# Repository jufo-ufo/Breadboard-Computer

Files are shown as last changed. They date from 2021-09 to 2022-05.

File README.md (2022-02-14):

# Breadboard-Computer
Let's build a computer from ICs!

## TODO
- [X] Test out NAND vs NOT, AND, OR
- [X] Write specification for V0.4
  - [X] Add Instructionset to "Handbuch"
  - [X] Rework Interrupts
  - [X] I/O specification
  - [X] Update Flags
  - [X] ~~Insert test results~~
- [X] Get familiar with ~~EAGLE/Target3001~~ Kicad/Logisim
- [ ] Build circuit designs

| Part | Logic | Schematic | Layout | Breadboard | Etching | Soldering | Etcher | Documenation | Comment
|---|---|---|---|---|---|---|---|---|---
| Bank | [X] | [X] | [ ] | [ ] | [ ] | [ ] | | [ ] | 
| Bank\_controller | [X] | [X] | [ ] | [ ] | [ ] | [ ] | | [ ] |
| Memory | [X] | [X] | [X] | [ ] | [ ] | [ ] | | [ ] | 
| Register\_File | [X] | [X] | [ ] | [ ] | [ ] | [ ] | | [ ] | 
| ALU | [X] | [X] | [ ] | [ ] | [ ] | [ ] | | [ ] | 
| IV\_Storage | [X] | [ ] | [ ] | [ ] | [ ] | [ ] | | [ ] | 
| Interrupt\_Controller | [ ] | [ ] | [ ] | [ ] | [ ] | [ ] | | [ ] | 
| Timer | [X] | [ ] | [ ] | [ ] | [ ] | [ ] | | [ ] | 
| Freq\_Counter | [X] | [ ] | [ ] | [ ] | [ ] | [ ] | | [ ] | 
| Instruction\_Decoder  | [X] | [ ] | [ ] | [ ] | [ ] | [ ] | | [ ] | 
| IO\_Controller | [ ] | [ ] | [ ] | [ ] | [ ] | [ ] | | [ ] | 
| Activation\_Module | [X] | [X] | [X] | [X] | [ ] x7  | [ ] x7 | | [ ] | 
| Dual\_Register | [X] | [X] | [X] | [X] | [ ] x2  | [ ] x2 | | [ ] | Replacement for BID-Regiser and IR
https://www.youtube.com/watch?v=9aUsTlBjspE

## TODO for Presentation
| Module | Logic | Schematic | Layout | Breaboard | DIY Etching | Soldering | Comment
|---|---|---|---|---|---|---|---
| Activation Module x4 | [X] | [X] | [X] | | | [ ] |
| Register File | [X] | [X] | [ ] | | | [ ] |
| ALU | [X] | [ ] | | [ ] | | |
| Dual Register | [X] | [X] | [X] | | [X] | [ ] |
| Memory | [X] | [X] | [X] | | | [ ] |
| Instruction Decoader | [X] | | | [ ] | | | No Schematic need, due unstable design
| IO-Controller | [X] | | | [ ] | | | No Schematic need, has to be build spontainiously

## Was macht unseren Computer besonders?

- Modular: Die Funktionialiät des Computer kann erweitern werden indem neues einfach eingesteckt wird
- 2 Bus-Architektur: Efficenter
- IO-System sehr vielfältig: bis zu 2^16 IO-Geräte
- Wäre der Laufzeit anpassbares Instruktions Satz (kommt noch)
- Keine Softwareverwaltes Berechtigungs System: Supervisor/Usermode

=> Sehr einfache Anpassbarkeit und Optimierung auf Verschieden Zenarien

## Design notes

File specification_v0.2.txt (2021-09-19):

================ Register ================

0 : ZERO : Contains const 0x0
1 : IP   : Current Address for instruction to be executed
2 : SP   : Address to the to of the Stack
3 : A    : General purpose
4 : B    :      ...
5 : C    :      ...
6 : D    :      ...
7 : FLAG : Stores the flags

================ Memory  ================

Data Length    : 16 bit
Address Length : 16 bit

 w (word)      = 2  B (byte)
kw (kilo word) = 2 kB (kilo byte)

                     Size:
0x0000 +-------------+
       | ROM         |  16384 w = 16.0 kw
       |             |
       | Supervisor  |
0x4000 +-------------+
       | RAM         |  18431 w = 18.4 kw
       | (Bank 1)    |
       | INS         |
       | 0x4800      |
       |          /\ |   
       | STACK    || |
0x5800 +-------------+
       | RAM         |  18431 w = 18.4 kw
       | (Bank 2)    |
       |             |
       | Optional    |
       | Data        |
0xd000 +-------------+
       | RAM         |  12287  w = 12.3 kw
       | Supervisor  |
       |             |  
       |          /\ |
       | STACK    || |
0xffff +-------------+

================ flags ================

The flags are stored in the FLAG Register
Every Flag corresponds to one flag

 0 : Overflow (of)   : set if an calculation results in an intager overflow
 1 : Equale (e)      : set if both input values to TEST are the same
 2 : Greater (g)     : set if the first value to TEST is greate then the second value
 3 : Smaller (s)     : set if the first value to TEST is smaller then the second value
 4 : IO-Pluged (p)   : set if the first value  to TEST is an pluged in IO-Devices
 5 : Supervisor (sop) : set if supervisor mode is enable
 6 :
 7 :
 8 :
 9 :
10 : 
11 :
12 :
13 :
14 :
15 :

================ Input & Output ================

There are two function for IO Manipulation:
IN  : for reading data from an IO devices
OUT : for writing data to an IO devices

Every IO - Devices has an IO-ID
This IO-ID works like an address for memory

An maps as follows:

       +----------------------------+
0x0000 | 1. IN  : IO-ID             | 
       | 2. OUT : Type of IO-Device |
       +----------------------------+
0x0001 | Interrupt Source           |
       +----------------------------+
0x0002 | Interrupt ID               |
       +----------------------------+
       | Every exsiting IO-Device   |
0xffff +----------------------------+

Slot 0 maps to IO-ID 0x0003
Slot 1 maps to IO-ID 0x0004
 ...
Slot n maps to IO-ID n+3

There exsists a flag if an device is pluged in

================ Interupts ================

On Interupt the Supervisor flag is set and the processor executes the instruction at IV.
After that the processor executes at the position of IP.

IV is set by physikal dip-switches on the processor cases. It's advives to set the IV to
0x3fff and put there an CALL instruction to preserv the old IP

Interupts can be trigger
	- by IO-Devices
	- by INT Instruction

By Reading from IO-ID 0x0001 the source of the interrupt can be optainted.
And Interrupt Sourece of 0x0000 means the interrupt was cause by an INT instruction
Any Interrupt Source higher then 0x0002 means that the interrupt was cause by the
corresponding IO - Devices

================ Instruction Set ================

NOP : No operatation

------ ALU ------
MOV  <reg> <reg/const>       : Move
ADD  <reg> <reg> <reg/const> : Add
SUB  <reg> <reg> <reg/const> : Subtracted
MUL? <reg> <reg> <reg/const> : Mulitply
DIV? <reg> <reg> <reg/const> : Divide
XOR  <reg> <reg> <reg/const> : Bitwise Exclusive Or
AND  <reg> <reg> <reg/const> : Bitwise And
OR   <reg> <reg> <reg/const> : Bitwise Or
NOT  <reg> <reg>             : Bitwise Not

------ Memory ------
STR  <reg (data)> <reg/const (addr)> : Store to Memory
LD   <reg (data)> <reg/const (addr)> : Load from Memory
BNK1 <reg/const>                     : maps Bank Slot 1 to BID
BNK2 <reg/const>                     : maps Bank Slot 2 to BID
------ Stack -------
PUSH <reg/const> : push one value to stack
POP  <reg>       : remove value from stack
PEEK <reg>       : get value from stack without removing it
CALL <reg/const> : push current PC to stack and jump to address
RET              : remove value from stack and jump to it

------- Conditional ------
TEST <reg> <reg/const> : Comparse two values and sets/unsets flags
JE   <reg/const>       : jump if flag equal is set
JO   <reg/const>       : jump if flag overflow is set
JG   <reg/const>       : jump if flag greater is set
JS   <reg/const>       : jump if flag smaller is set
JP   <reg/const>       : jump if flag IO-Pluged is set

For evey conditional jump there is an inverted form
by setting one bit and adding an N in the instruct like
JNE = Jump if flag equal is not set

------- IO -------
IN  <reg/const (data)> <reg (IO-ID)> : Reads value from IO-Devices
OUT <reg/const (data)> <reg (IO-ID)> : Writes value to IO-Devices
IM  <reg/const (data)> <reg (IO-ID)> : Reads value from IO-Devices to Memory 
OM  <reg/const (data)> <reg (IO-ID)> : Write value from Memory to IO-Devices

------- Intreupts ------
INT : Triggers an Interupt

================ Instruction Encoding ================

reg   :  3 bit x 2
const : 16 bit
ins   : 10 bit
----------------
total : 32 (max)   

+-----+-----+-------+-------+-------+--------+
| ins | rcm | reg1  | reg2  | reg3  | Empty  |
| 0-8 |   9 | 10-12 | 13-15 | 16-18 | 19-31  |
+-----+-----+-------+-------+-------+--------+
                            |      const     |
                            |      16-31     |
                            +----------------+

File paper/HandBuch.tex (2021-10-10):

\documentclass{scrartcl}

\usepackage{graphicx}
\usepackage[siunitx, RPvoltages, european]{circuitikz}

\usepackage[ngerman]{babel}
\usepackage[utf8]{inputenc}
\usepackage{amsmath}
\usepackage[T1]{fontenc}
\usepackage{xcolor}
\usepackage{tikz}
\usepackage[breaklinks=true]{hyperref}
\usepackage[utf8]{inputenc}
\usepackage[babel,german=quotes]{csquotes}
\usepackage[style=numeric, backend=biber]{biblatex}
\usepackage{listings}
\usepackage{bytefield}
\usepackage{longtable}

\lstdefinestyle{asm}{
}

\addbibresource{ref.bib}

\graphicspath{ {../images} }

\KOMAoptions{parskip=full}

\begin{document}

\title{Platinencomputer - Handbuch}
\author{Alexander Wersching und Simon Walter}
\date{2021}
\maketitle
\newpage

\tableofcontents
\newpage

\section{Anforderungen und Methode}

\section{Spezifikation des Computers}
Eine Computer hat eine Reihe verschiedener high-level Aufgaben und Features, die es ihm erlauben seiner Tätigkeiten nach zu gehen! 
Diese Features können wie folgt auf gegliedert werden: Register, Memory, Banking, Input/Output, Flaggen, Hardware Stack, Interrupts, Supervisor-Mode und das Instructuion Set.

Aber um zuerst ein paar Standarts festzulegen: der Computer hat eine Daten/Adressen Länge von 16 bit, d.h. er kann maximal 16 bit auf einmal operieren bzw. können maximal 16 bit an Daten/Adressen im Computer auf einmal bewegt werden. Mehr dazu in \autoref{section:comment:datalength}

\subsection{Registers}
Register sind kleine sehr schnelle Speichereinheiten, die genutzt werden können um Zwischenergebnisse, lokal Variablen, Argumenten für Funktionen zu speichern oder um Daten im Computer zwischen den einzelnen Komponenten zu verschieben. Aus jedem Register kann \emph{gelesen} (\emph{Kopierten} des alten Wertes an eine anderen Ort) oder \emph{geschrieben} werden (den alten Wert mit einem neuen Wert \emph{überschreiben})

Der Computers besitzt bei uns $8$ verschiedene, jeweils $16$ bit lange Register. Jedes Register hat dabei eine eigene Registernumber (= RN). Machen Register erfüllen zudem noch spezielle Aufgaben und sollten auch nur so verwendet werden. Diese Funktionen sind in \autoref{table:register} zu sehen.

Mehr zur Registeranzahl in \autoref{section:comment:register_number}

\begin{center}
	\begin{table}[h]
		\caption{\label{table:register} Registeraufteilung}
		\begin{tabular}{l | l | l}
			RN & Name & Funktion\\
			\hline
			$0$ & ZERO & Konstante $0\text{x}0000$; Schreiben hat keinen Effekt\\
			$1$ & IP & Instruction Pointer, zeigt auf aktuell auszuführende Instruktion\\
			$2$ & SP & Stack Pointer, zeigt auf obersten Wert des Stacks, siehe \ref{section:stack} \\
			$3$ & A & Allzweck Register ohne besonderen Aufgaben \\
			$4$ & B & " \\
			$5$ & C & " \\
			$6$ & D & " \\
			$7$ & FLAG & Enthält alle wichtigen Flaggen, siehe \autoref{section:flags} \\
		\end{tabular}
	\end{table}
\end{center}

Die Register A-D sind dabei die Register, welche frei für jede Nutzung zur Verfügung stehen. Es ist \emph{stark zu empfehlen} die spezialregister (ZERO, IP, SP und FLAG) \emph{nicht} für die Speicherung von Daten zu verwenden, da dies evt. Programmabläufe stark stören könnte. Sie sind ausdrücklich nur für ihre zugewiesenen Aufgaben da.

\subsubsection{\label{section:flags}Flaggen}

Das Register FLAG enthält alle Statusflaggen. Eine Flagge kann entweder gesetzt oder nicht gesetzt sein, daher kann jede Flagge als ein Bit repräsentiert werden. Jedes Bit in FLAG stellt daher eine Flagge da. Flaggen werden bei unterschiedlichen Ereignissen geschaltet. Dies und welche Flaggen es gibt ist in \autoref{table:flag} zusehen

\begin{center}
	\begin{table}[h]
		\caption{\label{table:flag}Flaggenaufteilung in FLAG}
		\begin{tabular}{l | l | l | l}
			Bit & Name & Funktion & Schaltung \\
			\hline
			 0 & OF  & Intager Overflow einer Rechenoperation & Bei jeder ALU Operation\\
			 1 & E   & Gleichheit zweier Werte & TEST arg[0] = arg[1]\\
			 2 & G   & Ungleicheit ($>$) zweier Werte & TEST arg[0] > arg[1]\\
			 3 & L   & Ungleicheit ($<$) zweier Werte & TEST arg[0] < arg[0]\\
			 4 &  &  &  \\
			 5 &  &  &  \\
			 6 &  &  &  \\
			 7 &  &  &  \\
			 8 &  &  &  \\
			 9 &  &  &  \\
			10 &  &  &  \\
			11 &  &  &  \\
			12 &  &  &  \\
			13 &  &  &  \\
			14 &  &  &  \\
			15 & OINT & Overwride Interruption, siehe \autoref{section:interrupts} &  \\
			15 & SUP & Supervisor-/Usermode & siehe \autoref{section:interrupts} 
		\end{tabular}
	\end{table}
\end{center}

Alle Flaggen, die mit TEST als Schaltung gekennzeichnet werden, werden bei der Ausführung der TEST Operation geschaltet.

Das FLAG Register verhält sich ebenfalls wie ein Register, daher können Flagge auch per Hand gesetzt oder nicht gesetzt werden. Eine Ausnahme macht SUP die nur manuel geschaltet werden kann wenn SUP gesetzt ist, siehe \autoref{section:supervisor}

\subsection{\label{section:memory}Memory}

Während die Register für lokale Variablen und Zwischenergebnisse gedacht sind, ist Memory (Arbeitsspeicher) für die Speicherung von größeren Datenmengen gedacht.

Es ist in 65536 einzelne und unabhängige Speicherzellen (Jede 16 bit große) aufgeteilt. Jeder Zelle ist einer Addresse, welche von 0 bis 65535 reicht, zugeordnet. Der Computer kann damit auf $65536 \text{words}$ oder $131072 \text{bytes}$ ($\approx 131.0 \text{kb}$) gleichzeitig zugreifen.
\footnote{Die Größe messen wir in words (w) oder in kilowords (kw), wobei $1 \text{word} = 2 \text{bytes} = 16 \text{bit}$.}. Wichtig ist das die Gesamt Größe theoretisch weitaus größer sein kann, dank Banking siehe \autoref{section:banking}.

Memory wird dabei über LD- und STR-Instruktionen gesteuert. Die LD-Instruktion kopiert einen Wert aus Memory und schreibt ihn in ein Register, während STR an der angebenen Addresse den Wert mit dem eines Register überschreibt.

Dabei ist die Memory Karte in \autoref{fig:memoryMap} zu stehen. Die zwei Hardware Stacks sind dort gekenzeichnet mit $\uparrow$, mehr dazu in \autoref{section:stack}

Die mit Supervisor gekennzeichneten Bereich können nur dann gelesen oder geschrieben werden, wenn die SUP Flagge gesetzt ist. Der Bereich, der mit ROM versehen wurde, ist dabei nicht beschreibbar, sondern kann nur gelesen werden. Eine STR Instruktion hat keine Wirkung.

\begin{figure}[h]
	\centering
	\caption{Memory Karte}
	\label{fig:memoryMap}
	\begin{bytefield}[leftcurly=., rightcurly=., leftcurlyspace=0pt, rightcurlyspace=0pt]{16}
		
		\begin{leftwordgroup}{\small \texttt{0x0000}}
			\bitbox[lrt]{16}{}
		\end{leftwordgroup}\\
		\wordbox[lr]{2}{ROM Supervisor\\$16384 \text{w} \approx 16.3 \text{kw}$} \\
		\begin{leftwordgroup}{\small \texttt{0x3fff}}
			\bitbox[lr]{16}{}
		\end{leftwordgroup}\\

		\begin{leftwordgroup}{\small \texttt{0x4000}}
			\bitbox[lrt]{16}{}
		\end{leftwordgroup}\\
		\begin{rightwordgroup}{\large $\uparrow$ User Stack}
			\wordbox[lr]{3}{RAM (Bank Slot 1)\\$18431 \text{w} \approx 18.4 \text{kw}$} \\
		\end{rightwordgroup}
		\begin{leftwordgroup}{\small \texttt{0x57ff}}
			\bitbox[lr]{16}{}
		\end{leftwordgroup}\\

		\begin{leftwordgroup}{\small \texttt{0x5800}}
			\bitbox[lrt]{16}{}
		\end{leftwordgroup}\\
		\wordbox[lr]{3}{RAM (Bank Slot 2)\\$18431 \text{w} \approx 18.4 \text{kw}$} \\
		\begin{leftwordgroup}{\small \texttt{0xcfff}}
			\bitbox[lr]{16}{}
		\end{leftwordgroup}\\

		\begin{leftwordgroup}{\small \texttt{0xd000}}
			\bitbox[lrt]{16}{}
		\end{leftwordgroup}\\
		\begin{rightwordgroup}{\large $\uparrow$ Supervisor Stack}
			\wordbox[lr]{2}{RAM Supervisor\\$12287 \text{w} \approx 12.3 \text{kw}$} \\
		\end{rightwordgroup}
		\begin{leftwordgroup}{\small \texttt{0xffff}}
			\bitbox[lrb]{16}{}
		\end{leftwordgroup}

	\end{bytefield}
	
\end{figure}

\subsubsection{\label{section:banking}Banking}

Banken sind externe Memory Module, die eingesteckt werden können. Alle Banken sind gleich groß ($~18.4\text{kw} = 36.8\text{kb}$) und der Computer unterstützt maximal $65536$ unterschiedliche Banken. Jede Bank hat dabei eine ID (BID), die von $0$ bis $65535$ reicht.

Der Computer hat zwei Bank-Slots (Slot 1 \texttt{0x4000 - 0x3fff} und Slot 2 \texttt{0x4000 - 0x57ff}). Er kann nun auf jenden dieser Slots eine der theoretisch $65536$ Bank legen
\footnote{Es ist dabei möglich die gleiche Bank auf beide Slots zu legen, auch wenn das nur bedingt nützlich ist.}. Das Banken legen lässt sich über die SBK1- (Select Bank 1) und SBK2- (Select Bank 2) Instruktion erreichen.
Wenn man somit an diese entsprechende Memory Addressen schreibt, schreibt man in die Bank hinein.

Durch dieses System lassen sich $65536 * ~18.4\text{kw} = 1.2\text{Gw} = 2.4\text{GB}$ ansprechen.

Das Bankensystem dient zudem dazu Prozesse von einander zu isolieren, da bei nicht gesetzter SUP-Flagge Computer die Bank nicht änderen kann, siehe \autoref{section:supervisor}.

\subsubsection{\label{section:stack}Hardware Stack}

Der Stack (oder auch Stapelspeicher) ist eine LIFO (Last In First Out) Datenstruktur. Sie dient hauptsächlich dazu Subroutinen zu verwalten. 

Er funktioniert dabei wie ein Münztappel. Es kann ein Wert auf den Stack gelegt werden (PUSH-Instruktion) oder ein Wert von oben abgehoben werden (POP-Instruktion).

Der Stack liegt dabei physisch in Memory vor. Jedes Element des Stacks okkupiert dabei eine Memoryzelle. Das Stack-Point Register-(SP) hält die Addresse, welche auf den oberste Wert des Stacks zeigt. Der Stack wächst dabei von hohen Addressen zu niedrigen Addressen. PUSH entspricht dabei der Dekrementierung des Stack Pointers um $1$ und POP der Inkrementierung um $1$.

Fundamental hat der Computer zwei Stacks. Der Supervisor-Stack beginnt bei \texttt{0xffff} und wird genutzt wenn die SUP Flagge gesetzt ist. Der User-Stack beginnt bei \texttt{0x57ff}, also am Ende des Bank-Slots 1 und wird genutzt, wenn die SUP Flagge nicht gesetzt ist.

POP und PUSH schalten automatisch zwischen Supervisor-Stack und User-Stack bei Änderung der SUP-Flagge.

\subsection{\label{section:io}Input/Output}

Der Computer hat zudem die Möglichkeit mit verschieden IO-Geräte zu interagieren.
Die Komunikation läuft über die sogenannten IO-Ports.
Der Computer hat physische Anschlüsse an denen IO-Geräte angesteckt werden können.
Die Struktur dieser Anschlüsse sieht wir folgt aus:

\begin{center}
	\begin{table}[h]
		\caption{\label{table:IOPins}}
		\begin{tabular}{l | l}
			\# & Funktion \\
			\hline
			00 & GND \\
			01 & Vcc \\
			02-17 & 16Bit Daten \\
			18 & Iin-Enable \\
			19 & Din-Enable \\
			20 & Dout-Enable \\
			21 & Clock
 		\end{tabular}
	\end{table}
\end{center}

Dabei bekommt jedes IO-Gerät eine eigene ID (IO-ID), welche im Bereich von $0$ bis $65535$ liegen darf, wobei davon aufgrund von physikalischen beschränkungen vermutlich nur die ersten -zig verwendet werden.
Die Interaktion funktioniert dabei über drei Instruktionen:

\begin{center}
	\begin{table}[h]
		\caption{\label{table:IOInstructions}}
		\begin{tabular}{r | r | l}
			kurzform & Ausgeschrieben & funktion \\
			\hline
			Iin & Instruktion Eingang & Computer schreibt eine Instruktion ans I/O-Gerät \\
			Din & Daten Eingang & Computer schreibt 16-Bit Daten ans I/O-Gerät \\
			Dout &  Daten Output & Computer liest 16-Bit Daten vom I/O-Gerät
 		\end{tabular}
	\end{table}
\end{center}

Jede Interaktion benötigt dabei mehrere Schritte, die genaue Definition der Kommunikationsschritte wird dabei durch jede instruktion eigen festgelegt.
Ein allgemeiner standart Ablauf (wie z.B. der der später definierten IO-Instruktion "rmn") sieht wir folgt aus:

\begin{center}
	\begin{table}[h]
		\caption{\label{table:IO_Schem}}
		\begin{tabular}{l | l | l | l | l | l | l}
			 Bereich & Instr 1 & Instr 2 & ... & Instr n & Instr $n+1$ & ... \\
			\hline
			Iin & 1 & 0 &   & 0 & \\
			Din & 0 & 1 &   & 0 & \\
			Dout & 0 & 0 &   & 1 & \\
			Data$0-7$ & InstructionID & Variable &   & Rückgabewert & Rückgabewert \\
			Data$8-15$ & 8b Variable & Variable &   & Rückgabewert & Rückgabewert
 		\end{tabular}
	\end{table}
\end{center}

Die Pins Iin und Din werden dabei durch den Computer für einen Clock-Tick gesetzt, sobald die Daten/Instruktionsinformationen am Dateneingang an liegen; der Dout Pin wird durch das I/O-Gerät selbst gesetzt, sobald dieses seinerseits die Rückgabeinformation auf die Daten-pins anlegt.
Das setzen des Dout-pins wird vom Computer als Interupt( \autoref{section:interrupts}) bearbeitet.
Der fall, dass gleichzeitig der Computer und das I/O-Gerät die Datenpins versuchen zu beschreiben wird dadurch gelöst, dass meinstens die instruktionen definieren, wann das I/O-Gerät schreiben darf. Bei geräten, wie z.B. Peripherie-Geräten, die standartmäßig schreiben dürfen sollen ist von dem I/O-Gerät der Dout-pin schon eine Instruktion vor beginn des beschreibens des auf den Daten-pins zu setzen.

Berechtigungen: der Supervisor-mode hat die berechtigungen zu allen I/O-Interaktionen, für normale prozesse wird die Berechtigungsliste in einer reihe an RAM-chips gespeichert, deren Addressen sich mit dem wechseln zwischen den verschiedenen Banks ändern.
gesetzt werden können sie nur durch den Supervisor, wobei auch dieser die RAM-Addressen nicht manuel ändern kann (\autoref{section:insSet})

die Momentan bestehenden I/O-Instruktionen sind die folgenden, aber diese sind im Programm frei veränderlich, solange das externe Gerät die gleiche Interpretation der Anweisungen hat.

\begin{center}
	\begin{longtable}{p{0.045\textwidth} | p{0.1\textwidth} | p{0.1\textwidth} | p{0.40\textwidth} | p{0.22\textwidth}}[h]
	\kill
		\caption{\label{table:IOins}I/O-Instruktionen}
		\endhead
			ID & Gerätetyp & Name & Funktion & Verhalten \\
			\hline
			 $0\text{x}00$ & All & ls & gibt alle normalen Funktionen des Geräts zurück & Iin; n$*$Dout\\
			\hline
			 $0\text{x}01$ & All  & ll & gibt ALLE (auch die, die man nicht verwenden sollte) Funktionen zurück & Iin(Instruktion); n$*$Dout(Antworten)\\
			\hline
			 $0\text{x}02$ & Drive & rsn (read singel normal) & Lesen eines einzelnen 16-Bit werts von einer 24-Bit Addresse & Iin(Instruktion); Din(Addresse); 1$*$Dout(Antwort) \\
			\hline
			 $0\text{x}03$ & Drive & rmn (read multiple normal) & Lesen einer reihe an 16-Bit werten von 24-Bit Addressen aus & Iin(Instruktion); Din(startAddresse); Din(Länge); n$*$Dout(Antworten) \\
			\hline
			 $0\text{x}04$ & Drive & wsn (write singel normal) & Schreiben eines einzelnen 16-Bit werts von einer 24-Bit Addresse & Iin(Instruktion); Din(Addresse); Din(Daten); Dout(bestätigung) \\
			\hline
			 $0\text{x}05$ & Drive & wmn (write multiple normal) & Schreiben einer reihe an 16-Bit werten an 24-Bit Addressen & Iin(Instruktion); Din(startAddresse); n$*$Din(Daten); Dout(bestätigung) \\
			\hline
			 $0\text{x}06$ & Drive & rsb (singel read big) & Lesen eines einzelnen 16-Bit werts von einer 40-Bit Addresse & Iin(Instruktion); Din(Addresse); Din(Addresse); 1$*$Dout(Antwort) \\
			\hline
			 $0\text{x}07$ & Drive & rmb (multiple write big) & Lesen einer reihe an 16-Bit werten von 40-Bit Addressen aus & Iin(Instruktion); Din(startAddresse); Din(startAddresse2); Din(Länge); n$*$Dout(Antworten) \\
			\hline
			 $0\text{x}08$ & Drive & wmb (singel write big) & Schreiben eines einzelnen 16-Bit werts von einer 40-Bit Addresse & Iin(Instruktion); Din(Addresse); Din(Addresse);Din(Daten); 1$*$Dout(bestätigung) \\
			\hline
			 $0\text{x}09$ & Drive & wmb (write multiple big) & Schreiben einer reihe an 16-Bit werten an 40-Bit Addressen & Iin(Instruktion); Din(startAddresse); n$*$Din(Daten); Dout(bestätigung) \\
			\hline
			 $0\text{x}0a$ & Drive & rfn (read file normal) & Lesen einer gesamten Datei (24-bit Namen)  & Iin(Instruction); Din(Name); n$*$Dout(Antwort) \\
			\hline
			 $0\text{x}0b$ & Drive & wfn (write file normal) & Schreiben einer neuen Datei (24-bit Namen) & Iin(instruction); Din(Name); n$*$Din(daten); Dout(bestätigung) \\
			\hline
			 $0\text{x}0c$ & Drive & rfpb (read file-part big) & Lesen eines teils einer Datei (24-bit Namen) & Iin(instruction); Din(Name); 2$*$Din(läge); n$*$Dout(Daten) \\
			\hline
			 $0\text{x}0d$ & Drive & wfpb (write file-part big) & Anhängen von Daten an eine Datei(24-bit Namen) & Iin(instruction); Din(Name); Din(länge); n$*$Din(Daten); Dout(bestätigung) \\
			\hline
			 $0\text{x}0e$ &  & & & \\
			\hline
			 $0\text{x}0f$ &  & & &

	\end{longtable}
\end{center}

\subsection{\label{section:interrupts}Interrupts}

Interrupts sind Unterbrechungen im Programmablauf. Wenn ein Interrupt meldet wird. Wird dieser im nächsten Instruktions-Zyklus bearbeitet. Für diesen Zyklus, wird, je nach Interrupt-Quelle, nicht die Instruktion ander Stelle von IP sondern von IV (Interrupt Vektor) geladen.

Alle Interrupts werden blockiert wenn die OINT Flagge gesetzt ist. Blockiert heißt dabei das alle Interrupts nicht behandelt werden. Diese Flagge kann nur gesetzt werden wenn sicher der Computer im Supervisormode befindet.

Wir unterscheiden dabei zwischen drei verschiedenen Interrupt-Quelle, wobei jede Quelle einen eigenen IV hat, wie in \autoref{table:iv}

\begin{center}	
	\begin{table}[h]
		\caption{\label{table:iv}}
		\begin{tabular}{l | l l}
			Interrupt-Quelle & IV Name & IV Standard Wert \\
			\hline
			IO-Interrupts & IV-IO & $0\texttt{x}0000$ \\
			INT-Instruktion & IV-INT & $0\texttt{x}0000$ \\
			Timed-Interrupts & IV-TI & $0\texttt{x}0000$ \\
		\end{tabular}
	\end{table}
\end{center}

\subsubsection{Timed-Interrupts}

Der Timed-Intrrupt funktioniert wie ein Wecker. Nachdem Ausführen der STI (Set Timed Interrupt) Instruktion, wird nach angebender Anzahl an ausgeführten Instruktion ein Intrrupt ausgelöst. So 
würde \texttt{STI 0x00ff} in 256 Instruktion einen Interrupt auslösen. Wenn ein Timed-Interrupt mit der Zeit \texttt{0x0000} gesetzt wird, so wird der Timed-Intrrupt deaktiviert.

\subsubsection{IO-Interrupts}

\subsection{\label{section:supervisor}Supervisor-/Usermode}

REWORK

\subsection{\label{section:insSet}Instruktions-Satz}

Alle zuverfügenung stehenden Instruktion sind in \autoref{table:instructions}. Die Ins-ID, steht für Instruktions-ID, welecher jeder Instruktion eine zugeordnet ist. op1, op2 und op3 sind dabei die möglich parameter der Instruktion. Sie können dabei Register (reg1, reg2 oder reg3) sein oder ein Konstante (c).

\begin{center}
	\begin{table*}
		\caption{\label{table:instructions}Instruktions-Satz}
		\begin{tabular}{l | l l l l | l}
			Ins-ID & Name & op1 & op2 & op3 & Beschreibung \\
			\hline
			\texttt{0x00} & NOP  &  &  &  & Kein Effekt  \\
			\hline
			\texttt{0x01} & MOV  & reg1 & reg2/c &  & reg1 $=$ reg2/c\\
			\texttt{0x02} & ADD  & reg1 & reg2 & reg3/c & reg1 $=$ reg2 $+$ reg3/c \\
			\texttt{0x03} & SUB  & reg1 & reg2 & reg3/c & reg1 $=$ reg2 $-$ reg3/c \\
			\texttt{0x04} & MUL? & reg1 & reg2 & reg3/c & reg1 $=$ reg2 $*$ reg3/c \\
			\texttt{0x05} & DIV? & reg1 & reg2 & reg3/c & reg1 $=$ reg2 $/$ reg3/c \\
			\texttt{0x06} & XOR  & reg1 & reg2 & reg3/c & reg1 $=$ reg2 $\oplus$ reg3/c \\
			\texttt{0x07} & AND  & reg1 & reg2 & reg3/c & reg1 $=$ reg2 $\land$ reg3/c \\
			\texttt{0x08} & OR   & reg1 & reg2 & reg3/c & reg1 $=$ reg2 $\lor$ reg3/c \\
			\texttt{0x09} & NOT  & reg1 & reg2/c &      & reg1 $=$ $\lnot$reg2/c \\
			\hline 
			\texttt{0x0a} & STR  & reg1 & reg2 & reg3/c & memory[reg2 + reg3/c] = reg1  \\
			\texttt{0x0b} & LD   & reg1 & reg2 & reg3/c & reg1 = memory[reg2 + reg3/c] \\
			\texttt{0x0c} & BNK1 & reg1/c &  &  & Setzt BID für Bank-Slot1 \\
			\texttt{0x0d} & BNK2 & reg1/c &  &  & Setzt BID für Bank-Slot2 \\
			\hline
			\texttt{0x0e} & PUSH & reg1/c &  &  & SP--; memory[SP] = reg1 \\
			\texttt{0x0f} & POP  & reg1 &  &  & reg1 = memory[SP]; SP++ \\
			\texttt{0x10} & PEEK & reg1 &  &  & reg1 = memory[SP] \\
			\texttt{0x11} & CALL & reg1/c &  &  & \vtop{
				\hbox{\strut memory[SP] = IP; SP++;}
				\hbox{\strut IP = reg1/c}} \\
			\texttt{0x1b} & RET  &  &  &  & IP = memory[SP]; SP++ \\
			\hline
			\texttt{0x12} & TEST & reg1 & reg2/c &  & Vergleicht reg1 und reg2/c \\
			\texttt{0x13} & JE   & reg1/c &  &  & IP = reg1/c if E \\
			\texttt{0x14} & JO   & reg1/c &  &  & IP = reg1/c if O \\
			\texttt{0x15} & JG   & reg1/c &  &  & IP = reg1/c if G \\
			\texttt{0x16} & JL   & reg1/c &  &  & IP = reg1/c if L \\
			\hline
			\texttt{0x17} & IN   & reg1 & reg2 &  & reg1 = IO[reg2] \\
			\texttt{0x18} & OUT  & reg1/c & reg2 &  & IO[reg2] = reg1/c \\
			\texttt{0x19} & AIO  & reg1 &  &  & Aktiviert IO[reg1] \\
			\texttt{0x1a} & DIO  & reg1 &  &  & Deaktivieren IO[reg1] \\
			\texttt{0x1b} & TYPE & reg1 & reg2 &  & reg1 = Type von IO[reg2] \\
			\hline
			\texttt{0x1c} & INT  & & & & Löst einen Interrupt aus \\
			\texttt{0x1d} & STI  & reg1/c & & & Setzt Timed Interrupt für reg1/c \\
			\hline
		\end{tabular}
	\end{table*}
\end{center}

\section{Kommentar zur Specification}

\subsection{\label{section:comment:datalength}16 bit Daten/Address Länge}

Die Address- und Datenlänge besagt viele Binäre Ziffern (bits) für eine Address und Daten verwendet werden. Je mehr Ziffern man verwendet desto größere Zahlen können in einer Operation verarbeitet werden wobei die maximal repräsentierbare Zahle $2^n - 1$ ist wenn $n$ die Anzahl der Binary Ziffern (= Bits) ist und wenn man mit $0$ anfängt zu zählen. Sie \autoref{table:max_zahlen}

Ein eine $n$ stellige Binär Zahl wobei $n$ teilbar durch $8$ ist, ist dabei relative angenehm, $8$ bit = $1$ byte. Das byte ist dabei die Basis Einheit für so gut wie alle informationstechnischen Standards. Daher ist es gute eine solches $n$ zu wählen.
Zudem kommen einige elementar ICs, z.B. Buffer oder Register, immer mit 8 bits.

Jedoch gilt je mehr Bits man verwendet, desto mehr Schaltung brauchen man, desto mehr Stromverbrauch. Da wir wie zwar nicht speziell auf Platz und Stromverbrauch optimieren, aber trozdem ein limitiertes Buget haben, können wir auch nicht eine belibig große Daten/Address Länge wählen.

Wir haben uns daher für $16$ bit entschieden, der Codea man laut \autoref{table:max_zahlen} Zahlen bis zwischen $0$ und $65535$ darstellen kann. Diese Menge ist gerade große genug, um für die meisten Programme große genüge Zahl abzubilden
\footnote{Für Programme die Zahlen welche $> 65535$ darstellen wohlen ist es ratsam immer zwei oder mehr Spreichereinheiten zunehmen oder bei Berechnungen, selbige auf zwei oder mehr Schritte auf zuteilen}.

Die Entscheidung zur größe der Daten/Address Länge ist eine sehr ausschlag gebende, daher haben wir diese zuerst festgelegt. Sie wird für viele weitere Entscheidung eine wichtige Rolle spielen. Wichtig ist nur das wir maximal $65536$ Zustände oder Zahlen von $0$ bis $65535$ darstellen können mit unseren $16$ bit

\begin{center}
	\begin{table}[h]
		\caption{\label{table:max_zahlen} Maximalerepersäntierbare Zahlen (startend mit 0)}
		\begin{tabular}{ l | l }
 		$n$ & $n^2 - 1$ \\
		\hline 
		2 & 3\\  
		4 & 15\\
		8 & 255\\
		16 & 65535\\
 		32 & 4294967295\\
 		64 & 18446744073709551615\\
		\end{tabular}
	\end{table}
\end{center}

\subsection{\label{section:comment:register_number}Register Anzahl}

Der Computer hat 8 Register. Wir haben uns für Acht ausfolgenden Gründen entschieden:
Zu erst die minimale Anzahl anregisteren die wirklich gebraucht würde, ist $5$! Man braucht mindestens zwei all Zweck Register um binäre Rechenoperation durch zu führen, einen Stackpointer, einen Instruktion Point und einen Ort wo man die Flaggen speichern kann
\footnote{Theorthisch ist es möglich das Flaggen Register wegzulassen, wir haben uns aber für eine solches Register entschieden siehe \autoref{com:conditionals}}.

Fünf lässt sich nicht mehr mit $2$ bits repräsentieren ($2^2 = 4$), daher muss man $3$ bit ($2^2 = 8$) nehmen. Der Grund warum wir nicht mehr genomen haben hat mit der Encodierung von Instruktionen zutun siehe \autoref{com:insEnc}. Somit haben sich $8$ Register als das Optimum ergeben

\subsection{\label{com:insEnc}Alternative Instruktion Encodierung}

\section{\label{section:security}}

\section{Quellenverzeichnis}

\printbibliography{}

\end{document}

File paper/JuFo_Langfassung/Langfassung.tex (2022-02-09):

\documentclass{scrartcl}

\usepackage{graphicx}
\usepackage[siunitx, RPvoltages, european]{circuitikz}

\usepackage{chemformula}
\usepackage[ngerman]{babel}
\usepackage[utf8]{inputenc}
\usepackage{amsmath}
\usepackage{amssymb}
\usepackage[T1]{fontenc}
\usepackage{xcolor}
\usepackage{tikz}
\usepackage[breaklinks=true]{hyperref}
\usepackage[babel,german=quotes]{csquotes}
\usepackage[style=numeric, backend=biber]{biblatex}
\usepackage{listings}
\usepackage{bytefield}
\usepackage{longtable}
\usepackage{sidecap}
\usepackage{wrapfig}
\usepackage{subcaption}
%\usepackage{titlesec}

\graphicspath{ {../../images/} }

\KOMAoptions{parskip=full}

\pdfimageresolution=72

%\titlespacing{\section}{8pt}{12pt plus 4pt minus 2pt}{0pt plus 2pt minus 2pt}
%\titlespacing{\subsection}{4pt}{12pt plus 4pt minus 2pt}{0pt plus 2pt minus 2pt}
%\titlespacing{\subsubsection}{2pt}{12pt plus 4pt minus 2pt}{0pt plus 2pt minus 2pt}

\begin{document}

    \title{Platinencomputer - Langfassung}
    \author{Alexander Wersching und Simon Walter}
    \date{2022}
    \maketitle

    \tableofcontents

    \newpage
    \section{Idee}
    \vspace{-15pt}
    Vor ca. 2 Jahren hatte Alex die Idee: Er wolle einen 8-Bit-Computer bauen.
    Die vor 2 Jahren beim Regionalwettbewerb München-West eingereichte Version eines anderen Teilnehmers hat dann auch mein (Simons) Interesse geweckt.
    \newline
    \vspace{-15pt}
        \begin{wrapfigure}{r}{0.5\textwidth}
        \vspace{-25pt}
        \begin{center}
            
        \end{center}
        \vspace{-20pt}
        \end{wrapfigure}
    Ein paar Monate später haben wir uns dann dazu entschieden, tatsächlich einen eigenen 8-Bit-Computer zu bauen und haben auch bald angefangen, erste Versuche auf dem Breadboard zu entwickeln.
    Es gab noch weder eine Möglichkeit diese erste Version automatisch zu betreiben, noch Daten zu schreiben/speichern, oder irgendwie mit der Umgebung zu interagieren, nur 3 Register, 2 Operationen und viele Knöpfe zum Bedienen.

    \section{Nutzen von Platinen}
    \vspace{-15pt}
    \subsection{Warum Platinen?}
    \vspace{-15pt}

        \begin{wrapfigure}{r}{0.4\textwidth}
        \vspace{-40pt}
        \begin{center}
        
        
        \end{center}
        \vspace{-30pt}
        \end{wrapfigure}

    Bald war aber klar, dass ein einfaches Verwenden von flachen Kabeln als Verbindung zwischen den Breadboards, das Kabelgewirr, das wir bei dem Projekt von vor 2 Jahren gesehen haben
    und nach Möglichkeit vermeiden wollten, um ein übersichtlicheres Design zu erreichen, nicht lösen kann.

    Als Alternative für Breadboards haben wir uns für Platinen (PCBs) entschieden.
    Aber weil unser Computer ja nicht mehr wirklich selbst gemacht wäre, wenn wir diese nur professionell ätzen lassen würden,
    wollten wir versuchen - zumindest einen Teil - selbst zu ätzen, auch wenn wir dadurch natürlich auf viele neue Probleme gestoßen sind...

    \newpage

    \subsection{Erste Versuche der Umsetzung}
    \vspace{-15pt}

        \begin{wrapfigure}{l}{0.4\textwidth}
        \vspace{-25pt}
        \begin{center}
         %hier binn ich noch nicht ganz glücklich mit dem Bild
        \end{center}
        \vspace{-20pt}
        \end{wrapfigure}

    Was zu Beginn das Projekt vorangetrieben hat, hat ab diesem Punkt aber natürlich ein Problem dargestellt:
    Das Homeschooling, währenddessen wir natürlich nicht Ätzen können.
    Wir hätten es natürlich zu Hause versuchen können, hatten da aber keine adäquate Ausrüstung v.a. bzgl. Sicherheit.
    Bis wir dann so weit waren, erste Versuche zu machen, war es dann schon Ende 2020.

    Der Herstellungsprozess funktioniert dabei wie folgt:
    \vspace{-10pt}
    \begin{enumerate}
        \item Wir Belichten die Photosensitive Platine mit UV Licht, auf der wir eine mit den Leiterbahnen bedruckte Overheadfolie legen;
        \vspace{-12pt}
        \item Wir legen die Platine - jetzt ohne Folie - in NaOH um die Schutzschicht der Platine an den Belichteten punkten zu lösen;
        \vspace{-12pt}
        \item Als letzten Entwicklungsschritt lösen wir mit FeCl$_3$ das Kupfer ab
        \vspace{-12pt}
        \item Nun werden noch die Entsprechenden Löcher für die THT (Through-hole-technology) Komponenten gebohrt und diese eingelötet
    \end{enumerate}

    \subsection{Design}
    \vspace{-15pt}

        \begin{wrapfigure}{r}{0.65\textwidth}
        \vspace{-40pt}
        \begin{center}
        
        \end{center}
        \caption{Offensichtlich ist das mit unseren aktuell geplanten Modulen: am Boden sitzt eine große Bus-Platine, auf der wir alle Module senkrecht aufstecken.\label{img:design}}
        \vspace{-160pt}
        \end{wrapfigure}

    Nachdem es auch auf geätzten Platinen noch nicht automatisch ordentlich ist und eine derart große Platine für uns nicht machbar gewesen wäre, haben wir uns dann noch ein 3-dimensionales, modulares Design ausgedacht. Dieses ist in \autoref{img:design}

        %\newline
        %\newline
        %\newline

    \newpage
    \section{Anforderungen}
    \vspace{-15pt}
    Im nächsten Lockdown hatten wir dann wieder viel Zeit zu planen, und der geplante Computer wurde immer komplexer.

    \subsection{Daten- und Adresslänge}
    \vspace{-15pt}

    Aus den ursprünglich geplanten 8-Bit wurden 16-Bit-Daten- und Adresslänge:

        \vspace{-5pt}
        \fbox{%
        \parbox{1\textwidth}{

        Die Daten- und Adresslänge besagt, wie viele binäre Ziffern (Bits) für eine Adresse und Daten verwendet werden.\\
        Je mehr Ziffern man verwendet desto größere Zahlen können in einer Operation verarbeitet werden.
            Dabei ist die maximal repräsentierbare Zahl $2^n - 1$ ist, wenn $n$ die Anzahl der Binären Ziffern (= Bits) ist.\\
        Ein $n$ teilbar durch $8$ zu machen, ist dabei relativ angenehm, weil $8$ Bit = $1$ Byte\\
        und Bytes sind nun mal die Grundlage für das meiste in der Informatik,\\
        zudem kommen einige elementare ICs (Integrated Circuits), z.B. Buffer oder Register, immer mit 8 Bits.\\
        \\
        Jedoch gilt, je mehr Bits man verwendet, desto mehr Schaltungen werden benötigt und desto größer der Stromverbrauch, wodurch es für uns relativ schnell unrealistisch aufwendig wird.\\
        \\
        Wir haben uns daher für $16$ Bit entschieden, womit wir
            Zahlen bis zwischen $0$ und $65535$ darstellen können.\\
        Diese Menge ist gerade groß genug, um Zahlen abzubilden, damit die meisten Programme funktionieren können, aber trotzdem noch auf Platinen handhabbar ist.\\

        }%
        }
        \vspace{0pt}

    \newpage
    \subsection{Memory}
    \vspace{-15pt}
    Für Daten und Programme verwenden wir in unserem Computer ein Modul: Memory-Modul

        \begin{wrapfigure}{r}{0.37\textwidth}
        \vspace{-140pt}
        \begin{center}
        
            \label{img:mem_map}
            \caption{Speicher Aufteilung: Von niederigen zu hohen Addressen in Hexdezimal schreibweiße}
        \end{center}
        \vspace{-20pt}
        \end{wrapfigure}

        \vspace{-5pt}
        \fbox{%
        \parbox{0.6\textwidth}{
        Unser Memory-Modul ist in 65536 einzelne und unabhängige Speicherzellen (jede 16 Bit groß) aufgeteilt. (weil wir genau so viele Adressen in unseren 16 Bit speichen können)\\
        Der Computer kann damit auf $65536 \text{ Words}$ oder $131072 \text{ Bytes}$ ($= 128 \text{ kib}$) direkt zugreifen.\\
        Die Größe messen wir in Words (w) oder in Kilowords (kiw), wobei $1 \text{ Word} = 2 \text{ Bytes} = 16 \text{ Bit}$ sind.\\
        \\
        Memory wird dabei über LD- und STR-Instruktionen gesteuert.\\
        Die LD-Instruktion kopiert einen Wert aus Memory und schreibt ihn in das Ziel-Register, während STR an der angegebenen Adresse den Wert mit dem Wert des Quellen-Register überschreibt.\\

        }
        }
        \vspace{0pt}

    Um aber noch mehr Speicher zu nutzen und das später erwähnte Berechtigungssystem möglichst leicht umsetzen zu können, haben wir noch Banken hinzugefügt:

        \vspace{-5pt}
        \fbox{%
        \parbox{1\textwidth}{
        Banken sind externe Memory Module, die eingesteckt werden können.
        Alle Banken sind gleich groß ($16\text{ kiw} = 32\text{ kib}$) und der Computer unterstützt maximal $65536$ unterschiedliche Banken.
        Jede Bank hat dabei eine ID (BID), die von $0$ bis $65535$ reicht.

        Der Computer hat zwei Bank-Slots (Slot 1 \texttt{0x8000 - 0xbfff} und Slot 2 \texttt{0xc000 - 0xffff}), auf den jeweils eine der Banken gelegt werden kann.
        \newline
        \newline
        Bank-Slot $1$ ist dafür gedacht, dass jeder Prozess dort in seiner eigenen Bank lebt, sodass in dem Prozess absolute Memory Adressen verwendet werden können, weil das Programm immer an der gleichen Stelle liegt.
        Außerdem wird in der Bank auch der Stack des jeweiligen Prozesses gespeichert, sodass dieser von anderen Prozessen nicht überschrieben werden kann.

        Bank-Slot $2$ dient als potentieller zusätzliche Speicher des Prozesses, oder als allgemeiner Speicherort, um zwischen den Prozessen Daten zu übermitteln.

        }%
        }

    \subsection{ROM}
    Um den Computer komplett unabhängig funktionsfähig machen zu können, haben wir uns dann überlegt einen Teil des RAMs (\texttt{0x0000} - \texttt{0xffff}) durch ROM zu ersetzen, um automatisch Programme von einem externen Speichermedium laden zu können. Zusehen in \autoref{img:mem_map}

    \subsection{Instruktionen}
    \vspace{-15pt}
    Um die neuen Möglichkeiten durch 16-Bit auch sinnvoll nutzen zu können, haben wir dann noch viele Logikoperationen und komplexere konditionale Jumps hinzu gefügt:
    Der Computer soll die Grundoperationen: Addition (ADD), Subtraktion (SUB), Multiplikation (MUL), Division (DIV),
    so wie die bitweisen Operationen: Exklusives Oder (XOR), Und (AND), Nicht (NOT) und Oder (OR) beherrschen.

    Der Computer besitzt zudem folgende Instruktion um mit Memory zu interagieren: Laden (LD), Speicher (STR), Bank 1 und
    Bank 2 wechseln (BNK1 und BNK2) und folgende Instruktion um mit dem Hardware Stack zu interagieren: push (PUSH), pop
    (POP), Funktionsaufruf (CALL) und Funktionsrückgabe (RET).

    Zudem die folgenden IO-Instruktionen: Instruktion Send (IOUT), Daten Senden (DOUT), Daten lesen (DIN), IO-Gerät Aktivieren (AIO) und IO-Gerät Deaktivieren

    Aber auch noch folgende Instruktion um Interrupts zu verwalten: Software Interrupt auslösen (INT), Modus des Timers 1 und 2 setzten (TM1/TM2) und die Stop Werte des Timers 1 und 2 setzten (SSTL1/SSTL2/SSTH1/SSTH2)

    Insgesamt hat unser Computer damit folgende Instruktionen: \autoref{table:instructions}

    \vspace{-15pt}
    \begin{center}
        \begin{longtable}{l | l l l l | l}
            \kill
            \caption{\label{table:instructions}Instruktions-Satz}
            \endhead
            Ins-ID & Name & op1 & op2 & op3 & Beschreibung \\
            \hline
            \texttt{0x00} & NOP  &  &  &  & Kein Effekt  \\
            \hline
            \texttt{0x01} & MOV  & reg &  & reg/c & op1 $=$ op3\\
            \texttt{0x02} & ADD  & reg & reg & reg/c & op1 $=$ op2 $+$ op3 \\
            \texttt{0x03} & SUB  & reg & reg & reg/c & op1 $=$ op2 $-$ op3 \\
            \texttt{0x04} & MUL? & reg & reg & reg/c & op1 $=$ op2 $*$ op3 \\
            \texttt{0x05} & MULOF& reg & reg & reg/c & op1 $=$ Overflow op2 $*$ op3 \\
            \texttt{0x05} & DIV? & reg & reg & reg/c & op1 $=$ op2 $/$ op3 \\
            \texttt{0x06} & XOR  & reg & reg & reg/c & op1 $=$ op2 $\oplus$ op3 \\
            \texttt{0x07} & AND  & reg & reg & reg/c & op1 $=$ op2 $\land$ op3 \\
            \texttt{0x08} & OR   & reg & reg & reg/c & op1 $=$ op2 $\lor$ op3 \\
            \texttt{0x09} & NOT  & reg &  & reg/c & op1 $=$ $\lnot$op3 \\
            \hline
            \texttt{0x0a} & STR  &  & reg & reg/c & memory[op3] = op2 \\
            \texttt{0x0b} & LD   & reg & reg & reg/c & op1 = memory[op2 + op3] \\
            \texttt{0x0c} & BNK1 &  &  & reg/c & Setzt BID für Bank-Slot1 \\
            \texttt{0x0d} & BNK2 &  &  & reg/c & Setzt BID für Bank-Slot2 \\
            \hline
            \texttt{0x0e} & PUSH &  &  & reg/c & SP--; memory[SP] = op1 \\
            \texttt{0x0f} & POP  &  &  & reg & op3 = memory[SP]; SP++ \\
            \texttt{0x10} & CALL &  &  & reg/c & \vtop{
				\hbox{\strut memory[SP] = IP; SP++;}
				\hbox{\strut IP = op3}} \\
            \texttt{0x11} & RET  &  &  &  & IP = memory[SP]; SP++ \\
            \hline
            \texttt{0x12} & TEST & reg &  & reg/c & Vergleicht op1 und op3 \\
            \texttt{0x13} & ME   & reg &  & reg/c & op1 = op3 if E \\
            \texttt{0x14} & MG   & reg &  & reg/c & op1 = op3 if G \\
            \texttt{0x15} & ML   & reg &  & reg/c & op1 = op3 if L \\
            \texttt{0x18} & MOFadd  & reg &  & reg/c & op1 = op3 if O \\
            \texttt{0x19} & MOFsub  & reg &  & reg/c & op1 = op3 if O \\
            \hline
            \texttt{0x1a} & IOUT & reg &  & reg/c & IIO[op1] = op3/c \\
            \texttt{0x1b} & DOUT & reg &  & reg/c & DIO[op1] = op3/c \\
            \texttt{0x1c} & DIN  & reg &  & reg & op3 = DIO[op1] \\
            \texttt{0x1d} & AIO  & reg &  &  & Aktiviert IO[op1] \\
            \texttt{0x1e} & DIO  & reg &  &  & Deaktivieren IO[op1] \\
            \hline
            \texttt{0x1f} & INT  & & & & Löst einen Interrupt aus \\
            \texttt{0x20} & TM1  & & & reg/c & Modi Timer1 = op3 \\
            \texttt{0x21} & TM2  & & & reg/c & Modi Timer2 = op3 \\
            \texttt{0x22} & SSTL1 & & & reg/c & erster Stop Timer1 = op3 \\
            \texttt{0x23} & SSTL2 & & & reg/c & zweiter Stop Timer2 = op3 \\
            \texttt{0x24} & SSTH1 & & & reg/c & erster Stop Timer1 = op3 \\
            \texttt{0x25} & SSTH2 & & & reg/c & zweiter Stop Timer2 = op3 \\
            \texttt{0x26} & CFL  & reg & & & op1 = erster Clock Freq \\
            \texttt{0x27} & CFH  & reg & & & op1 = zweiter Clock Freq
        \end{longtable}
    \end{center}

    \subsection{IO-Ports}
    \vspace{-15pt}
    Dazu hat sich die Idee von komplexer IO-Interaktion mit dem Computer ergeben:
    universelle Ports zum Anschließen von Festplatten, Sensoren, einfachen Tastaturen, LCD-Displays oder einer Grafikkarte.

        \vspace{-5pt}
        \fbox{%
        \parbox{1\textwidth}{
        Die theoretisch 65536 Anschlüsse, wobei jedem eine Anschluss-ID zugewiesen ist, kommunizieren mit IO-Geräten über 4 Kommandos,
            die als 4 separate Pins zwischen dem Controller und dem Gerät umgesetzt sind:

        1. Einen Befehl an das IO-Gerät schicken (auf Programm-Ebene);

        2. Daten zu einem vorherigen Befehl an das Gerät schreiben;

        3. Die Anfrage des IO-Gerätes, Daten an den Computer zurück zu schreiben, was bei diesem normalerweise einen Interrupt auslöst;

        4. Bestätigen des Computers, das das Externe Gerät schreiben darf;

        }%
        }

    \subsection{Supervisor-/Usermode}
    \vspace{-15pt}

        Er kann dabei in zwei Modi operieren: dem Supervisormode und Usermode.
        Im Supervisormode kann der Computer alle Funktion ohne Einschränkungen nutzen.
        Im Usermode hingegen ist der Computer in einigen Funktion eingeschränkt.
        Folgendes kann der Computer im Usermode \emph{nicht} machen:

        \begin{itemize}
            \item Setzen der SUP Flagge
            \item Änderung der OINT Flagge
            \item Lesen und/oder schreiben im Bereich von \texttt{0x0000} - \texttt{0x7fff}
            \item Änderung der Banken
            \item Die Modifikation der IO-Berechtigungsliste
            \item Zugriff auf IO-Geräte, welche nicht in der Berechtigungsliste gespeichert sind (siehe \autoref{section:persmissionIO})
        \end{itemize}

    Wir haben uns entschieden eine Art Berechtigungssystem in der Computer einzubauen.
    Eine Rechner der nur einfache Programm ausführt um zu Beispiel eine LED oder ein LCD-Display zu steueren, wie es z.B. ein ESP32 oder ein ATMega328p macht, ist so ein System nicht nötig.
    Wir hatten jedoch vor mit unserem Computer die Möglichkeit zu schaffen ein Betriebssystem ähnliches Programm (Supervisor) laufen zulassen.

    Hierfür hat man ein mal den Supervisor, der bei Start des Computer anfängt zulaufen und Programme, welche im Usermode ausgeführt werden, sogenannte Prozesse, lädt.
    Dabei sieht ein typischer Programmablauf ist dabei in gezeigt.

    Wichtig ist, das sobald ein Prozess beendet wurde, der Supervisor an dieser Stelle wieder anfängt und den nächsten Prozess startet.

    Ein Prozess kann auch Funktionen des Supervisor nutzten über Software Interrupts, da bei einem Interrupt, der Computer in den Supervisormode wechselt.
    So kann der Prozess, bevor er den Interrupt auslegt, ein oder mehrere Register nutzten um Werte an den Supervisor zu übergeben.
    z.B. kann er eine Register nutzten um dem Supervisor zu sagen was er tun soll, z.B. dem Prozess zugang zu einem IO-Gerät zugeben oder etwas in eine Datei zuschreiben.
    Diese Art von Kommunikation werden auch System-Calls genannt und sind die Basis für jedes moderne Betriebssystems.

    Ein solcher Supervisor kann sehr mächtig sein:

    \begin{enumerate}
        \item Abstraktion der Hardware: Oft ist die IO-Configuration von Setup zu Setup sehr verschieden. Ein Prozess welcher IO-Geräte nutzen möchte hat oft den Nachteil dass es für ein bestimmtes Hardware setup geschrieben wurde. So z.B. ein Prozess der Daten einer SD-Karte ausließt und diese anzeigt. Wenn man jedoch jetzt eine Floppy-Laufwerk anschließt, so kann man das Prozess zum Auslesen nicht verwenden, da es nur die Kommuntiation mit einer SD-Karte kennt. Der Supervisor könnte an dieser Stelle ein Interface über System-Calls bieten welches unabhänige von dem Gerät ist. So im diesem Beispiel ein Dateisystem, auf welches Prozesse zugreifen können. Somit übernimmt der Supervisor die Kommuntiation mit der Hardware.

        \item Teilung der Rechenzeit: Der Computer so viele Features er doch hat, ist stark limitiert vor allem was Rechengeschwindigkeit betrifft. Wenn man nun mehrer Programm hat, welche ausgeführt werden sollen, so wäre es natürlich sehr einfach sie der Reihe nach auszuführen. Jedoch gibt es bessere Wege, so z.B. das der Computer jedem Prozess nur eine bestimmte Rechenzeit gibt und dann den nächsten Prozess ausführt. Das kann erreicht werden durch folgenden Ablauf: Der Supervisor stellt vor dem ausführen des Prozesse eine Timed-Interrupt. Dann übergibt der Supervisor den Computer dem Prozess, welcher dann seine Programm ausführt. Dies machter bis der Timed-Interrupt ausgelöst wird und der Computer wieder in den Supervisormode wechselt. Dieser speichert nun alle Register und Banken Configuration des Prozesse und übergibt einem anderen Prozesse den Computer. Wenn nun ein schon angefanger Prozess wieder gestarted werden soll läd der Supervisor wieder die Register und Banken des Prozesses und übergibt die Außführung wieder an den Prozess. Somit kann der Computer zwischen Prozessen hin und herschallten, was die Illusion gibt, das der Computer diese gleichzeitig ausführt.

        \item Isolation von Prozessen: Programme sind meist nicht perfekt. Vor allem sowas wie Bufferoverflows und andere Fehler dieser Art treten in Low-Level Systeme gerne auf. Aus diesem Grund ist es wichtig Prozesse von einander zu isolieren. Nehmen wir an Prozess A hat ein Fehler welcher dafür sorgt das er den gesammten RAM anfängt voll zuschreiben. Um jetzt Prozess A daran zuhinern Prozess B zu überschreiben, ist es dem Prozess A nicht gestattet auf den Arbeitsspeicher von Prozess B zuzugreifen. Nur der Supervisor kann zwischen den Prozessen wechseln
    \end{enumerate}

    Wenn man so etwas will kann dass auch auf einem ATMega328p gemacht werden, jedoch nicht ohne massive Leistungsverluste.
    Wenn so ein Berechtigungssystem jedoch direkt in die Hardware des Computers einfließt sorgt das für eine viel effektiveren Computer.

    Wenn man tatsächliche nur Programme schreiben will welche ''nur'' ein LED oder LCD-Display steuern soll, kann man das mit unserem Computer auch machen, indem man einfach dieses Programm im Supervisor laufen lässt.

    \section{Tests}
    \subsection{Breadboard-Test}
        %\begin{wrapfigure}{r}{0.65\textwidth}
        %\vspace{-40pt}
        %\begin{center}
        %\includegraphics[width=0.55\textwidth]{Perspektive_P}
        %\end{center}
        %\vspace{-50pt}
        %\end{wrapfigure}
    Zwischendurch haben wir dann für die Einladung zu der lokalen Veranstaltung
    $"$Perspektive P$"$ am 15.07.2021 wieder einen unvollständigen Prototyp auf dem Breadboard gebaut.

    \subsection{Geschwindigkeit}
    \vspace{-15pt}
        \begin{wrapfigure}{r}{0.4\textwidth}
        \vspace{-20pt}
        \begin{center}
        
        \caption{Messaufbau\label{img:PD_Messurement}}
        \end{center}
        \vspace{-20pt}
        \end{wrapfigure}

    Um zu errechnen, wie schnell wir den Computer maximal laufen lassen können, ohne fehlerhafte Ergebnisse zu erhalten, haben wir den ''Propagation-Delay'' gemessen.
    Der ''Propergation-Delay'' ist die Zeit, bis der Chip den Output liefert, den der laut der Eingabe haben müsste. Wir haben diese Messungen bei einigen unserer wichtigsten Komponent durch geführt.
    Die meisten Chips, die wir jetzt vorhaben zu verwenden, haben eine Properagtion-Delay von zwischen $10$ und $20$ ns wie z.B. bei NAND, AND oder OR-Gatteren.
    Allerdings haben wir bei den einigen Versionen, die wir getestet haben, teilweise weitaus höhere Werte bis zu $150$ ns gemessen.
    Dies ist an sich noch nicht so schlecht, aber wenn wir damit rechnen, dass wir Reihen von bis zu $40$ Chips verwenden, limitiert das die Geschwindigkeit schon sehr. Der Messaufbau den wir verwendet haben ist dabei in \autoref{img:PD_Messurement} zusehen. Die Ergebnisse einer solchen Messung können in \autoref{img:res_PD} eingesehen werden.

    \begin{figure}
        
        \caption{Messergebnisse der Propergation-Delay Messung von drei Quod-NAND-Gattern in Verschieden Ausführungen (CD4096BE, SN74HC00, SN74HCT00)\label{img:res_PD}}
    \end{figure}

    \newpage
    \subsection{Funktionsweise der Chips}
    \vspace{-15pt}
    Wir wollen als Basis für unseren Computer ja Chips kaufen, aber wie funktionieren die eigentlich?
    Wir haben also versucht den Aufbau herauszufinden, indem wir einfach einen geöffnet haben, wobei $"$einfach$"$ nicht so ganz stimmt, weil die Hülle aus Epoxidharz besteht, was sich fast nicht auflösen lässt.
    Also mussten wir mechanisch abtragen, also Schleifen.
    Leider haben wir es damit nie geschafft das gesamte Silizium/die Verbindungsbahnen frei zu legen, sodass wir keinen Schaltplan erstellen könnten,
    es gab uns aber trotzdem eine beeindruckende persönliche Einsicht:

        \begin{figure}[h]
        \begin{subfigure}[b]{0.3\textwidth}
            
            \end{subfigure}
        ~
        \begin{subfigure}[b]{0.3\textwidth}
            
            \end{subfigure}
        ~
        \begin{subfigure}[b]{0.3\textwidth}
            
            \end{subfigure}
        \end{figure}

    \newpage
    \section{Umsetzung}
    \vspace{-15pt}
    \subsection{Programmierung}
    \vspace{-15pt}

        \begin{wrapfigure}{r}{0.6\textwidth}
        \vspace{-30pt}
        \begin{center}
        
        \end{center}
        \vspace{-20pt}
        \end{wrapfigure}

    Um den ROM-Chip zu programmieren haben wir zwar mal kurz ein bisschen manuell über Schalter programmiert, aber nachdem das offensichtlich zu lange brauchen würde haben wir dann einen Arduino (um genau zu sein, einen ESP32) programmiert und an die pins des ROM-Chips angeschlossen.
    Der Arduino bekommt die zu schreibenden bits wiederum aus einem Python-Programm, das den Assembler in Maschinensprache (eine binary Datei) umwandelt.

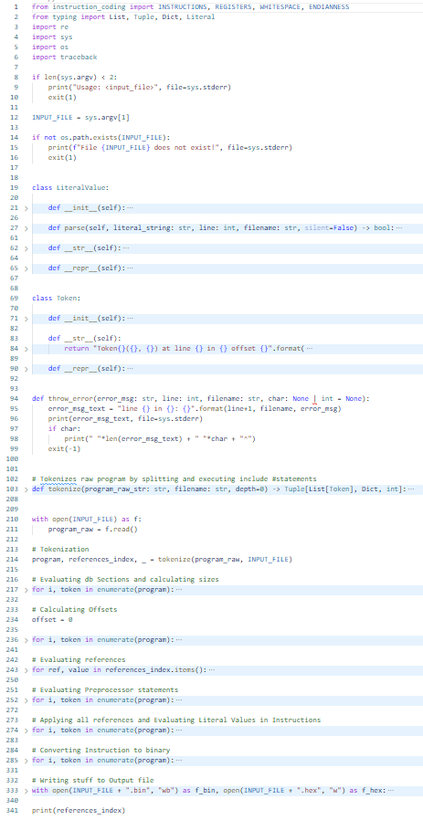
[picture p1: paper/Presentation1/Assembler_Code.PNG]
    

    \newpage
    \subsection{Weitere Tests zum Ätzen}
    \vspace{-15pt}
    Im Schuljahr 2021-2022 haben wir dann wieder weitere Tests zum Ätzen - diesmal sowohl erfolgreicher, als auch besser dokumentiert, um die optimalen Belichtungs- und Ätzzeiten zu finden.
    Diese sind in der nebenstehenden Tabelle aufgelistet.
    \newline
    \vspace{-5pt}
    

    Es hat sich folgender Ablauf funktioniert nach unseren Test am besten: Ein Belichtungszeit von $20$ bis $30$ min, mit den Konzentrationswerten von
    c(\ch{NaOH}) $= 0.015 \text{g/ml}$, c(\ch{FeCl3}) $= 0.8 \text{g/ml}$. Dabei ist zubachten, dass das Entwickeln und Ätzen unter Bewegung statfinden muss.

    \subsection{Spezifikation}
    \vspace{-15pt}
    Gleichzeitig haben wir auch angefangen unsere erste vollständige Version der Spezifikation zu schreiben siehe: \href{https://www.mediafire.com/file/9iz9wlpiuwhr1ln/HandBuch.pdf/file}{Handbuch.pdf}

    \newpage
    \subsection{Nutzung eines zwei Busses}
    \vspace{-15pt}
    Um Memory innerhalb eines Clock-Zyklus zu beschreiben, muss diesem sowohl eine 16-Bit-Adresse als auch den 16-Bit-Daten-Wert übermittelt werden.
    Damit diese beiden Daten parallel übermittelt werden können brauchen wir also 2*16 Bit.
    Wir hätten dafür natürlich auch irgendwelche Kabel verlegen können, aber wir wollen in unserem System die Daten immer auf dem Bus transportieren, damit diese auch von anderen Modulen gelesen werden könnten.
    Die Adresse muss im Anwendungsfall des Stacks vor Benutzung um eins erhöht oder verringert werden, was in unserem System durch die ALU erfolt, wobei diese ihre Daten nur auf den Bus auseben kann.
    Dabei hat sich ein Aufbau wie in \autoref{img:schematic_all} ergeben.

    \begin{figure}
        \vspace{-15pt}
    
        \caption{Schematischer Aufbau des Computers\label{img:schematic_all}}
        \vspace{-15pt}
    \end{figure}

    \newpage
    \subsection{Design der Schaltungen}
    \vspace{-15pt}

        \begin{wrapfigure}{r}{0.7\textwidth}
        \vspace{-20pt}
        \begin{center}
        
        
        \end{center}
        \vspace{-20pt}
        \end{wrapfigure}
    Zum Designen haben wir uns schlussendlich darauf festgelegt, dass wir die Schaltungen zuerst in dem Logiksimulationsprogramm Logisim erstellen,
    und danach den Plan noch einmal als ätzbaren Schaltplan erstellen, wobei wir hierfür kein wirklich zufriedenstellendes Produkt finden konnten.
    Schließlich haben wir uns vor allem wegen der Einfachheit es zu bekommen und Installieren für KiCad entschieden, was uns allerdings ziemlich viel Frust beschert hat.

\end{document}

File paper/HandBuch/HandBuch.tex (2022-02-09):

\documentclass{scrartcl}

\usepackage{graphicx}
\usepackage[siunitx, RPvoltages, european]{circuitikz}
\usepackage{tikz-timing}

\usepackage{ulem}
\usepackage[ngerman]{babel}
\usepackage[utf8]{inputenc}
\usepackage{amsmath}
\usepackage{amssymb}
\usepackage[T1]{fontenc}
\usepackage{xcolor}
\usepackage{tikz}
\usepackage[breaklinks=true]{hyperref}
\usepackage[utf8]{inputenc}
\usepackage[babel,german=quotes]{csquotes}
\usepackage[style=numeric, backend=biber]{biblatex}
\usepackage{listings}
\usepackage{bytefield}
\usepackage{longtable}

\newcolumntype{L}[1]{>{\raggedright\arraybackslash}p{#1}}

\lstdefinestyle{asm}{
}

\addbibresource{ref.bib}

\graphicspath{ {../images} }

\KOMAoptions{parskip=full}

\begin{document}

\title{Platinencomputer - Handbuch}
\author{Alexander Wersching und Simon Walter}
\date{2021}
\maketitle
\newpage

\tableofcontents
\newpage

\section{Einführung}
\subsection{Ziel diese Dokuments}
Dieses Dokument soll die Funktionsweise unseres Platinencomputers beschreiben.
Dabei soll nicht auf die tatsächliche auf Implementation wert gelegt werden, aber viel mehr auf die einzelnen Features und Funktionen.
Diese Spezifikation wurde vor dem Bau des Computers bzw. des Emulators geschrieben, um eine Grundlage für alle weiteren Konstruktionsschritte zu haben.

\subsection{Geschichte}
Dieses Dokument hat sehr viel Änderung durchleben müssen, diese können unter \url{https://github.com/jufo-ufo/Breadboard-Computer} eingesehen werden.
Zudem hatte diese Spezifikation zwei, wenn auch nicht vollständige, Vorgänger: \url{https://github.com/jufo-ufo/Breadboard-Computer/blob/master/specification_v0.1.txt} und \url{https://github.com/jufo-ufo/Breadboard-Computer/blob/master/specification_v0.2.txt}. Wobei die zweite Fassung als Basis dieses Dokuments diente.

\section{Spezifikation des Computers}
Ein Computer hat eine Reihe verschiedener ``high-level`` Aufgaben und Features, die es ihm erlauben, seiner Tätigkeiten nach zu gehen! 
Diese Features können wie folgt auf gegliedert werden: Register, Memory, Input/Output, Interrupts, Supervisor-/Usermode und der Instruktionssatz.

Aber um zuerst ein paar Standards festzulegen: Der Computer hat eine Daten-/Adressenlänge von 16 Bit, d.h. er kann maximal 16 Bit auf einmal operieren bzw. können maximal 16 Bit an Daten/Adressen im Computer auf einmal bewegt werden. Mehr dazu in \autoref{section:comment:datalength}

Unsere Computer ist eine von Neumann-Maschine, d.h. sowohl Daten als auch Programm während in einem Hauptspeicher (Memory) gespeichert

\subsection{\label{section:insSet}Instruktions-Satz}

Das Programm, welches den Computer vorschreibt, was er abzuarbeiten hat, besteht aus Instruktionen.
Jede Instruktion enthält die $6$ Bit langen Ins-ID, ein $16$ Bit Konstante und $3$ gewählte Register in Form einer $3$ Bit Register Nummer (RN).
Damit ergibt sich eine $32$ Bit, also $2$ words, lange Instruktion.
Die Codierung ist dabei in \autoref{fig:InsEncoding} festgehalten.

\begin{figure}[h]
	\label{fig:InsEncoding}
	\centering
	\begin{bytefield}{32}
		\bitheader{0,5,6,7,9,10,12,13,15,16,31}\\
		\bitbox[ltb]{6}[]{Ins-ID}
		\bitbox[ltb]{1}[]{E}
		\bitbox[ltb]{3}[]{op1}
		\bitbox[ltb]{3}[]{op2}
		\bitbox[ltb]{3}[]{op3}
		\bitbox[lrtb]{16}[]{Konstante}
	\end{bytefield}
\end{figure}

Jeder zur Verfügung stehenden Instruktion ist dabei exakt einer oben erwähnten Ins-ID zugeordnet. Alle Ins-ID und dazugehörige Instruktion ist in \autoref{table:instructions}

Jede Instruktion hat 3 Operatanten (op), welche Register sind.
Im Falle des dritten Operatanten kann auch eine Konstante verwendet werden.
Das E Bit gibt dabei an, welches von beiden genutzt werden soll.
Bei gesetztem E Bit wird die Konstante verwendet, bei nicht gesetztem E Bit das Register.

\begin{center}
	\begin{table*}
		\caption{\label{table:instructions}Instruktions-Satz}
		\begin{tabular}{l | l l l l | l}
			Ins-ID & Name & op1 & op2 & op3 & Beschreibung \\
			\hline
			\texttt{0x00} & NOP  &  &  &  & Kein Effekt  \\
			\hline
			\texttt{0x01} & MOV  & reg &  & reg/c & op1 $=$ op3\\
			\texttt{0x02} & ADD  & reg & reg & reg/c & op1 $=$ op2 $+$ op3 \\
			\texttt{0x03} & SUB  & reg & reg & reg/c & op1 $=$ op2 $-$ op3 \\
			\texttt{0x04} & MUL? & reg & reg & reg/c & op1 $=$ op2 $*$ op3 \\
			\texttt{0x05} & MULOF& reg & reg & reg/c & op1 $=$ Overflow op2 $*$ op3 \\ 
			\texttt{0x05} & DIV? & reg & reg & reg/c & op1 $=$ op2 $/$ op3 \\
			\texttt{0x06} & XOR  & reg & reg & reg/c & op1 $=$ op2 $\oplus$ op3 \\
			\texttt{0x07} & AND  & reg & reg & reg/c & op1 $=$ op2 $\land$ op3 \\
			\texttt{0x08} & OR   & reg & reg & reg/c & op1 $=$ op2 $\lor$ op3 \\
			\texttt{0x09} & NOT  & reg &  & reg/c & op1 $=$ $\lnot$op3 \\
			\hline 
			\texttt{0x0a} & STR  &     & reg & reg/c & memory[op3] = op2  \\
			\texttt{0x0b} & LD   & reg & reg & reg/c & op1 = memory[op2 + op3] \\
			\texttt{0x0c} & BNK1 &  &  & reg/c & Setzt BID für Bank-Slot1 \\
			\texttt{0x0d} & BNK2 &  &  & reg/c & Setzt BID für Bank-Slot2 \\
			\hline
			\texttt{0x0e} & PUSH &  &  & reg/c & SP--; memory[SP] = op3 \\
			\texttt{0x0f} & POP  & op1 &  & & op1 = memory[op]; SP++ \\
			\texttt{0x10} & CALL &  &  & reg/c & \vtop{
				\hbox{\strut memory[SP] = IP; SP++;}
				\hbox{\strut IP = op3}} \\
			\texttt{0x11} & RET  &  &  &  & IP = memory[SP]; SP++ \\
			\hline
			\texttt{0x12} & TEST   & reg & reg & reg/c & op1 = Vergleicht von op1 und op3 \\
			\texttt{0x13} & ME     & reg & reg & reg/c & op1 = op3 if E else op2 \\
			\texttt{0x14} & MG     & reg & reg & reg/c & op1 = op3 if G else op2 \\
			\texttt{0x15} & ML     & reg & reg & reg/c & op1 = op3 if L else op2 \\
			\texttt{0x16} & MS     & reg & reg & reg/c & op1 = op3 if SUP else op2 \\
			\texttt{0x17} & MI     & reg & reg & reg/c & op1 = op3 if OINT else op2 \\
			\texttt{0x18} & MOFadd & reg & reg & reg/c & op1 = op3 if O else op2 \\
			\hline
			\texttt{0x1a} & IOUT & reg &  & reg/c & IIO[op1] = op3/c \\
			\texttt{0x1b} & DOUT & reg &  & reg/c & DIO[op1] = op3/c \\
			\texttt{0x1c} & DIN  & reg &  & reg & op3 = DIO[op1] \\
			\texttt{0x1d} & AIO  & reg &  &  & Aktiviert IO[op1] \\
			\texttt{0x1e} & DIO  & reg &  &  & Deaktivieren IO[op1] \\
			\hline
			\texttt{0x1f} & INT  & & & & Löst einen Interrupt aus \\
			\texttt{0x20} & TM1  & & & reg/c & Modi Timer1 = op3 \\
			\texttt{0x21} & TM2  & & & reg/c & Modi Timer2 = op3 \\
			\texttt{0x22} & SSTL1 & & & reg/c & lower Stop Timer1 = op3 \\
			\texttt{0x23} & SSTL2 & & & reg/c & lower Stop Timer2 = op3 \\
			\texttt{0x24} & SSTH1 & & & reg/c & higher Stop Timer1 = op3 \\			
			\texttt{0x25} & SSTH2 & & & reg/c & higher Stop Timer2 = op3 \\
			\texttt{0x26} & CFL  & reg & & & op1 = lower Clock Freq \\
			\texttt{0x27} & CFH  & reg & & & op1 = higher Clock Freq \\
			
			\hline
		\end{tabular}
	\end{table*}
\end{center}

\subsection{\label{section:supervisor}Supervisor-/Usermode}

Der Computer hatte ein eingebautes Rechte-System.
Er kann dabei in zwei Modi operieren: dem Supervisormode und Usermode.
Im Supervisormode kann der Computer alle Funktion ohne Einschränkungen nutzen.
Im Usermode hingegen ist der Computer in einigen Funktion eingeschränkt.
Folgendes kann der Computer im Usermode \emph{nicht} machen:

\begin{itemize}
	\item Setzen der SUP Flagge
	\item Änderung der OINT Flagge
	\item Lesen und/oder schreiben im Bereich von \texttt{0x0000} - \texttt{0x7fff}
	\item Änderung der Banken
	\item Die Modifikation der IO-Berechtigungsliste
	\item Zugriff auf IO-Geräte, welche nicht in der Berechtigungsliste gespeichert sind (siehe \autoref{section:persmissionIO})
\end{itemize}

Der Modus des Computers (Supervisor or User) wird dabei in der SUP Flagge gespeichert.
Eine gesetzte SUP Flagge entspricht dem Supervisormode und eine nicht gesetzte SUP dem Usermode Der Computer started dabei mit gesetzter SUP Flagge.

Zudem ändert sich je nach Modus des Computer die Start position des Stacks wie in \autoref{section:stack} erläutert.

Mehr zu der Motivation hinter diesem System in \autoref{com:sup}

\subsection{Registers}
Register sind kleine, sehr schnelle Speichereinheiten, die genutzt werden können, um Zwischenergebnisse, lokal Variablen, Argumenten für Funktionen zu speichern oder um Daten im Computer zwischen den einzelnen Komponenten zu verschieben.
Aus jedem Register kann \emph{gelesen} (\emph{Kopierten} des alten Wertes an einen anderen Ort) oder \emph{geschrieben} werden (den alten Wert mit einem neuen Wert \emph{überschreiben})

Der Computer besitzt $8$ verschiedene, jeweils $16$ Bit lange Register.
Jedes Register hat dabei eine eigene Registernummer (RN).
Machen Register erfüllen zudem noch spezielle Aufgaben und sollten auch nur so verwendet werden.
Diese Funktionen sind in \autoref{table:register} zu sehen.

Mehr zur Registeranzahl in \autoref{section:comment:register_number}

\begin{center}
	\begin{table}[h]
		\caption{\label{table:register} Registeraufteilung}
		\begin{tabular}{l | l | l}
			RN & Name & Funktion\\
			\hline
			$0$ & ZERO & Konstante $0\text{x}0000$; Schreiben hat keinen Effekt\\
			$1$ & IP & Instruction Pointer, zeigt auf aktuell auszuführende Instruktion\\
			$2$ & SP & Stack Pointer, zeigt auf obersten Wert des Stacks, siehe \ref{section:stack} \\
			$3$ & A & Allzweck Register ohne besonderen Aufgaben \\
			$4$ & B & Allzweck " \\
			$5$ & C & Allzweck " \\
			$6$ & D & Allzweck " \\
			$7$ & FLAG & Enthält alle wichtigen Flaggen, siehe \autoref{section:flags} \\
		\end{tabular}
	\end{table}
\end{center}

Die Register A-D sind dabei Register, welche frei für jede Nutzung zur Verfügung stehen.
Es ist \emph{stark zu empfehlen}, die Spezialregister (ZERO, IP, SP und FLAG) \emph{nicht} für die Speicherung von Daten zu verwenden, da dies evtl. Programmabläufe stark stören könnte oder im Falle von ZERO oder den letzten 8 bit des Flaggen Registers im Usermode nicht möglich ist.
Sie sind ausdrücklich nur für ihre zugewiesenen Aufgaben da.

\subsubsection{\label{section:DataMov} Kopieren und Bewegen von Daten}

Das Kopierten eines Wertes in ein Register ist mit der MOV-Instruktion möglich.
Die MOV-Instruktion nimmt dabei als ersten Operanden das Ziel Register und als zweiten Operanden das Quellenregister oder eine Konstante an.
MOV kopiert nun den Wert des zweiten Operanden in den des Ersten.
Die Notation ist dabei wie folgt:

\text{MOV <Ziel-Register> <Quellen-Register/Konstante>}

\subsubsection{\label{section:flags}Flaggen}

Das Register FLAG enthält alle Statusflaggen.
Eine Flagge kann entweder gesetzt oder nicht gesetzt sein, daher kann jede Flagge als ein Bit repräsentiert werden.
Jedes Bit in FLAG stellt daher eine Flagge da. Flaggen werden bei unterschiedlichen Ereignissen geschaltet.
Dies und welche Flaggen es gibt, ist in \autoref{table:flag} zusehen.

\begin{center}
	\begin{table}[h]
		\caption{\label{table:flag}Flaggenaufteilung in FLAG}
		\begin{tabular}{l | l | l | l}
			Bit & Name & Funktion & Schaltung \\
			\hline
			 0 & NE    & Ungleichheit zweier Werte					& TEST op1 $\neq$ op2\\
			 1 & E     & Gleichheit zweier Werte 					& TEST op1 = op2\\
			 2 & G     & Ungleichheit ($>$) zweier Werte 			& TEST op1 > op2\\
			 3 & L     & Ungleichheit ($<$) zweier Werte 			& TEST op1 < op2\\
			 4 & OFadd & Integer Overflow bei einer Addition 		& TEST op1 + op2 > $65535$ \\
			 5 & \sout{OFsub} & \sout{Integer Overflow bei einer Subtraktion} 	& \sout{TEST op1 - op2 < $0$} \\
			 6 &  &  & \\
			 7 &  &  & \\
			 8 & OVTI1 & Overwrite Timed-Interrupt1, siehe \autoref{section:interrupts} &  \\
			 9 & OVTI2 & Overwrite Timed-Interrupt2, siehe \autoref{section:interrupts} &  \\
			10 & OVIOI & Overwrite IO-Interrupt, siehe \autoref{section:interrupts} &  \\
			11 &  &  &  \\
			12 &  &  &  \\
			13 &  &  &  \\
			14 &  &  &  \\
			15 & OINT & Overwrite Interruption &  \\
			15 & SUP & Supervisor-/Usermode, siehe \autoref{section:supervisor} & 
		\end{tabular}
	\end{table}
\end{center}

Das FLAG Register verhält sich ebenfalls wie ein Register, daher können Flagge auch per Hand gesetzt oder nicht gesetzt werden.
Eine Ausnahme machen die letzten 8 Flaggen darunter SUP und OINT die nur geschaltet werden können, wenn der Computer sich im Supervisormode befindet, siehe \autoref{section:supervisor}.
Ein Schalten im Usermode hat keinen Effekt.

Flaggen $0$-$7$ werden bei dem Ausführen der TEST-instruktion gesetzt, die restlichen nur manuel.

Neben der MOV-Instruktion gibt es auch die sogenannten konditionalen MOV-Instruktionen.
Diese funktionieren genauso wie die MOV-Instruktion, indem sie das Quellen-Register/Konstante in das Ziel-Register kopiert, aber dies jedoch nur tun, wenn die entsprechende Flagge gesetzt ist.
Die Notation dafür ist wie folgt:

\text{M<Flagge> <Ziel-Register> <Quellen-Register/Konstante>}

Daher ergeben sich folgende konditionalen MOV-Instruktionen: ME (E Flagge), MG (G Flagge), ML (L Flagge), MI (ONIT Flagge), MS (SUP Flagge), MOFadd (OFadd Flagge), MOFsub (OFsub Flagge).

\subsubsection{\label{section:arthimatik}Arithmetische und Logische Operationen}

Der Computer hat zudem die Fähigkeit, arithmetische und logische Operation durchzuführen.
Alle Operationen sind dabei binär daher Kombinieren zwei Eingangswerte oder Operanden zu einem Ausgangswert.
Die Ausnahme macht dabei die NOT-Instruktion, die nur einen Eingangswert annimmt und auf diesen ein Bitweises Nicht durchführt.

Alle arithmetischen und logische Operationen funktionieren dabei immer gleich:
Sie kombinieren das erste Quelle-Register mit dem zweiten Quellen-Register und schreiben das Ergebnis in das Ziel-Register.
Dabei ist zu beachten, dass das zweite Quellen-Register durch einen konstanten Wert ersetzt werden kann.
Die Notation dafür sie wie folgt aus:

\text{<Operation> <Ziel-Register> <Quellen-Register 1> <Quellen-Register 2/Konstante>}

Der Computer unterstützt dabei folgende Operationen:
Addition (ADD), Subtraktion (SUB), Multiplikation (MUL), Division (DIV), Bitweises exklusives Oder (XOR), Bitweise Und (AND), Bitweises Oder (OR), Bitweises Nicht (NOT).

Wichtig zu sagen ist, dass bei alle Operationen ($f(x_1, x_2) \equiv y \mod 65536$) gilt $65535 \ge y \ge 0$ ist wo bei gilt $y \in \mathbb{N}$.
Der springende Punk ist, dass bei einer Rechnung wie $65535 + 1$ das Ergebnis nicht $65536$ ist, sondern $0$.
So ein “Overflow“ kann erkannt werden durch die Ausführung der TEST-Instruktion für Addition und Subtraktion. Diese Setzt bzw löscht bei Subtraktion und Addition, die entsprechenden Flaggen OFadd und OFsub. 

Bei Addition ist das schlimmste was passieren kann ein Overflow von $1$ ($65535 + 65535 = 131070 \equiv 65534 \mod 65536$). Bei Subtraktion werden negative Zahl im Zweierkomplement System dargestellt. Das Schlimmst was passieren kann ist daher ein Overflow, oder vielmehr Underflow von $1$ ($0 - 65535 = -65535 \equiv 1 \mod 65536$)

Bei der Multiplikation von zwei Zahlen ist dies jedoch komplexer, da in diesem Fall ein Overflow zwischen $0$ und $65534$ haben kann ($65535 * 65535 = 4294836225 \equiv 1 \mod 65536$). Daher gibt es eine MULOF um den bei der Multiplikation entstanden Overflow aufzufangen. Die Notation ist dabei wie folgt:

\text{MULOF <Ziel-Register> <Quellen-Register 1> <Quellen-Register 2/Konstante>}

\subsection{\label{section:memory}Memory}

Während die Register für lokale Variablen und Zwischenergebnisse gedacht sind, ist Memory (Arbeitsspeicher) für die Speicherung von größeren Datenmengen gedacht.

Es ist in 65536 einzelne und unabhängige Speicherzellen (Jede 16 Bit große) aufgeteilt.
Jeder Zelle ist einer Adresse, welche von 0 bis 65535 reicht, zugeordnet.
Der Computer kann damit auf $65536 \text{ words}$ oder $131072 \text{ bytes}$ ($\approx 128 \text{ kib}$) zugreifen
\footnote{Die Größe messen wir in words (w) oder in kilowords (kiw), wobei $1 \text{ word} = 2 \text{ bytes} = 16 \text{ Bit}$.}.
Wichtig ist, dass die gesamt Größe, dank Banking siehe \autoref{section:banking} theoretisch weitaus größer sein kann.

Memory wird dabei über LD- und STR-Instruktionen gesteuert.
Die LD-Instruktion kopiert einen Wert aus Memory und schreibt ihn in ein Ziel-Register, während STR an der angegebenen Adresse den Wert mit dem Wert des Quellen-Register überschreibt.
Die Adresse wird zusammen gesetzt durch die Addition des Address-Register1 und entweder in dem Address-Register2 oder einer Konstante.
Die Notation sieht dabei wie folgt aus:

\text{LD <Ziel-Register> <Address-Register1> <Address-Register2/Konstante>}

\text{STR <Quellen-Register> <Address-Register1> <Address-Register2/Konstante>}

Zudem wurden bestimmte Bereichen bestimmte Aufgaben bzw. Funktionen zugewiesen, wie in \autoref{fig:memoryMap} zu sehen.
Die zwei Hardware Stacks sind dort gekennzeichnet mit $\uparrow$, mehr dazu Stacks in \autoref{section:stack}

Die mit Supervisor gekennzeichneten Bereich können nur dann gelesen oder geschrieben werden, wenn sich der Computer im Supervisormode befindet.
Mehr zu Supervisormode in \autoref{section:supervisor}.
Der Bereich, der mit ROM versehen wurde, ist dabei nicht beschreibbar, sondern kann nur gelesen werden.
Eine STR-Instruktion hat keine Wirkung.
Eine Änderung des Inhalts der ROM Bereiche ist nur durch den Austausch/Externes Programmieren des darunterliegen physikalischen ROM-Chips möglich.

\begin{figure}[h]
	\centering
	\caption{Memory Karte}
	\label{fig:memoryMap}
	\begin{bytefield}[leftcurly=., rightcurly=., leftcurlyspace=0pt, rightcurlyspace=0pt]{16}
		
		\begin{leftwordgroup}{\small \texttt{0x0000}}
			\bitbox[lrt]{16}{}
		\end{leftwordgroup}\\
		\wordbox[lr]{2}{ROM Supervisor\\$16384 \text{w} \approx 16 \text{kiw}$} \\
		\begin{leftwordgroup}{\small \texttt{0x3fff}}
			\bitbox[lr]{16}{}
		\end{leftwordgroup}\\

		\begin{leftwordgroup}{\small \texttt{0x4000}}
			\bitbox[lrt]{16}{}
		\end{leftwordgroup}\\
		\begin{rightwordgroup}{\large $\uparrow$ Sup. Stack}
			\wordbox[lr]{2}{RAM Supervisor\\$16384 \text{w} \approx 16 \text{kiw}$} \\
		\end{rightwordgroup}
		\begin{leftwordgroup}{\small \texttt{0x7fff}}
			\bitbox[lr]{16}{}
		\end{leftwordgroup}\\

		\begin{leftwordgroup}{\small \texttt{0x8000}}
			\bitbox[lrt]{16}{}
		\end{leftwordgroup}\\
			\wordbox[lr]{2}{Bank 1 (User Programm)\\$16384 \text{w} \approx 16 \text{kiw}$} \\
		\begin{leftwordgroup}{\small \texttt{0xbfff}}
			\bitbox[lr]{16}{}
		\end{leftwordgroup}\\

		\begin{leftwordgroup}{\small \texttt{0xc000}}
			\bitbox[lrt]{16}{}
		\end{leftwordgroup}\\
		\begin{rightwordgroup}{\large $\uparrow$ User Stack}
			\wordbox[lr]{2}{Bank 2 (User Data)\\$16384 \text{w} \approx 16 \text{kiw}$} \\
		\end{rightwordgroup}
		\begin{leftwordgroup}{\small \texttt{0xffff}}
			\bitbox[lrb]{16}{}
		\end{leftwordgroup}

	\end{bytefield}
	
\end{figure}

\subsubsection{\label{section:banking}Banking}

Banken sind externe Memory Module, die eingesteckt werden können.
Alle Banken sind gleich groß ($16\text{kiw} = 32\text{ kib}$) und der Computer unterstützt maximal $65536$ unterschiedliche Banken.
Jede Bank hat dabei eine ID (BID), die von $0$ bis $65535$ reicht.

Der Computer hat zwei Bank-Slots (Slot 1 \texttt{0x8000 - 0xbfff} und Slot 2 \texttt{0xc000 - 0xffff}).
Er kann nun auf jede dieser Slots eine der theoretisch $65536$ Banken legen
\footnote{Es ist dabei möglich, die gleiche Bank auf beide Slots zu legen, auch wenn das nur bedingt nützlich ist.}
Das Banken legen lässt sich über die SBK1- (Select Bank Slot 1) und SBK2- (Select Bank Slot 2) Instruktion erreichen.
Die BIN kann dabei als Konstante oder als Register vorliegen. Die Notation ist dabei wie folgt:

\text{SBK<1/2> <BIN-Register/Konstante>}

Somit führt das Beschreiben/Lesen an einer Adresse welche einem Bank-Slot zugeordnet ist, zum Beschreiben/Lesen der ausgewählte Bank.

Durch dieses System lassen sich $65536 \cdot 16\text{kiw} = 1\text{ Giw} = 2\text{ Gib}$ an Arbeitsspeicher ansprechen.

Das Bankensystem dient zudem dazu, Prozesse voneinander zu isolieren, da der Computer im Usermode die Bank nicht verändern kann, siehe \autoref{section:supervisor}.

\subsubsection{\label{section:stack}Hardware Stack}

Der Stack (oder, auch Stapelspeicher) ist eine LIFO (Last In First Out) Datenstruktur.
Sie dient hauptsächlich dazu, Subroutinen zu verwalten.

Er funktioniert dabei wie ein Papierstapel.
Es kann ein Wert auf den Stack gelegt, werden (PUSH-Instruktion) oder ein Wert von oben abgehoben werden (POP-Instruktion).
Wobei der Wert, der auf den Stack gelegt bzw. abgehoben werden soll, entweder im Quellen-Register bzw. Zeil-Register oder als Konstante vorliegt.
Die Notation ist dabei wie folgt:

\text{PUSH <Quellen-Register/Konstante>}

\text{POP  <Ziel-Register>}

Der Stack liegt dabei physisch in Memory vor.
Jedes Element des Stacks okkupiert dabei eine Memory-Zelle (16 Bit).
Das Stack-Point Register-(SP) hält die Adresse, welche die nächste freie Memory-Zelle zeigt, die eins über dem obersten Wert des Stacks liegt.
Der Stack wächst dabei von hohen Adressen zu niedrigen Adressen, wie in \autoref{fig:stack-dir} zusehen.

Bei einer PUSH Instruktion wird zuerst an die Stelle auf die SP zeigt der Wert des Quellen-Register/Konstante geschrieben und darauf der SP um $1$ dekrementiert.
POP dagegen inkriminiert zuerst den SP um $1$ und kopiert dann den Wert von der Stelle auf welche SP zeigt in das Ziel-Register.

Zudem gibt es noch die RET- und CALL-Instruktionen. \text{RET} ist äquivalent zu \text(POP IP) und CALL ist äquivalent zu \text{PUSH IP; MOV IP <Quellen-Register/Konstante>}.
Die Notation ist dabei wie folgt:

\text{RET}

\text{CALL <Quellen-Register/Konstante>}

Fundamental hat der Computer zwei Stacks.
Der Supervisor-Stack beginnt bei \texttt{0xc7fff} (kleiner werdend) und wird genutzt, wenn die SUP Flagge gesetzt ist.
Der User-Stack beginnt bei \texttt{0xffff}, also am Ende des Bank Slots 2 und wird genutzt, wenn die SUP Flagge nicht gesetzt ist.

\begin{figure}[h]
	\centering
	\caption{Stack Aufbau}
	\label{fig:stack-dir}

	\begin{bytefield}[leftcurly=., rightcurly=.]{16}
		\begin{rightwordgroup}{\small niedrige Addressen}
			\wordbox[lrb]{1}{}
		\end{rightwordgroup} \\
		\begin{leftwordgroup}{\small SP $\rightarrow$}
			\wordbox[lrb]{1}{}
		\end{leftwordgroup} \\
		\wordbox[lrb]{1}{Wert n} \\
		\begin{rightwordgroup}{\small $\uparrow$ Stack-Richtung}
			\wordbox[lrb]{1}{...}
		\end{rightwordgroup} \\
		\wordbox[lrb]{1}{Wert 1} \\
		\wordbox[lrb]{1}{Wert 0} \\
		\begin{rightwordgroup}{\small hohe Adressen}
			\wordbox[lr]{1}{}
		\end{rightwordgroup}
	\end{bytefield}

\end{figure}

\subsection{\label{section:io}Input/Output}

Der Computer hat zudem die Möglichkeit mit verschieden IO-Geräte zu interagieren.
Die Kommunikation läuft über die sogenannten IO-Ports.
Der Computer hat physische Anschlüsse an denen IO-Geräte angesteckt werden können.
Die Struktur dieser Anschlüsse sieht wir folgt aus:

\begin{center}
	\begin{table}[h]
		\caption{\label{table:IOPins}}
		\begin{tabular}{l | l}
			\# & Funktion \\
			\hline
			00 & GND \\
			01 & Vcc \\
			02-17 & 16Bit Daten \\
			18 & Iin-Enable \\
			19 & Din-Enable \\
			20 & Dout-Request \\
			21 & Dout-Accept \\
			22 & CLK\_R
 		\end{tabular}
	\end{table}
\end{center}

\subsubsection{\label{section:IO-Port}Kommunikation zwischen IO-Geräten und dem Controller}
Die Interaktion zwischen IO-Controller und dem IO-Gerät funktioniert dabei über drei Instruktionen, wie in \autoref{table:IOInstructions} zusehen ist.

\begin{center}
	\begin{table}[h]
		\caption{\label{table:IOInstructions}}
		\begin{tabular}{r | r | l}
			kurzform & Ausgeschrieben & funktion \\
			\hline
			Iin & Instruktion Eingang & Computer schreibt eine Instruktion ans I/O-Gerät \\
			Din & Daten Eingang & Computer schreibt 16-Bit Daten ans I/O-Gerät \\
			Dout &  Daten Output & Computer liest 16-Bit Daten vom I/O-Gerät
 		\end{tabular}
	\end{table}
\end{center}

Jede Interaktion benötigt dabei mehrere Schritte, die genaue Definition der Kommunikationsschritte wird dabei durch jede instruktion eigen festgelegt.
Ein allgemeiner standard Ablauf (wie z.B. der der später definierten IO-Instruktion "rmn") ist in \autoref{table:IO_Schem} zusehen.

\begin{center}
	\begin{table}[h]
		\caption{\label{table:IO_Schem}}
		\begin{tabular}{l | l | l | l | l | l | l}
			 Bereich & Clock 1 & Clock 2 & ... & Clock n & Clock $n+1$ & ... \\
			\hline
			Iin & 1 & 0 &   & 0 & \\
			Din & 0 & 1 &   & 0 & \\
			Dout & 0 & 0 &   & 1 & \\
			Data$0-7$ & InstructionID & Variable &   &   & Rückgabewert \\
			Data$8-15$ & 8b Variable & Variable &   &   & Rückgabewert
 		\end{tabular}
	\end{table}
\end{center}

Die Pins Iin und Din werden dabei durch den Computer für einen Clock-Tick gesetzt, sobald die Daten/Instruktionsinformation am Dateneingang an liegen;
Wenn das IO-Gerät etwas zu dem Computer senden will, dann setzt es Dout-Request und der Computer nimmt darauf mit dem Setzten von Dout-Accept an, worauf hin das IO-Gerät die Daten zu dem Computer übermittelt.

\subsubsection{\label{section:IO-Instructions}Ansprechen des Controllers im Code}
das Oben genannte verhalten ist die Kommunikation nachdem der IO-Controller die Instruktionen übersetzt hat, dafür muss der Controller wie folgt angesprochen werden:

Um Etwas zu dem IO-Gerät zu schreiben müssen folgende schritte im Programm stehen: \autoref{table:IO_Assembler_Schem}

\begin{center}
	\begin{table}[h]
		\caption{\label{table:IO_Assembler_Schem}}
		\begin{tabular}{l | l | l | l | l | l | l}
			 Bereich & Clock 1 & Clock 2 & ... & Clock $n$ & Clock $n+1$ & ... \\
			\hline
			InsName 				& Iout 		  & Dout        &   & Dout        & Dout       \\
			Variable 1 				& Geräte-ID   & Geräte-ID   &   & Geräte-ID   & Geräte-ID  \\
			Var2 / Konstante b0-7 	& IO-Befehl   & 8b Variable &   & 8b Variable & 8b Variable\\
			Var2 / Konstante b8-15 	& 8b Variable & 8b Variable &   & 8b Variable & 8b Variable
 		\end{tabular}
	\end{table}
\end{center}
Der InsName ist hier der Name aus den Allgemeinen Instrukionen, wie in \autoref{table:instructions} definiert, Iout/Dout definiert, welcher der obigen Iin/Din pins gesetzt wird.
Die Geräte-ID ist die ID, mit der sich das IO-Gerät bei dem Controller meldet und die vom Controller auf den richtigen Anschluss aufgelöst wird.
Die Variable $2$ oder Konstante wird vom IO-Controller komplett unverändert an das IO-Gerät weiter gegeben.

\subsubsection{\label{section:IO-Device-Instructions}Standart IO-Instruktionen}

Die Momentan bestehenden I/O-Instruktionen sind in \autoref{table:IOInstructions}, aber diese sind im Programm frei veränderlich, solange das externe Gerät die gleiche Interpretation der Anweisungen hat.

\begin{center}
	\begin{longtable}{p{0.045\textwidth} | p{0.1\textwidth} | p{0.1\textwidth} | p{0.40\textwidth} | p{0.22\textwidth}}[h]
	\kill
		\caption{\label{table:IOins}I/O-Instruktionen}
		\endhead
			ID & Gerätetyp & Name & Funktion & Verhalten \\
			\hline
			\texttt{0x00} & All & ls & gibt die ID des Gerätes zurück & Iin(Instruktion); n$*$Dout(Antworten)\\
			\hline
			\texttt{0x01} & Drive & rsn (read singel normal) & Lesen eines einzelnen 16-Bit werts von einer 24-Bit Addresse & Iin(Instruktion); Din(Addresse); 1$*$Dout(Antwort) \\
			\hline
			\texttt{0x02} & Drive & rmn (read multiple normal) & Lesen einer reihe von bis zu $65535$ 16 Bit Werten von 24-Bit Addressen aus & Iin(Instruktion); Din(startAddresse); Din(Länge); n$*$Dout(Antworten) \\
			\hline
			\texttt{0x03} & Drive & wsn (write singel normal) & Schreiben eines einzelnen 16 Bit werts von einer 24-Bit Addresse & Iin(Instruktion); Din(Addresse); Din(Daten); Dout(bestätigung) \\
			\hline
			\texttt{0x04} & Drive & wmn (write multiple normal) & Schreiben einer reihe von bis zu $65535$ Werten an 24-Bit Addressen & Iin(Instruktion); Din(startAddresse); n$*$Din(Daten); Dout(bestätigung) \\
			\hline
			\texttt{0x05} & Drive & rsb (singel read big) & Lesen eines einzelnen 16-Bit werts von einer 40-Bit Addresse & Iin(Instruktion); Din(Addresse); Din(Addresse); 1$*$Dout(Antwort) \\
			\hline
			\texttt{0x06} & Drive & rmb (multiple write big) & Lesen einer reihe an von bis zu $65535$ Werten von 40-Bit Addressen aus & Iin(Instruktion); Din(startAddresse); Din(startAddresse2); Din(Länge); n$*$Dout(Antworten) \\
			\hline
			\texttt{0x07} & Drive & wmb (singel write big) & Schreiben eines einzelnen 16-Bit werts von einer 40-Bit Addresse & Iin(Instruktion); Din(Addresse); Din(Addresse);Din(Daten); 1$*$Dout(bestätigung) \\
			\hline
			\texttt{0x08} & Drive & wmb (write multiple big) & Schreiben einer reihe von bis zu $65535$ Werten 16 Bit werten an 40-Bit Addressen & Iin(Instruktion); Din(startAddresse); n$*$Din(Daten); Dout(bestätigung) \\
			\hline
			\texttt{0x09} & Drive & rfn (read file normal) & Lesen einer gesamten Datei (24-bit Namen)  & Iin(Instruction); Din(Name); n$*$Dout(Antwort) \\
			\hline
			\texttt{0x0a} & Drive & wfn (write file normal) & Schreiben einer neuen Datei (24-bit Namen) & Iin(instruction); Din(Name); n$*$Din(daten); Dout(bestätigung) \\
			\hline
			\texttt{0x0b} & Drive & rfpb (read file-part big) & Lesen eines teils einer Datei (24-bit Namen) & Iin(instruction); Din(Name); 2$*$Din(läge); n$*$Dout(Daten) \\
			\hline
			\texttt{0x0c} & Drive & wfpb (write file-part big) & Anhängen von Daten an eine Datei(24-bit Namen) & Iin(instruction); Din(Name); Din(länge); n$*$Din(Daten); Dout(bestätigung)
	\end{longtable}
\end{center}

\subsubsection{\label{section:persmissionIO}Berechtigungsliste}

Der Supervisor-mode hat die berechtigungen zu allen I/O-Interaktionen, für normale Prozesse wird die Berechtigungsliste in einer Reihe an RAM-Chips gespeichert, deren Adressen sich mit dem wechseln zwischen den verschiedenen Banks ändern.
Gesetzt werden können sie nur durch den Supervisor, wobei auch dieser die RAM-Adressen nicht manuel ändern kann.

\subsection{\label{section:interrupts}Interrupts}

Interrupts sind Unterbrechungen im Programmablauf.
Wenn ein Interrupt gemeldet wird, wird dieser im nächsten Instruktions-Zyklus bearbeitet.
Für diesen Zyklus, wird, je nach Interrupt-Quelle, nicht die Instruktion an der Stelle von IP sondern von einem IV (Interrupt Vektor) geladen.
Es gibt im Computer vier verschieden Interrupt Quellen, wobei jede ein fest-verbauten IV hat, dies ist in \autoref{table:iv} zusehen.

Interrupts können generell (sowohl im Usermode als auch im Supervisormode) deaktiviert werden, mit Ausnahme von Software-Interrupts, durch das setzen der OINT Flagge (nur vom Supervisor).
Für ein feinere Einstellung gibt es die OVIOI, OVTI1, OVTI2 Flaggen welche wie in \autoref{table:iv} zusehen, einen speziellen Interrupt deaktivieren.
Diese Flaggen, übernehmen dies aber nur im Supervisor.
Alle diese Flaggen befinden sich übrigens in den letzten 8 Bit des FLAG Register, womit sie nur im Supervisormode verändert werden kann.

Die INT Instruktion löst ein Software-Interrupt aus.
Dieser kann nicht deaktiviert werden.
Diese Instruktion kann sowohl im Supervisor und im Usermode ausgeführt werden.
Die Instruktion nimmt keine Operntanten an.
Die Notation ist dabei wie folgt:

\text{INT}

\begin{center}	
	\begin{table}[h]
		\caption{\label{table:iv}}
		\begin{tabular}{l | l l | l}
			Interrupt-Quelle & IV Name & IV Standard Wert & Flagge zum Deaktivieren \\
			\hline
			IO-Interrupts & IV-IO & \texttt{0x3fff8} & OVIOI \\
			INT-Instruktion & IV-INT & \texttt{0x3fffa} &  \\
			Timed-Interrupts & IV-TI1 & \texttt{0x3fffc} & OVTI1 \\
			Timed-Interrupts & IV-TI2 & \texttt{0x3fffe} & OVTI2
		\end{tabular}
	\end{table}
\end{center}

\subsubsection{Timed-Interrupts}

Der Computer besitzt zwei interne Timer je 32 Bit groß.
Jeder Timer started bei $0$ und zählt (bei jedem Clock Schlag) um $1$ bis zu seinem eingestellten End Wert.
Bei erreichen dieses Werts löst der Timer einen dementsprechenden Interrupt aus.

Jeder Timer kann in vier Modi Arbeit, wie in \autoref{table:TimerModi} zusehen.
Der Timer Modus kann über die TM1 und TM2 (steht für Timer1 Mode, Timer2 Mode) Instruktion gesetzt werden, welcher entweder ein Quellen Register oder eine Konstante an nimmt, wobei die Notation wie folgt aus sieht:

\text{TM<1/2> <Quellen-Register/Konstante>}

Der Endwert wird über die SSTL1, SSTL2 und SSTH1, SSTH2 erledigt.
Wobei SSTL<1/2> die ersten 16 Bit und SSTH<1/2> die letzten 8 Bit des Endwert-Registers setzt.
Der Endwert kann dabei als Konstante oder als Quellen-Register vorliegen.
Die Notation ist dabei wie folgt:

\text{SSTL<1/2> <Quellen-Register/Konstante>}

\text{SSTH<1/2> <Quellen-Register/Konstante>}

Die aktuell Clock Geschwindigkeit, ist in mit CFL und CFH instruktion zu bekommen.
CFL lädt die ersten 16 bit der Clock Geschwindigkeit in das Ziel-Register und CFH die letzten 8 bit in das Ziel-Register.
Die Frequenz ist dabei In Herz (Schläge pro Sekunde) angegeben.
Die Notation ist wie folgt:

\text{CFL <Ziel-Register>}

\text{CFH <Ziel-Register>}

\begin{center}
	\begin{table}
		\caption{\label{table:TimerModi}}
		\begin{tabular}{l  l | L{9cm}}
			Timer Modus & Modus ID & Funktion \\
			\hline
			Suspended & \texttt{0x0} & Timer zählt nicht hoch, behält aber sein aktuellen Wert. Das Hochzählen wird fortgesetzt sobalt der Timer in Continues oder Singel Mode gesetzt wird \\
			Reset & \texttt{0x1} & Timer ist Inaktive und der Zähler wird auf 0 gesetzt \\
			Continues & \texttt{0x2} & Timer zählt hoch; bei ereichen des Ziels, löst Interrupt aus und fängt von vorne an zuzählen. \\
			Singel & \texttt{0x3} & Timer zählt hoch; bei ereichen des Ziels, löst Interrupt aus und schalte in Reset Modus um
		\end{tabular}
	\end{table}
\end{center}

\subsubsection{\label{section:ioInterrupt}}

Auch IO-Geräte können als Interrupt-Quelle fungieren.
Dabei gibt es keine Möglichkeit, vom Computer her Interrupt eines IO-Geräts zu deaktivieren oder aktivieren.
Dies muss gegebenenfalls über das IO-Protokoll, siehe \autoref{section:io}, gemacht werden.
Es können natürlich alle IO-Interrupts auf einmal mit der OVIOI-Flagge gemacht werden.

\section{Kommentar zur Specification}

\subsection{\label{section:comment:datalength}16 bit Daten/Address Länge}

Die Address- und Datenlänge besagt, wie viele Binäre Ziffern (bits) für eine Address und Daten verwendet werden.
Je mehr Ziffern man verwendet desto größere Zahlen können in einer Operation verarbeitet werden wobei die maximal repräsentierbare Zahle $2^n - 1$ ist wenn $n$ die Anzahl der Binären Ziffern (= Bits) ist und wenn man mit $0$ anfängt zu zählen.
Siehe \autoref{table:max_zahlen}

Ein eine $n$ stellige Binär Zahl wobei $n$ teilbar durch $8$ ist, ist dabei relativ angenehm, $8$ bit = $1$ byte.
Das Byte ist dabei die basis Einheit für so gut wie alle informationstechnischen Standards.
Daher ist es gute eine solches $n$ zu wählen.
Zudem kommen einige elementar ICs, z.B. Buffer oder Register, immer mit 8 bits.

Jedoch gilt je mehr Bits man verwendet, desto mehr Schaltung brauchen man, desto mehr Stromverbrauch.
Da wir wie zwar nicht speziell auf Platz und Stromverbrauch optimieren, aber trotzdem ein limitiertes Budget haben, können wir auch nicht eine beliebig große Daten/Address Länge wählen.

Wir haben uns daher für $16$ bit entschieden, der laut \autoref{table:max_zahlen} Zahlen bis zwischen $0$ und $65535$ darstellen kann.
Diese Menge ist gerade große genug, um für die meisten Programme große genüge Zahl abzubilden
\footnote{Für Programme die Zahlen welche $> 65535$ darstellen wohlen ist es ratsam immer zwei oder mehr Speichereinheiten zunehmen oder bei Berechnungen, selbige auf zwei oder mehr Schritte auf zuteilen}.

Die Entscheidung zur größe der Daten/Address Länge ist sehr ausschlaggebend, daher haben wir diese zuerst festgelegt.
Sie wird für viele weitere Entscheidung eine wichtige Rolle spielen.
Wichtig ist nur das wir mit unseren $16$ bit maximal $65536$ Zustände oder Zahlen von $0$ bis $65535$ darstellen können.

\begin{center}
	\begin{table}[h]
		\caption{\label{table:max_zahlen} Maximale repräsentierbare Zahlen (startend mit 0)}
		\begin{tabular}{ l | l }
 		$n$ & $n^2 - 1$ \\
		\hline 
		2 & 3\\  
		4 & 15\\
		8 & 255\\
		16 & 65535\\
 		32 & 4294967295\\
 		64 & 18446744073709551615\\
		\end{tabular}
	\end{table}
\end{center}

\subsection{\label{section:comment:register_number}Register Anzahl}

Der Computer hat 8 Register.
Wir haben uns für Acht aus folgenden Gründen entschieden:
Zu erst die minimale Anzahl an Registern die wirklich gebraucht würde, ist $5$! Man braucht mindestens zwei allzweck Register um binäre Rechenoperation durch zu führen, einen Stackpointer, einen Instruktion Pointer und einen Ort wo man die Flaggen speichern kann.
\footnote{Theoretisch ist es möglich das Flaggen Register wegzulassen, wir haben uns aber für eine solches Register entschieden siehe \autoref{com:conditionals}}.

Fünf lässt sich nicht mehr mit $2$ bits repräsentieren ($2^2 = 4$), daher muss man $3$ bit ($2^2 = 8$) nehmen.
Der Grund warum wir nicht mehr genomen haben hat mit der Encodierung von Instruktionen zutun siehe \autoref{com:insEnc}.
Somit haben sich $8$ Register als das Optimum ergeben

\subsection{\label{com:sup}Gedanken Hinter dem Supervisormode}

Wir haben uns entschieden eine Art Berechtigungssystem in der Computer einzubauen.
Eine Rechner der nur einfache Programm ausführt um zu Beispiel eine LED oder ein LCD-Display zusteueren, wie es z.B. ein ESP32 oder ein ATMega328p macht, ist so ein System nicht nötig.
Wir hatten jedoch vor mit unserem Computer die Möglichkeit zu schaffen ein Betriebssystem ähnliches Programm (Supervisor) laufen zulassen.

Hier für hat man ein mal den Supervisor, der bei Start des Computer anfängt zulaufen, und Programme, welche im Usermode ausgeführt werden, sogenannte Prozesse.
Dabei sieht ein typischer Programmablauf ist dabei in gezeigt.

Wichtig ist, das sobald ein Prozess beendet wurde, der Supervisor an dieser Stelle wieder anfängt und den nächsten Prozess started.

Ein Prozess kann auch Funktionen des Supervisor nutzten über Software Interrupts, da bei einem Interrupt, der Computer in den Supervisormode wechselt.
So kann der Prozess, bevor er den Interrupt auslegt, ein oder mehrere Register nutzten um Werte an den Supervisor zu übergeben.
Z.B. kann er eine Register nutzten um dem Supervisor zusagen was er tun soll, z.B. dem Prozess zugang zu einem IO-Gerät zugeben oder etwas in eine Datei zuschreiben.
Diese Art von Kommunikation werden auch System-Calls genannt und sind die Basis für jedes moderne Betriebssystem.

Ein solcher Supervisor kann sehr mächtig sein:

\begin{enumerate}
	\item Abstraktion der Hardware: Oft ist die IO-Configuration von Setup zu Setup sehr verschieden. Ein Prozess was IO-Nutzen möchte hat oft den Nachteil dass es für ein bestimmte Hardware setup geschrieben wurde. So z.B. ein Prozess was Daten einer SD-Karte ausließt und diese anzeigt. Wenn jedoch man jetzt eine Floppy-Laufwerk anschließt, so kann man das Prozess zum Auslesen nicht verwenden, da es nur die Kommuntiation mit einer SD-Karte kennt. Der Supervisor könnte an dieser Stelle ein Interface über System-Calls bieten welches unabhänige von dem Gerät ist. So im diesem Beispiel ein Dateisystem, auf welches Prozesse zugreifen können. Somit übernimmt der Supervisor die Kommuntiation mit der Hardware.
	
	\item Teilung der Rechenzeit: Der Computer so viele Features er doch hat, ist stark limitiert vor allem was Rechengeschwindigkeit betrifft. Wenn man nun mehrer Programm hat, welche ausgeführt werden sollen, so wäre es natürlich sehr einfach sie der Reihe nach auszuführen. Jedoch gibt es bessere Wege, so z.B. das der Computer jedem Prozess nur eine Bestimmte Rechenzeit gibt und dann den nächsten Prozess ausführt. Das kann erreicht werden durch folgenden Ablauf: Der Supervisor setellt vor dem ausführen des Prozesse eine Timed-Interrupt. Dann übergibt der Supervisor den Computer dem Prozess, welcher dann seine Programm ausführt. Dies machter bis der Timed-Interrupt ausgelöst wird und der Computer wieder in den Supervisormode wechselt. Dieser speichert nun alle Register und Banken Configuration des Prozesse und übergibt einem anderen Prozesse den Computer. Wenn nun ein schon angefanger Prozess wieder gestarted werden soll läd der Supervisor wieder die Register und Banken des Prozesse und übergibt die Außführung wieder an den Prozess. Somit kann der Computer zwischen Prozessen hin und herschallten, was die Illusion gibt, das der Computer diese gleichzeitig ausführt.
	
	\item Isolation von Prozessen: Programme sind meist nie perfekt. Vor allem sowas wie Bufferoverflows und andere Fehler dieser Art tretten in Low-Level Systeme gerne auf. Aus diesem Grund ist es wichtig Prozesse von einander zu isolieren. Nehmen wir an Prozess A hat ein Fehler welcher dafür sorgt das er den gesammten RAM anfängt voll zuschreiben. Um jetzt Prozess A daran zuhinern Prozess B zu überschreiben, ist es dem Prozess nicht gestattet auf den Arbeitsspeicher von Prozess B zuzugreifen. Nur der Supervisor kann zwischen den Prozessen wechseln
	\footnote{Natürlich kann auch der Supervisor fehlerhaft sein. Jedoch hatten wir bei dieser Maßnahme nicht nur fehlerhaft sondern auch schlicht böswillige Prozesse im Kopf. Natürlich ist dies unwahrscheinlich dass so etwas jemals eintreten wird, jedoch war unsere Idee von Anfang an eine Computer zu bauen der im Internet stehen könnte und die dementsprechenden Sicherheitsmaßnahmen hat}.
\end{enumerate}

Wenn man so etwas will kann dass auch auf einem ATMega328p gemacht werden, jedoch nicht ohne massive Leistungsverluste.
Wenn so ein Berechtigungssystem jedoch direkt in die Hardware des Computers einfließt sorgt das für eine viel effektiveren Computer.

Wenn man tatsächliche nur Programme schreiben will welche \"nur\" ein LED oder LCD-Display steuern soll, kann man das mit unserem Computer auch machen, indem man einfach diese Programm im Supervisor laufen lässt.

\subsection{\label{com:SoftwareInterrupt}Zur fehlenden Deaktivierung der Software Interrupts}

Die INT-Instruktion löst wie in \autoref{section:interrupts} einen Software Interrupt aus welcher nicht durch die OINT- Flagge deaktiviert werden kann.

Um die Motivation hinter dieser Entscheidung zu verstehen ist zu wissen, dass der Software Interrupt dazu gedacht ist um aus dem Usermode in den Supervisormode zu wechseln.
Und zwar in einem kontrollieren Weg, sodass es nicht möglich ist beliebigen Programm-Code als User mit Supervisor Privilege auszuführen.
Daher wird auch nicht direkt nachdem Ausführen der INT-Instruktion an dieser Stelle weiter ausgeführt sonder Programm-Code welcher an der Position von einem IV sich befindet, welcher nicht verändert werden kann und schluss endlich irgendwelchen Supervisor Code ausführt.

Dabei ist dies der einzige Weg, nebst den Computer zu resetten um Code im Supervisormode auszuführen aus der Position des Usermodes.
Wenn es nun die Möglichkeit gäbe Software Interrupts zu deaktivieren und man in den Usermode wechseln würde, kann man nicht mehr zurück in den Supervisormode kommen, da im Usermode keine Interrupts aktivieren oder deaktiviert werden können.
Von daher ist es Sinnbefreit dem Computer die Möglichkeit zugeben Software Interrupts zu deaktivieren.

\subsection{\label{com:} Zuordnung des IO-Slot zu IO-Type}

Bei den IO-Geräten wird momentan als ID die ID des Anschlusses verwendet und der Supervisor hat die Aufgabe über die ls-funktion die Anschluss-IDs auf die Geräte-IDs zu mappen.
Idealer weise würde dies un dem IO-Controller umgesetzt werden, aber da würde es für uns momentan zu kompliziert, weshalb wir uns entschieden haben das in der Software zu machen.

\printbibliography{}

\end{document}

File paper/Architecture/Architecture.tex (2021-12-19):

\documentclass{scrartcl}

\usepackage{graphicx}
\usepackage[siunitx, RPvoltages, european]{circuitikz}

\usepackage[ngerman]{babel}
\usepackage[utf8]{inputenc}
\usepackage{amsmath}
\usepackage{amssymb}
\usepackage[T1]{fontenc}
\usepackage{xcolor}
\usepackage{tikz}
\usepackage[breaklinks=true]{hyperref}
\usepackage[utf8]{inputenc}
\usepackage[babel,german=quotes]{csquotes}
\usepackage[style=numeric, backend=biber]{biblatex}
\usepackage{listings}
\usepackage{bytefield}
\usepackage{longtable}

\addbibresource{ref.bib}

\graphicspath{ {../images} }

\KOMAoptions{parskip=full}

\begin{document}
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

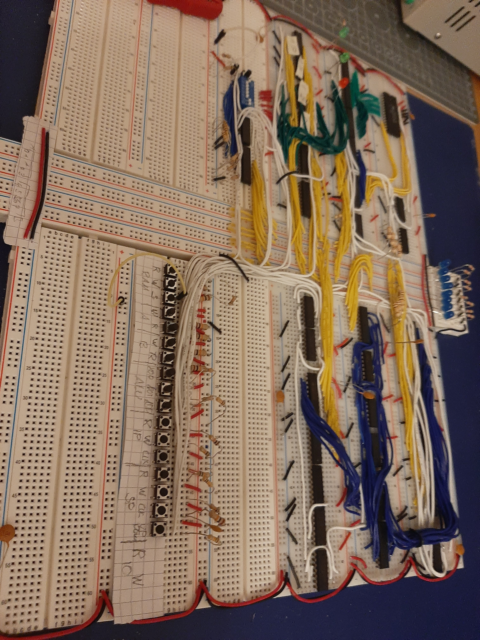
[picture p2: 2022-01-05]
images/Computer_V01_Overview_03.jpg

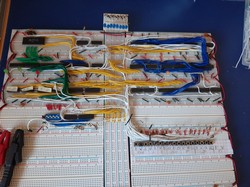
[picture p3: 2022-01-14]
images/Computer_V01_Overview_01.jpg

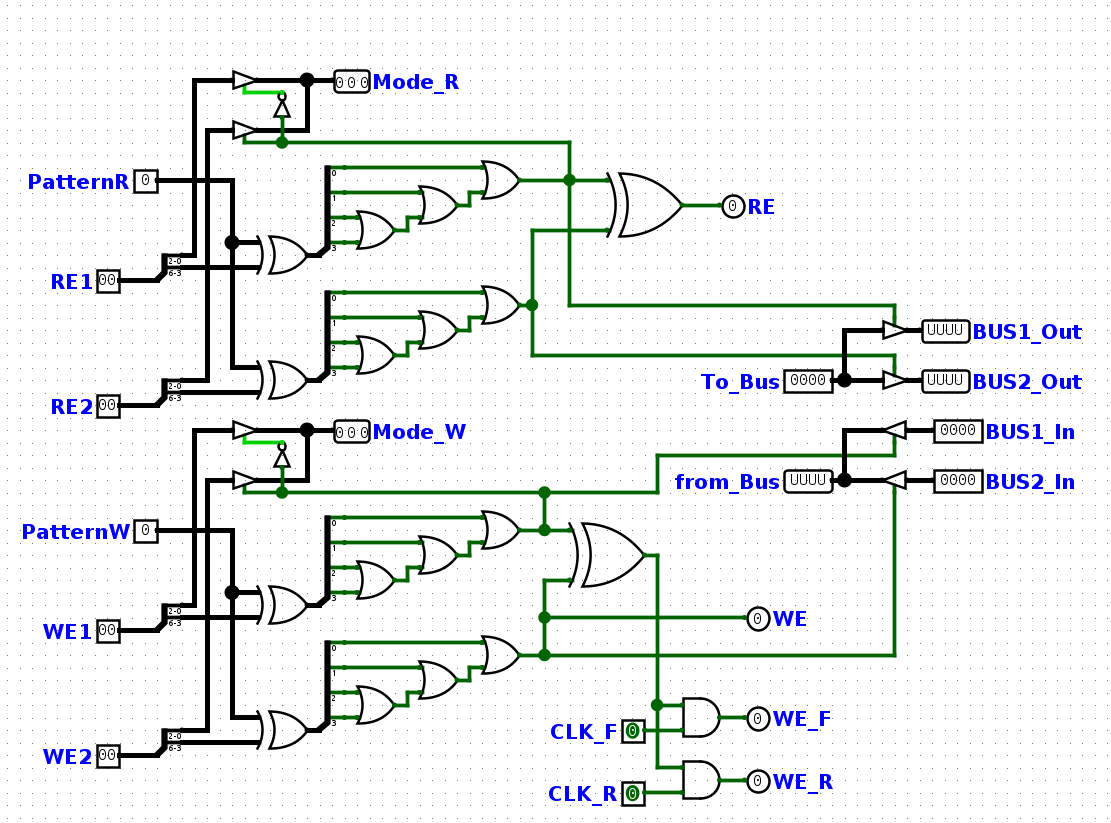
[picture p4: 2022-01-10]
images/logisim_schematic.png

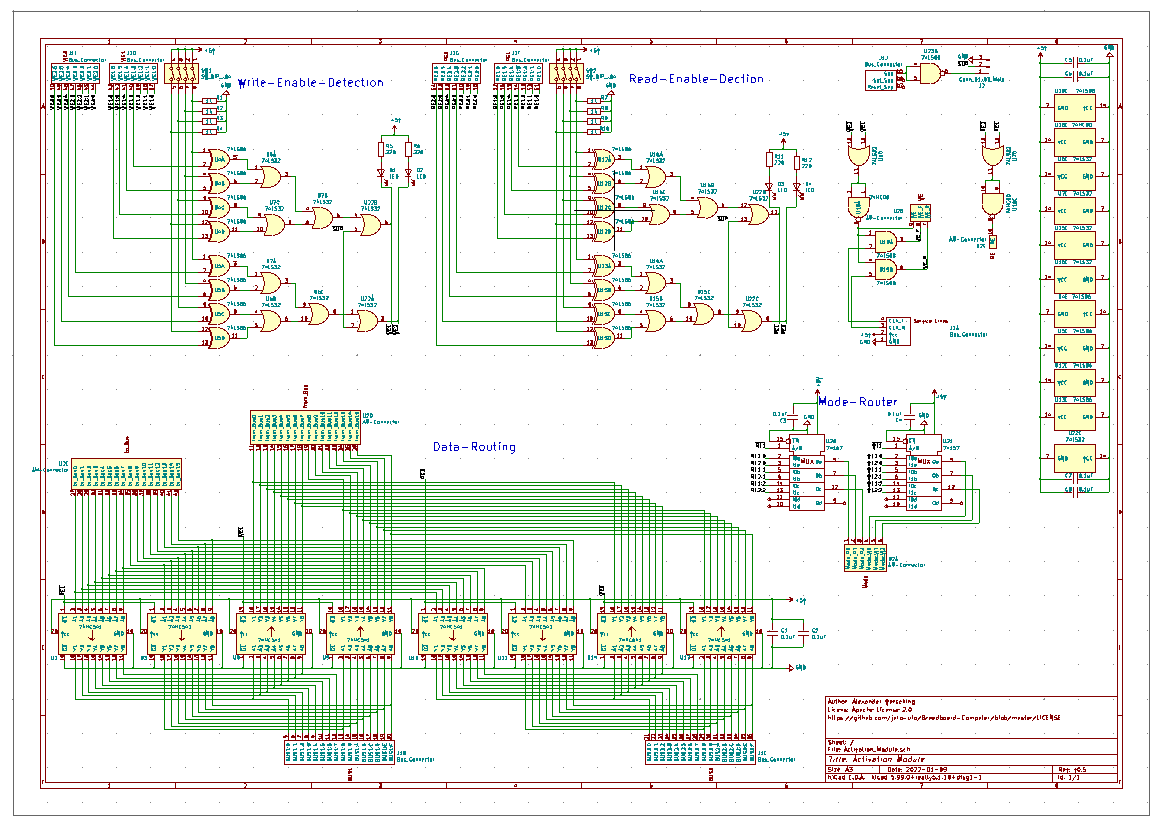
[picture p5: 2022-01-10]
images/kicad_schematic_.png

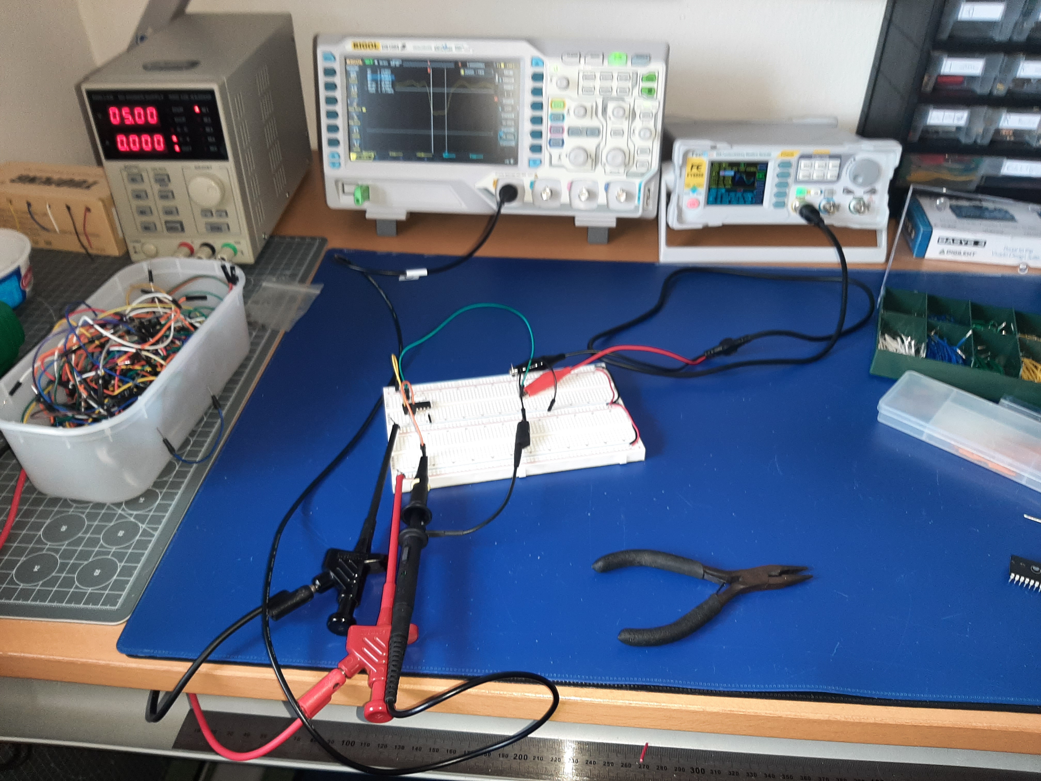
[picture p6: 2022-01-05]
images/Activation_Module_V01_Overview_01.jpg

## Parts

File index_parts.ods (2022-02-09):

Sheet: Part Index
list of electronic parts
Part | Shift | Description | Link | Datasheets | Price
ZIF | TEX 24 | IC-Sockel, 24-polig, Burn-in-Sockel, Nullkraft | https://www.reichelt.de/ic-sockel-24-polig-burn-in-sockel-nullkraft-tex-24-p21312.html?trstct=pol_2&nbc=1 | https://cdn-reichelt.de/documents/datenblatt/C130/TEX%23IMP.pdf | 10.67 €
XOR-Gate | CD 4030BE TEX | XOR-Gate, Quad, 3 ... 18 V, DIL-14 | https://www.reichelt.de/xor-gate-quad-3--18-v-dil-14-cd-4030be-tex-p216648.html?&nbc=1 | https://cdn-reichelt.de/documents/datenblatt/A200/CD4030B_ENG_TDS.pdf | 0.32 €
USB <-> Serial | DEBO MUSB2UART 2 | Entwicklerboards - microUSB Buchse auf UART, CP2102 | https://www.reichelt.de/entwicklerboards-microusb-buchse-auf-uart-cp2102-debo-musb2uart-2-p266052.html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 |  | 5.02 €
Taster | RND 210-00194 | PCB 12 VDC 50 mA | https://www.reichelt.de/printtaster-tht-2-45-n-6-x-6-x-7-mm-rnd-210-00194-p226415.html |  | 0.15 €
SRAM | UT6264C-70 | 8K x 8, 4.5V … 5.5V, 70 ns, PDIP-28, A13 | https://www.reichelt.de/sram-64-kb-8-k-x-8-4-5-5-5-v-dil-28-6264-70-p2676.html?&trstct=pos_1&nbc=1 | https://cdn-reichelt.de/documents/datenblatt/A300/UT6264.PDF | 2.10 €
Shift Bit Register | MOS 4014 | Shift Register, 8-Bit, 3 ... 15 V, DIP-16 | https://www.reichelt.de/shift-register-8-bit-3--15-v-dip-16-mos-4014-p12556.html?&trstct=pos_2&nbc=1 | https://cdn-reichelt.de/documents/datenblatt/A200/mos4014.pdf | 0.58 €
R Kit | QUAD 201711P003 | Kohleschicht-Widerstand 0,5 W, 1 Ohm - 1M Ohm, 400 Stück | https://www.reichelt.de/kohleschicht-widerstand-0-5-w-1-ohm-1m-ohm-400-stueck-quad-201711p003-p280147.html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 | https://cdn-reichelt.de/documents/datenblatt/D800/201711P003_DB_EN.pdf | 13.26 €
Potentiometer Kappe | ACP 9 S | Steckachse, Ø6 x 19,7 mm, schwarz | https://www.reichelt.de/steckachse-6-x-19-7-mm-schwarz-achse-acp-9-s-p111813.html?trstct=pos_0&nbc=1 | https://cdn-reichelt.de/documents/datenblatt/B400/DS_ACP_CA9.pdf | 0.07 €
Potentiometer 1M | ACP 9-L 1M | Einstellpotentiometer, liegend, 1,0 Mohm, 9 mm | https://www.reichelt.de/einstellpotentiometer-liegend-1-0-mohm-9-mm-acp-9-l-1m-p110249.html?trstct=pos_0&nbc=1 | https://cdn-reichelt.de/documents/datenblatt/B400/DS_ACP_CA9.pdf | 0.21 €
OP-AMP | 4558 C | Operationsverstärker, 2-fach, DIP-8 | https://www.reichelt.de/operationsverstaerker-2-fach-dip-8--pc-4558-c-p23637.html?PROVID=2788 | https://cdn-reichelt.de/documents/datenblatt/A200/MC4558.pdf | 0.20 €
NPN-Transistor | 2N2222 | Bipolartransistor, NPN, 60V, 0,8A, 0,5W, TO-18 | https://www.reichelt.de/bipolartransistor-npn-60v-0-8a-0-5w-to-18-2n-2222-p1967.html?trstct=pos_0&nbc=1 | https://cdn-reichelt.de/documents/datenblatt/A100/2N2222-CDIL.pdf | 0.38 €
Inverter | 74HCT 540 | 8A Inverter | https://www.reichelt.de/inverter-3-state-4-5-5-5-v-dil-20-74hct-540-p3419.html?PROVID=2788&r=1 | https://cdn-reichelt.de/documents/datenblatt/A240/74HCT540_74HCT541%23STM.pdf | 0.26 €
NAND-Gate | MOS 4093 | NAND-Gate, 2-Input, 3 ... 20 V, DIP-14 | https://www.reichelt.de/nand-gate-2-input-3-20-v-dip-14-mos-4093-p12636.html?&trstct=pos_14&nbc=1 | https://cdn-reichelt.de/documents/datenblatt/A200/MOS4093STM.pdf | 0.31 €
NAND-Gate | MOS 4068 | NAND-Gate, 8-Input, 3 ... 15 V, DIP-14 | https://www.reichelt.de/nand-gate-8-input-3--15-v-dip-14-mos-4068-p12621.html?search=4068 | https://cdn-reichelt.de/documents/datenblatt/A240/MOS4068_SMD4068%23STM.pdf | 0.26 €
LED Kit | QUAD 201711PO002 | LED-Sortiment 5 mm Superhell + Vorwiderständen, Fassungen | https://www.reichelt.de/led-sortiment-5-mm-superhell-vorwiderstaenden-fassungen-quad-201711o002-p280140.html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 | https://cdn-reichelt.de/documents/datenblatt/A500/201711O002_DB_EN.pdf | 7.51 €
LCD grafic display | LCD-128X64GN AB | LCD grafic display 128x64 | https://www.reichelt.de/lcd-grafikdisplay-128x64-pixel-ge-gn-m-bel--lcd-128x64gn-ab-p197566.html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 | https://cdn-reichelt.de/documents/datenblatt/A500/DEM128064B_SYH-PY.pdf | 16.77 €
Full Adder | 74HC 283 | 4-bit binary full adder with fast carry, DIL-16 | https://www.reichelt.de/4-bit-binary-full-adder-with-fast-carry-dil-16-74hc-283-p3189.html?&nbc=1 | https://cdn-reichelt.de/documents/datenblatt/A240/74HC283%23STM.pdf | 1.55 €
EEPROM | 28C64-150 | 8K x 8, 5V, 150 ns, PDIP-28, A13 | https://www.reichelt.de/eeprom-64-kb-8-k-x-8-4-5-5-5-v-pdip-28-28c64-150-p1946.html?PROVID=2788&r=1 | https://cdn-reichelt.de/documents/datenblatt/A200/28C64B.pdf | 4.38 €
D-Latch | 74HC 573 | non inverted 8Q 1E D-Latch | https://www.reichelt.de/octal-d-type-latch-3-state-2-6-v-dil-20-74hc-573-p3264.html?PROVID=2788&r=1 | https://cdn-reichelt.de/documents/datenblatt/A200/SN74HC573A.pdf | 0.38 €
DIP-Schalter 8 | NT 08 | Dip-Schalter, liegend, 8-polig | https://www.reichelt.de/dip-schalter-liegend-8-polig-nt-08-p13534.html?&trstct=pol_13&nbc=1 | https://cdn-reichelt.de/documents/datenblatt/C200/DS.pdf | 0.30 €
DIP-Schalter 4 | NT 04 | Dip-Schalter, liegend, 4-polig | https://www.reichelt.de/dip-schalter-liegend-4-polig-nt-04-p13532.html?&trstct=pol_4&nbc=1 | https://cdn-reichelt.de/documents/datenblatt/C200/DS.pdf | 0.21 €
DIP-Drehschalter | KMR 10 | Dreh-Codierschalter, 10-polig, vertikal mit Achse | https://www.reichelt.de/dreh-codierschalter-10-polig-vertikal-mit-achse-kmr-10-p9433.html?trstct=pol_0&nbc=1 | https://cdn-reichelt.de/documents/datenblatt/C200/KMR%23ELE.pdf | 2.53 €
DAC | DAC 0808 LCN | D/A-Wandler, 8-bit, 1-Kanal, DIL-16 | https://www.reichelt.de/d-a-wandler-8-bit-1-kanal-dil-16-dac-0808-lcn-p7027.html?PROVID=2788 | https://cdn-reichelt.de/documents/datenblatt/A200/DAC0808LCN%23NSC.pdf | 2.53 €
Crystal 16 MHz | 16,0000-HC49U-S | Standardquarz, Grundton, 16,000000 MHz | https://www.reichelt.de/standardquarz-grundton-16-000000-mhz-16-0000-hc49u-s-p32852.html?PROVID=2788 | https://cdn-reichelt.de/documents/datenblatt/B400/QuarzDatenblatt.pdf | 0.26 €
C Keramik Kit | K/CAP1 | Sortiment, Keramikkondensatoren, 224-teilig | https://www.reichelt.de/sortiment-keramikkondensatoren-224-teilig-k-cap1-p119268.html?trstct=pol_5&nbc=1 |  | 8.53 €
C Electrolitik Kit | K/CAP2 | Sortiment, Elektrolytkondensatoren, 120-teilig | https://www.reichelt.de/sortiment-elektrolytkondensatoren-120-teilig-k-cap2-p119269.html?trstct=pol_6&nbc=1 |  | 8.19 €
BUS-BUFFER-INV | 74HC 244 | 4A Bus-Buffer | https://www.reichelt.de/bus-transceiver-3-state-2-6-v-dil-20-74hc-244-p3177.html?PROVID=2788&r=1 | https://cdn-reichelt.de/documents/datenblatt/A240/74HC240_74HC241_74HC244%23STM.pdf | 0.32 €
BUS-BUFFER | 74HC 541 | Octal BUS Puffer, 3-State Ausgang, 2 ... 6 V, DIL-20 | https://www.reichelt.de/octal-bus-puffer-3-state-ausgang-2--6-v-dil-20-74hc-541-p3260.html?trstct=pos_7&nbc=1 | https://cdn-reichelt.de/documents/datenblatt/A240/74HC540_74HC541%23STM.pdf | 0.85 €
Breadboard | STECKBOARD 1K2V | Experimentier-Steckboard 640/200 Kontakte | https://www.reichelt.de/experimentier-steckboard-640-200-kontakte-steckboard-1k2v-p67678.html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 |  | 3.70 €
Atmega328p | ATMEGA 328P-PU | ATMEGA 328P-PU - Mircoprocessor | https://www.reichelt.de/8-bit-atmega-avr-mikrocontroller-32-kb-20-mhz-pdip-28-atmega-328p-pu-p119685.html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 | https://cdn-reichelt.de/documents/datenblatt/A200/DS_AT168A_PA_328_P.pdf | 2.44 €
555-Timer | NE 555 TEX | Timer-IC, Typ 555, DIP-8 | https://www.reichelt.de/timer-ic-typ-555-dip-8-ne-555-tex-p13397.html?&trstct=pos_0&nbc=1 | https://cdn-reichelt.de/documents/datenblatt/A200/NE555_SA555%23STM.pdf | 0.28 €
Shift Bit Register | 74HC 164 | Schieberegister, 8-Bit, Seriell zu parallel, 2 ... 6 V, DIL-14 | https://www.reichelt.de/schieberegister-8-bit-seriell-zu-parallel-2--6-v-dil-14-74hc-164-p3154.html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 | https://cdn-reichelt.de/documents/datenblatt/A240/74HC164%23STM.pdf | 0.30 €
Counter | MOS 4029 | Counter, 4-Bit, 3 ... 15 V, DIP-16, Up/Down | https://www.reichelt.de/counter-4-bit-3--15-v-dip-16-mos-4029-p12588.html?PROVID=2788 | https://cdn-reichelt.de/documents/datenblatt/A240/MOS4029_SMD4029%23STM.pdf | 0.56 €
Decoder | LS 139 | Decoder/MPX, 2 to 4, 4,75 ... 5,25 V, DIL-16, Inverted | https://www.reichelt.de/decoder-mpx-2-to-4-4-75--5-25-v-dil-16-ls-139-p10613.html?PROVID=2788 | https://cdn-reichelt.de/documents/datenblatt/A240/LS139%23TEX.pdf | 0.79 €
JK Flip-Flop | MOS 4027 | Flip-Flop JK-Type, Dual, 3 ... 15 V, DIP-16 | https://www.reichelt.de/flip-flop-jk-type-dual-3--15-v-dip-16-mos-4027-p12586.html?PROVID=2788 | https://cdn-reichelt.de/documents/datenblatt/A240/MOS4027_SMD4027%23STM.pdf | 0.42 €
NOR-Gate | 74HC 4078 | NOR-Gate, 8-Input, 3 ... 15 V, DIP-14 | https://www.reichelt.de/nor-gate-8-input-3--15-v-dip-14-mos-4078-p12630.html?&trstct=pol_0&nbc=1 | https://cdn-reichelt.de/documents/datenblatt/A240/MOS4078%23STM.pdf | 0.33 €
Counter | M54HC393 | Dual Counter, 4-Bit, 2 ... 6 V, DIL-14, Up | https://www.reichelt.de/counter-4-bit-2--6-v-dil-14-74hc-393-p3212.html?PROVID=2788 | https://cdn-reichelt.de/documents/datenblatt/A240/74HC393%23STM.pdf | 0.48 €
Bargraph-Anzeige | RBG 2000 | 20 Elemente, rot | https://www.reichelt.de/bargraph-anzeige-20-elemente-rot-rbg-2000-p31505.html?&trstct=pol_1&nbc=1 | https://cdn-reichelt.de/documents/datenblatt/A500/RBG2000_SRBG2000_YBG2000%23KIN.pdf | 5.70 €
Bargraph-Anzeige | YBG 1000 | 10 Elemente, gelb | https://www.reichelt.de/bargraph-anzeige-10-elemente-gelb-ybg-1000-p22957.html?&trstct=pol_2&nbc=1 | https://cdn-reichelt.de/documents/datenblatt/A500/RBG1000_RGBG1000_SRBG1000_YBG1000%23KIN.pdf | 1.90 €
Bargraph-Anzeige | YBG 2000 | 20 Elemente, gelb | https://www.reichelt.de/bargraph-anzeige-20-elemente-gelb-ybg-2000-p31508.html?&trstct=pol_3&nbc=1 | https://cdn-reichelt.de/documents/datenblatt/A500/RBG2000_SRBG2000_YBG2000%23KIN.pdf | 4.67 €
Bargraph-Anzeige | GBG 2000 | 20 Elemente, grün | https://www.reichelt.de/bargraph-anzeige-20-elemente-565-nm-gap-9-mcd-gruen-gbg-2000-p31506.html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 | https://cdn-reichelt.de/documents/datenblatt/A500/DS_DC2020GWA.pdf | 4.46 €
Bargraph-Anzeige | GBG 1000 | 10 Elemente, grün | https://www.reichelt.de/bargraph-anzeige-10-elemente-gruen-gbg-1000-p8141.html?&trstct=pol_5&nbc=1 | https://cdn-reichelt.de/documents/datenblatt/A500/GBG1000%23KIN.pdf | 2.10 €
Bargraph-Anzeige | SRBG 1000 | 10 Elemente, superrot | https://www.reichelt.de/bargraph-anzeige-gaalas-10-segmente-660-nm-superrot--srbg-1000-p31496.html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 | https://cdn-reichelt.de/documents/datenblatt/A500/RBG1000_RGBG1000_SRBG1000_YBG1000%23KIN.pdf | 2.00 €
Bargraph-Anzeige | RGBG 1000 | 10 Elemente, 3x rot, 7x grün | https://www.reichelt.de/bargraph-anzeige-10-elemente-3x-rot-7x-gruen-rgbg-1000-p31501.html?trstct=pol_7&nbc=1 | https://cdn-reichelt.de/documents/datenblatt/A500/GBG1000%23KIN.pdf | 1.95 €
Bargraph-Anzeige | RBG 1000 | 10 Elemente, rot | https://www.reichelt.de/bargraph-anzeige-10-elemente-rot-rbg-1000-p15156.html?&trstct=pol_9&nbc=1 | https://cdn-reichelt.de/documents/datenblatt/A500/RBG1000_RGBG1000_SRBG1000_YBG1000%23KIN.pdf | 2.26 €
Bargraph-Anzeige | SRBG 2000 | 20 Elemente, superrot | https://www.reichelt.de/bargraph-anzeige-20-elemente-superrot-srbg-2000-p31504.html?trstct=pol_10&nbc=1 | https://cdn-reichelt.de/documents/datenblatt/A500/RBG2000_SRBG2000_YBG2000%23KIN.pdf | 4.67 €
NAND-Gate | 74HC 00 | NAND-Gate, 2-Input, 4.5 ... 5.5 V, DIL-14 | https://www.reichelt.de/4-fach-2-eingangs-nand-gatter-2--6-v-dil-14-74hc-00-p3119.html?trstct=pos_0&nbc=1 | https://cdn-reichelt.de/documents/datenblatt/A200/DS_NXP_74HC00.pdf | 0.26 €
SRAM | AS 6C62256-55PCN | 32K x 8, 5V, 55 ns, DIL-28, A15 | https://www.reichelt.de/sram-32-kb-4-k-x-8-5-v-55ns-dil-28-as-6c62256-55pcn-p146551.html?trstct=pos_0&nbc=1 | https://cdn-reichelt.de/documents/datenblatt/A300/AS6C62256-ALE.pdf | 3.81 €
VGA-Plug | DELOCK 65170 | VGA Buchse > Terminalblock 16pin | https://www.reichelt.de/vga-buchse-terminalblock-16pin-delock-65170-p113236.html?&trstct=pos_0&nbc=1 | https://cdn-reichelt.de/documents/datenblatt/C120/DS_65170_GER.pdf | 7.55 €
EEPROM | 28C256-150 | 32K x 8, 5V, 150 ns, DIL-28, A15 | https://www.reichelt.de/eeprom-256-kb-32-k-x-8-5-v-150ns-pdip-28-28c256-150-p1945.html?trstct=pos_0&nbc=1 | https://cdn-reichelt.de/documents/datenblatt/A200/AT28C256.pdf | 12.90 €
SRAM | AS 6C1008-55PCN | 128K x 8, 5V, 55 ns, DIL-32, A17 | https://www.reichelt.de/sram-1-mb-128-k-x-8-5-v-55ns-dil-32-as-6c1008-55pcn-p146552.html?trstct=pos_0&nbc=1 | https://cdn-reichelt.de/documents/datenblatt/A300/AS6C1008-ALE.pdf | 4.00 €
NAND-Gate | 74HCT 00 | NAND-Gate, 2-Input, 4.5 ... 5.5 V, DIP-14 | https://www.reichelt.de/nand-gate-2-input-4-5--5-5-v-dil-14-74hct-00-p3303.html?&trstct=pos_0&nbc=1 | https://pdf1.alldatasheet.com/datasheet-pdf/view/1141085/SS/74HCT00.html | 0.33 €
AND-Gate | 74HCT 08 | AND-Gate, 2 Element, 4,5 ... 5,5 V, DIL-14 | https://www.reichelt.de/and-gate-2-element-4-5--5-5-v-dil-14-74hct-08-p3307.html?&trstct=pos_4&nbc=1 | https://cdn-reichelt.de/documents/datenblatt/A240/74HCT08%23STM.pdf | 0.36 €
AND-Gate | 74HC 08 | 74HC 08 AND-Gate, 2 Element, 2 ... 6 V, DIL-14 | https://www.reichelt.de/and-gate-2-element-2--6-v-dil-14-74hc-08-p3124.html?&trstct=pos_5&nbc=1 | https://pdf1.alldatasheet.com/datasheet-pdf/view/15524/PHILIPS/74HC08.html | 0.29 €
AND-Gate | LS 08 | AND-Gate, 2 Element, 4,75 ... 5,25 V, DIL-14 | https://www.reichelt.de/and-gate-2-element-4-75--5-25-v-dil-14-ls-08-p10592.html?&trstct=pos_7&nbc=1 | https://cdn-reichelt.de/documents/datenblatt/A200/LS08_TEX.pdf | 0.69 €
OR-Gate | 74HC 32 | OR-Gate, 2-Input, 2 ... 6 V, DIL-14 | https://www.reichelt.de/or-gate-2-input-2--6-v-dil-14-74hc-32-p3196.html?&trstct=pos_3&nbc=1 | https://pdf1.alldatasheet.com/datasheet-pdf/view/98369/PHILIPS/74HC32.html | 0.36 €
OR-Gate | LS 32 | OR-Gate, 2-Input, 4,75 ... 5,25 V, DIL-14 | https://www.reichelt.de/or-gate-2-input-4-75--5-25-v-dil-14-ls-32-p10698.html?&trstct=pos_4&nbc=1 | https://html.alldatasheet.com/html-pdf/28007/TI/74LS32/20/1/74LS32.html | 0.57 €
OR-Gate | 74AC 32 | Vierfache Positiv-ODER-Gatter, 2-Eingänge, 2 ... 6 V, DIP-14 | https://www.reichelt.de/vierfache-positiv-oder-gatter-2-eingaenge-2--6-v-dip-14-74ac-32-p58124.html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 | https://html.alldatasheet.com/html-pdf/12157/ONSEMI/74AC32/180/1/74AC32.html | 0.33 €
XOR-Gate | LS 136 | XOR-Gate, 2-Input, 4,75 ... 5,25 V, DIL-14 | https://www.reichelt.de/xor-gate-2-input-4-75--5-25-v-dil-14-ls-136-p10610.html?&trstct=pol_0&nbc=1 | https://www.reichelt.de/xor-gate-2-input-4-75--5-25-v-dil-14-ls-136-p10610.html?&trstct=pol_0&nbc=1 | 0.67 €
XOR-Gate | LS 86 | XOR-Gate, 2-Input, 4,75 ... 5,25 V, DIL-14 | https://www.reichelt.de/xor-gate-2-input-4-75--5-25-v-dil-14-ls-86-p10826.html?&trstct=pol_7&nbc=1 | https://cdn-reichelt.de/documents/datenblatt/A240/74LS86%23TEX.pdf | 0.69 €
XOR-Gate | 74HC 86 | Vierfache 2-Eingangs-Exklusiv-ODER-Gatter, 2 ... 6 V, DIL-14 | https://www.reichelt.de/vierfache-2-eingangs-exklusiv-oder-gatter-2--6-v-dil-14-74hc-86-p3300.html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 | https://cdn-reichelt.de/documents/datenblatt/A240/74HC86%23PHI.pdf | 0.48 €
XOR-Gate | CD 4070BE TEX | XOR-Gate, 2-Input, 3 ... 18 V, DIL-14 | https://www.reichelt.de/xor-gate-2-input-3--18-v-dil-14-cd-4070be-tex-p216655.html?trstct=pol_10&nbc=1 | https://pdf1.alldatasheet.com/datasheet-pdf/view/26888/TI/CD4070BE.html | 0.42 €
XOR-Gate | MOS 4070 | XOR-Gate, 2-Input, 3 ... 20 V, DIP-14 | https://www.reichelt.de/xor-gate-2-input-3--20-v-dip-14-mos-4070-p12623.html?&trstct=pol_11&nbc=1 | https://cdn-reichelt.de/documents/datenblatt/A200/MOS4070_STM.pdf | 0.38 €
Inverter | 74HC 368 | Inverter, 3-State, 2 ... 6 V, DIL-16 | https://www.reichelt.de/inverter-3-state-2--6-v-dil-16-74hc-368-p3205.html?&trstct=pol_19&nbc=1 | https://cdn-reichelt.de/documents/datenblatt/A200/SN74HC368_HCT368.pdf | 0.26 €
NOR-Gate | CD 4001UBE TEX | NOR-Gate, 2-Input, 3 ... 18 V, DIL-14 | https://www.reichelt.de/nor-gate-2-input-3--18-v-dil-14-cd-4001ube-tex-p216635.html?trstct=pol_24&nbc=1 | https://pdf1.alldatasheet.com/datasheet-pdf/view/50837/FAIRCHILD/CD4001.html | 0.50 €
Inverter | CD 4007UBE TEX | Inverter, Dual, 3 ... 18 V, DIL-14 | https://www.reichelt.de/inverter-dual-3--18-v-dil-14-cd-4007ube-tex-p216636.html?trstct=pol_25&nbc=1 | https://html.alldatasheet.com/html-pdf/834351/TI1/CD4007UBE/56/1/CD4007UBE.html | 0.43 €
Inverter | MOS 40106 | Inverter, Hex, 3 ... 15 V, DIP-14 | https://www.reichelt.de/inverter-hex-3--15-v-dip-14-mos-40106-p12547.html?&trstct=pol_27&nbc=1 | https://pdf1.alldatasheet.com/datasheet-pdf/view/66395/INTERSIL/CD40106.html | 0.38 €
Flash | AT25DF321A-SH | NOR-Flash-Speicher 32Mb, 2,7V, Seriell, 100MHz, SO-8 | https://www.reichelt.de/nor-flash-speicher-32mb-2-7v-seriell-100mhz-so-8-at25df321a-sh-p266431.html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 | https://cdn-reichelt.de/documents/datenblatt/A300/AT25DF321A-XX.pdf | 3.75 €
SMD zu DIP Adapter |  | KeeYees 12 Typen SMD zu DIP Adapter Platine PCB Prototype Kit SOP8 SOP10 SOP14 SOP16 SOP20 SOP24 SOP28 0402/0603/0805 SMT SOT89/SOT223 TQFP100 QFN32 QFN44/48 mit 40 Stück 2,54mm Stiftleiste | https://www.amazon.de/KeeYees-Adapter-Platine-Prototype-Stiftleiste/dp/B085LC6ZSY |  | 15.99 €
Header | MPE 094-1-016 | Buchsenleisten 2,54 mm, 1X16, gerade | https://www.reichelt.de/buchsenleisten-2-54-mm-1x16-gerade-mpe-094-1-016-p119919.html?trstct=pol_0&nbc=1 | https://cdn-reichelt.de/documents/datenblatt/C140/DS_MPE_094.pdf | 0.34 €
Header | SL 1X50G 2,54 | Stiftleiste, 2,54 mm, 1X50, gerade | https://www.reichelt.de/50pol-stiftleiste-gerade-rm-2-54-sl-1x50g-2-54-p19508.html?trstct=pol_0&nbc=1 | https://cdn-reichelt.de/documents/datenblatt/C140/SL1X50G254.pdf | 0.45 €
IC-Socket | GS 14 | IC-Sockel, 14-polig, doppelter Federkontakt | https://www.reichelt.de/ic-sockel-14-polig-doppelter-federkontakt-gs-14-p8206.html?trstct=pos_0&nbc=1 |  | 0.05 €
IC-Socket | GS 20 | IC-Sockel, 20-polig, doppelter Federkontakt | https://www.reichelt.de/ic-sockel-20-polig-doppelter-federkontakt-gs-20-p8212.html?search=GS20 |  | 0.06 €
Decoder | 74HC 137 | Decoder/MPX, 3 to 8, 2 ... 6 V, DIL-16, Inverted | https://www.reichelt.de/latch-3-to-8-2--6-v-dil-16-74hc-137-p3137.html?&trstct=pol_0&nbc=1 | https://cdn-reichelt.de/documents/datenblatt/A240/74HC137%23STM.pdf | 0.33 €
Decoder | 74HC 138 | Decoder/MPX, 3 to 8, 2 ... 6 V, DIL-16, Inverted | https://www.reichelt.de/decoder-mpx-3-to-8-2--6-v-dil-16-74hc-138-p3138.html?&trstct=pol_1&nbc=1 | https://pdf1.alldatasheet.com/datasheet-pdf/view/15535/PHILIPS/74HC138.html | 0.33 €
JK Flip-Flop | LS 109 | Flip-Flop JK-Type, Dual, 4,75 ... 5,25 V, DIL-16, posedge | https://www.reichelt.de/flip-flop-jk-type-dual-4-75--5-25-v-dil-16-ls-109-p10596.html?trstct=pol_2&nbc=1 | https://cdn-reichelt.de/documents/datenblatt/A240/LS109%23TEX.pdf | 0.22 €
JK Flip-Flop | LS 112 | Flip-Flop JK-Type, Dual, 4,75 ... 5,25 V, DIL-16, negedge | https://www.reichelt.de/flip-flop-jk-type-dual-4-75--5-25-v-dil-16-ls-112-p10598.html?trstct=pol_3&nbc=1 | https://www.reichelt.de/flip-flop-jk-type-dual-4-75--5-25-v-dil-16-ls-112-p10598.html?trstct=pol_3&nbc=1 | 0.71 €
JK Flip-Flop | LS 113 | Flip-Flop D-Type, LP-Schottky, 4,75 ... 5,25 V, DIL-14 | https://www.reichelt.de/flip-flop-d-type-lp-schottky-4-75--5-25-v-dil-14-ls-113-p10599.html?trstct=pol_4&nbc=1 | https://cdn-reichelt.de/documents/datenblatt/A200/LS113_MOT.pdf | 0.21 €
Transiver | SN74LS 245 | Transceiver, Octal, 4,75 ... 5,25 V, DIP-20 | https://www.reichelt.de/transceiver-octal-4-75--5-25-v-dip-20-ls-245-p10667.html?&trstct=pol_0&nbc=1 | https://pdf1.alldatasheet.com/datasheet-pdf/view/12640/ONSEMI/74LS245.html | 0.83 €
Inverted Transiver | 74HCT 640 | Inverter, 3-State, 4,5 ... 5,5 V, DIL-20 | https://www.reichelt.de/inverter-3-state-4-5--5-5-v-dil-20-74hct-640-p3427.html?&trstct=pol_1&nbc=1 | https://pdf1.alldatasheet.com/datasheet-pdf/view/15648/PHILIPS/74HCT640.html | 4.10 €
Inverted Transiver | 74HC 640 | Octal BUS Invited Transceiver, 3-State Ausgang, 2 ... 6 V, DIL-20 | https://www.reichelt.de/octal-bus-transceiver-3-state-ausgang-2--6-v-dil-20-74hc-640-p3272.html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 | https://pdf1.alldatasheet.com/datasheet-pdf/view/15647/PHILIPS/74HC640.html | 1.50 €
Inverted Transiver | LS 640 | Inverter, Octal, 4,75 ... 5,25 V, DIL-20 | https://www.reichelt.de/inverter-octal-4-75--5-25-v-dil-20-ls-640-p10793.html?&trstct=pol_3&nbc=1 | https://pdf1.alldatasheet.com/datasheet-pdf/view/88571/MOTOROLA/74LS640.html | 2.02 €
Transiver | LS 641 | Transceiver, Octal, 4,75 ... 5,25 V, DIL-20 | https://www.reichelt.de/transceiver-octal-4-75--5-25-v-dil-20-ls-641-p10794.html?&trstct=pol_4&nbc=1 | https://pdf1.alldatasheet.com/datasheet-pdf/view/88571/MOTOROLA/74LS640.html | 2.20 €
Transiver | LS 645 | Transceiver, Octal, 4,75 ... 5,25 V, DIL-20 | https://www.reichelt.de/transceiver-octal-4-75--5-25-v-dil-20-ls-645-p10798.html?&trstct=pol_5&nbc=1 | https://pdf1.alldatasheet.com/datasheet-pdf/view/88571/MOTOROLA/74LS640.html | 2.30 €
Transiver | SN74HCT245N TEX | Transceiver, Octal, 4,5 ... 5,5 V, PDIP-20 | https://www.reichelt.de/transceiver-octal-4-5--5-5-v-pdip-20-sn-74hct245n-tex-p219305.html?trstct=pol_6&nbc=1 | https://pdf1.alldatasheet.com/datasheet-pdf/view/663011/ONSEMI/74HCT245.html | 0.70 €
DAC | AD5432YRM-REEL7 | 10 Bit Digital to Analog Converter 1 10-MSOP | https://www.digikey.de/en/products/detail/analog-devices-inc/AD5432YRM-REEL7/653922 | https://www.analog.com/media/en/technical-documentation/data-sheets/AD5426_5432_5443.pdf | 3.36 €
PCB-Base Material | Bungard 120106E33 | Basismaterial einseitig 35 µm Fotobeschichtung positiv (L x B) 160 mm x 100 mm 1 St. | https://www.conrad.de/de/p/bungard-120106e33-basismaterial-einseitig-35-m-fotobeschichtung-positiv-l-x-b-160-mm-x-100-mm-1-st-523630.html | https://asset.conrad.com/media10/add/160267/c1/-/de/000529222DS01/datenblatt-529222-bungard-120306e53-basismaterial-einseitig-35-m-fotobeschichtung-positiv-l-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 | 4.00 €

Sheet: Shoping List
Part | Description | Price per Part | Amount | Price | Sum
R 220 |  | 0.01 € | 1000 | 5.00 € | 49.00 €
R 10k |  | 0.01 € | 1000 | 5.00 €
R 1k |  | 0.01 € | 1000 | 5.00 €
74HC541 | Buffer | 0.85 € | 40 | 34.00 €
74HC157 | Muliplexer |  |  | 0.00 €
 |  |  |  | 0.00 €
 |  |  |  | 0.00 €
 |  |  |  | 0.00 €
 |  |  |  | 0.00 €
 |  |  |  | 0.00 €
 |  |  |  | 0.00 €
 |  |  |  | 0.00 €
 |  |  |  | 0.00 €
 |  |  |  | 0.00 €
 |  |  |  | 0.00 €
 |  |  |  | 0.00 €
 |  |  |  | 0.00 €
 |  |  |  | 0.00 €
 |  |  |  | 0.00 €
 |  |  |  | 0.00 €
 |  |  |  | 0.00 €
 |  |  |  | 0.00 €
 |  |  |  | 0.00 €
 |  |  |  | 0.00 €
 |  |  |  | 0.00 €
 |  |  |  | 0.00 €
 |  |  |  | 0.00 €
 |  |  |  | 0.00 €
 |  |  |  | 0.00 €
 |  |  |  | 0.00 €
 |  |  |  | 0.00 €
 |  |  |  | 0.00 €
 |  |  |  | 0.00 €
 |  |  |  | 0.00 €
 |  |  |  | 0.00 €
 |  |  |  | 0.00 €
 |  |  |  | 0.00 €
 |  |  |  | 0.00 €
 |  |  |  | 0.00 €
 |  |  |  | 0.00 €
 |  |  |  | 0.00 €
 |  |  |  | 0.00 €
 |  |  |  | 0.00 €
 |  |  |  | 0.00 €
 |  |  |  | 0.00 €
 |  |  |  | 0.00 €
 |  |  |  | 0.00 €
 |  |  |  | 0.00 €
 |  |  |  | 0.00 €
 |  |  |  | 0.00 €
 |  |  |  | 0.00 €
 |  |  |  | 0.00 €
 |  |  |  | 0.00 €
 |  |  |  | 0.00 €
 |  |  |  | 0.00 €
 |  |  |  | 0.00 €
 |  |  |  | 0.00 €
 |  |  |  | 0.00 €
 |  |  |  | 0.00 €
 |  |  |  | 0.00 €
 |  |  |  | 0.00 €
 |  |  |  | 0.00 €
 |  |  |  | 0.00 €
 |  |  |  | 0.00 €
 |  |  |  | 0.00 €
 |  |  |  | 0.00 €
 |  |  |  | 0.00 €
 |  |  |  | 0.00 €
 |  |  |  | 0.00 €
 |  |  |  | 0.00 €
 |  |  |  | 0.00 €
 |  |  |  | 0.00 €
 |  |  |  | 0.00 €
 |  |  |  | 0.00 €
 |  |  |  | 0.00 €
 |  |  |  | 0.00 €
 |  |  |  | 0.00 €
 |  |  |  | 0.00 €
 |  |  |  | 0.00 €
 |  |  |  | 0.00 €
 |  |  |  | 0.00 €
 |  |  |  | 0.00 €
 |  |  |  | 0.00 €
 |  |  |  | 0.00 €
 |  |  |  | 0.00 €
 |  |  |  | 0.00 €
 |  |  |  | 0.00 €
 |  |  |  | 0.00 €

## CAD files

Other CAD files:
circets/Desighn_Overview.blend

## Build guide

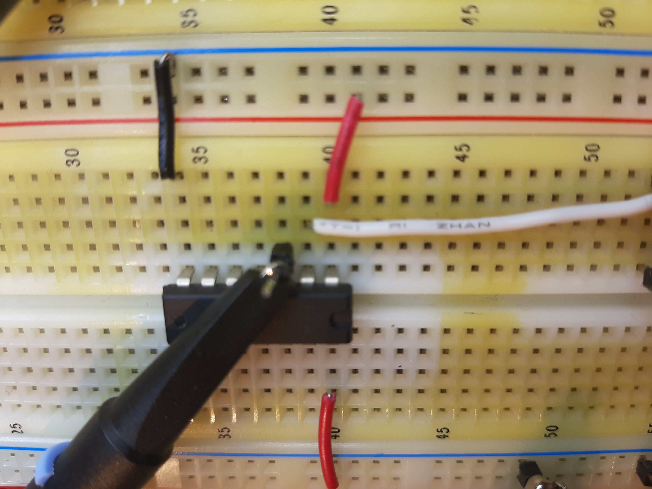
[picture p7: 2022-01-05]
images/PropDelay_Setup_05.jpg

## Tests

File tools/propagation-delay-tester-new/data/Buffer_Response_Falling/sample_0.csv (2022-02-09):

time channel1 channel2 channel3
-3.4e-08 4.800000000000001 4.800000000000001 4.800000000000001
-3.39e-08 4.800000000000001 4.800000000000001 4.800000000000001
-3.38e-08 4.6000000000000005 4.800000000000001 5.0
-3.37e-08 4.6000000000000005 4.800000000000001 5.0
-3.36e-08 4.6000000000000005 4.6000000000000005 4.800000000000001
-3.35e-08 4.6000000000000005 4.6000000000000005 4.800000000000001
-3.34e-08 4.6000000000000005 4.6000000000000005 4.800000000000001
-3.33e-08 4.6000000000000005 4.6000000000000005 4.800000000000001
-3.32e-08 4.6000000000000005 4.800000000000001 5.0
-3.31e-08 4.6000000000000005 4.800000000000001 5.0
-3.3e-08 4.6000000000000005 4.800000000000001 5.0
-3.29e-08 4.6000000000000005 4.800000000000001 5.0
-3.28e-08 4.6000000000000005 4.800000000000001 5.0
-3.27e-08 4.6000000000000005 4.800000000000001 5.0
-3.26e-08 4.800000000000001 4.800000000000001 5.0
-3.25e-08 4.800000000000001 4.800000000000001 5.0
-3.24e-08 4.6000000000000005 4.6000000000000005 5.0
-3.23e-08 4.6000000000000005 4.6000000000000005 5.0
-3.22e-08 4.6000000000000005 4.800000000000001 4.800000000000001
-3.21e-08 4.6000000000000005 4.800000000000001 4.800000000000001
-3.2e-08 4.800000000000001 4.800000000000001 4.800000000000001
-3.19e-08 4.800000000000001 4.800000000000001 4.800000000000001
-3.18e-08 4.6000000000000005 4.800000000000001 4.800000000000001
-3.17e-08 4.6000000000000005 4.800000000000001 4.800000000000001
-3.16e-08 4.6000000000000005 4.800000000000001 5.0
-3.15e-08 4.6000000000000005 4.800000000000001 5.0
-3.14e-08 4.6000000000000005 4.800000000000001 4.800000000000001
-3.13e-08 4.6000000000000005 4.800000000000001 4.800000000000001
-3.12e-08 4.800000000000001 4.800000000000001 4.800000000000001
-3.11e-08 4.800000000000001 4.800000000000001 4.800000000000001
-3.1e-08 4.6000000000000005 4.800000000000001 5.0
-3.09e-08 4.6000000000000005 4.800000000000001 5.0
-3.08e-08 4.6000000000000005 4.800000000000001 4.800000000000001
-3.07e-08 4.6000000000000005 4.800000000000001 4.800000000000001
-3.06e-08 4.6000000000000005 4.800000000000001 5.0
-3.05e-08 4.6000000000000005 4.800000000000001 5.0
-3.04e-08 4.6000000000000005 4.800000000000001 4.800000000000001
-3.03e-08 4.6000000000000005 4.800000000000001 4.800000000000001
-3.02e-08 4.6000000000000005 4.800000000000001 5.0
-3.01e-08 4.6000000000000005 4.800000000000001 5.0
-3e-08 4.800000000000001 4.6000000000000005 4.800000000000001
-2.9899999999999996e-08 4.800000000000001 4.6000000000000005 4.800000000000001
-2.98e-08 4.800000000000001 4.6000000000000005 4.800000000000001
-2.97e-08 4.800000000000001 4.6000000000000005 4.800000000000001
-2.96e-08 4.800000000000001 4.6000000000000005 4.800000000000001
-2.95e-08 4.800000000000001 4.6000000000000005 4.800000000000001
-2.94e-08 4.6000000000000005 4.800000000000001 4.800000000000001
-2.93e-08 4.6000000000000005 4.800000000000001 4.800000000000001
-2.92e-08 4.800000000000001 4.6000000000000005 5.0
-2.91e-08 4.800000000000001 4.6000000000000005 5.0
-2.9e-08 4.6000000000000005 4.6000000000000005 5.0
-2.89e-08 4.6000000000000005 4.6000000000000005 5.0
-2.88e-08 4.6000000000000005 4.6000000000000005 5.0
-2.87e-08 4.6000000000000005 4.6000000000000005 5.0
-2.8599999999999998e-08 4.800000000000001 4.800000000000001 5.0
-2.85e-08 4.800000000000001 4.800000000000001 5.0
-2.84e-08 4.800000000000001 4.800000000000001 5.0
-2.83e-08 4.800000000000001 4.800000000000001 5.0
-2.82e-08 4.800000000000001 4.800000000000001 5.0
-2.81e-08 4.800000000000001 4.800000000000001 5.0
-2.8e-08 4.800000000000001 4.800000000000001 5.0
-2.79e-08 4.800000000000001 4.800000000000001 5.0
-2.78e-08 4.800000000000001 4.800000000000001 5.0
-2.77e-08 4.800000000000001 4.800000000000001 5.0
-2.76e-08 4.6000000000000005 4.6000000000000005 5.0
-2.75e-08 4.6000000000000005 4.6000000000000005 5.0
-2.74e-08 4.6000000000000005 4.800000000000001 5.0
-2.73e-08 4.6000000000000005 4.800000000000001 5.0
-2.72e-08 4.6000000000000005 4.800000000000001 5.0
-2.7099999999999998e-08 4.6000000000000005 4.800000000000001 5.0
-2.7e-08 4.800000000000001 4.800000000000001 5.0
-2.69e-08 4.800000000000001 4.800000000000001 5.0
-2.6800000000000002e-08 4.6000000000000005 4.800000000000001 5.0
-2.67e-08 4.6000000000000005 4.800000000000001 5.0
-2.66e-08 4.6000000000000005 4.6000000000000005 5.0
-2.65e-08 4.6000000000000005 4.6000000000000005 5.0
-2.6399999999999998e-08 4.800000000000001 4.800000000000001 5.0
-2.63e-08 4.800000000000001 4.800000000000001 5.0
-2.62e-08 4.6000000000000005 4.800000000000001 5.0
-2.6100000000000002e-08 4.6000000000000005 4.800000000000001 5.0
-2.6e-08 4.800000000000001 4.6000000000000005 5.0
-2.59e-08 4.800000000000001 4.6000000000000005 5.0
-2.58e-08 4.6000000000000005 4.800000000000001 5.0
-2.57e-08 4.6000000000000005 4.800000000000001 5.0
-2.5599999999999998e-08 4.800000000000001 4.800000000000001 5.0
-2.55e-08 4.800000000000001 4.800000000000001 5.0
-2.54e-08 4.800000000000001 4.800000000000001 5.0
-2.53e-08 4.800000000000001 4.800000000000001 5.0
-2.52e-08 4.6000000000000005 4.800000000000001 5.0
-2.51e-08 4.6000000000000005 4.800000000000001 5.0
-2.5e-08 4.6000000000000005 4.800000000000001 5.0
-2.4899999999999998e-08 4.6000000000000005 4.800000000000001 5.0
-2.48e-08 4.6000000000000005 4.6000000000000005 4.800000000000001
-2.47e-08 4.6000000000000005 4.6000000000000005 4.800000000000001
-2.4600000000000002e-08 4.800000000000001 4.6000000000000005 4.800000000000001
-2.45e-08 4.800000000000001 4.6000000000000005 4.800000000000001
-2.44e-08 4.800000000000001 4.6000000000000005 4.800000000000001
-2.43e-08 4.800000000000001 4.6000000000000005 4.800000000000001
-2.4199999999999998e-08 4.800000000000001 4.800000000000001 4.800000000000001
-2.4099999999999997e-08 4.800000000000001 4.800000000000001 4.800000000000001
-2.4e-08 4.800000000000001 4.800000000000001 4.800000000000001
-2.39e-08 4.800000000000001 4.800000000000001 4.800000000000001
-2.38e-08 4.800000000000001 4.800000000000001 4.800000000000001
-2.37e-08 4.800000000000001 4.800000000000001 4.800000000000001
-2.36e-08 4.800000000000001 4.800000000000001 4.800000000000001
-2.35e-08 4.800000000000001 4.800000000000001 4.800000000000001
-2.3399999999999998e-08 4.800000000000001 4.800000000000001 5.0
-2.33e-08 4.800000000000001 4.800000000000001 5.0
-2.32e-08 4.800000000000001 4.800000000000001 5.0
-2.3100000000000002e-08 4.800000000000001 4.800000000000001 5.0
-2.3e-08 4.800000000000001 4.800000000000001 5.0
-2.29e-08 4.800000000000001 4.800000000000001 5.0
-2.28e-08 4.800000000000001 4.800000000000001 4.800000000000001
-2.2699999999999998e-08 4.800000000000001 4.800000000000001 4.800000000000001
-2.2599999999999997e-08 4.800000000000001 4.800000000000001 4.800000000000001
-2.25e-08 4.800000000000001 4.800000000000001 4.800000000000001
-2.2400000000000002e-08 4.800000000000001 4.800000000000001 4.800000000000001
-2.23e-08 4.800000000000001 4.800000000000001 4.800000000000001
-2.22e-08 4.800000000000001 4.6000000000000005 4.800000000000001
-2.21e-08 4.800000000000001 4.6000000000000005 4.800000000000001
-2.2e-08 4.800000000000001 4.6000000000000005 5.0
-2.1899999999999998e-08 4.800000000000001 4.6000000000000005 5.0
-2.18e-08 4.800000000000001 4.800000000000001 5.0
-2.17e-08 4.800000000000001 4.800000000000001 5.0
-2.16e-08 4.800000000000001 4.800000000000001 5.0
-2.15e-08 4.800000000000001 4.800000000000001 5.0
-2.14e-08 4.800000000000001 4.800000000000001 5.0
-2.13e-08 4.800000000000001 4.800000000000001 5.0
-2.1199999999999998e-08 4.800000000000001 4.6000000000000005 5.0
-2.11e-08 4.800000000000001 4.6000000000000005 5.0
-2.1e-08 4.800000000000001 4.6000000000000005 5.0
-2.0900000000000002e-08 4.800000000000001 4.6000000000000005 5.0
-2.08e-08 4.800000000000001 4.800000000000001 4.800000000000001
-2.07e-08 4.800000000000001 4.800000000000001 4.800000000000001
-2.06e-08 4.800000000000001 4.800000000000001 5.0
-2.0499999999999998e-08 4.800000000000001 4.800000000000001 5.0
-2.0399999999999997e-08 4.800000000000001 4.800000000000001 5.0
-2.03e-08 4.800000000000001 4.800000000000001 5.0
-2.02e-08 4.6000000000000005 4.800000000000001 5.0
-2.01e-08 4.6000000000000005 4.800000000000001 5.0
-2e-08 4.6000000000000005 4.800000000000001 4.800000000000001
-1.99e-08 4.6000000000000005 4.800000000000001 4.800000000000001
-1.98e-08 4.6000000000000005 4.800000000000001 4.800000000000001
-1.9699999999999998e-08 4.6000000000000005 4.800000000000001 4.800000000000001
-1.96e-08 4.6000000000000005 4.800000000000001 4.800000000000001
-1.95e-08 4.6000000000000005 4.800000000000001 4.800000000000001
-1.9400000000000002e-08 4.6000000000000005 4.800000000000001 5.0
-1.93e-08 4.6000000000000005 4.800000000000001 5.0
-1.92e-08 4.6000000000000005 4.800000000000001 4.800000000000001
-1.91e-08 4.6000000000000005 4.800000000000001 4.800000000000001
-1.8999999999999998e-08 4.6000000000000005 4.800000000000001 5.0
-1.89e-08 4.6000000000000005 4.800000000000001 5.0
-1.88e-08 4.800000000000001 4.800000000000001 4.800000000000001
-1.87e-08 4.800000000000001 4.800000000000001 4.800000000000001
-1.86e-08 4.800000000000001 4.800000000000001 5.0
-1.85e-08 4.800000000000001 4.800000000000001 5.0
-1.84e-08 4.800000000000001 4.800000000000001 5.0
-1.83e-08 4.800000000000001 4.800000000000001 5.0
-1.82e-08 4.6000000000000005 4.6000000000000005 5.0
-1.81e-08 4.6000000000000005 4.6000000000000005 5.0
-1.8e-08 4.6000000000000005 4.800000000000001 5.0
-1.7899999999999998e-08 4.6000000000000005 4.800000000000001 5.0
-1.78e-08 4.6000000000000005 4.800000000000001 5.0
-1.77e-08 4.6000000000000005 4.800000000000001 5.0
-1.76e-08 4.6000000000000005 4.6000000000000005 5.0
-1.7499999999999998e-08 4.6000000000000005 4.6000000000000005 5.0
-1.74e-08 4.800000000000001 4.800000000000001 5.0
-1.73e-08 4.800000000000001 4.800000000000001 5.0
-1.72e-08 4.800000000000001 4.6000000000000005 5.0
-1.71e-08 4.800000000000001 4.6000000000000005 5.0
-1.7e-08 4.800000000000001 4.800000000000001 5.0
-1.69e-08 4.800000000000001 4.800000000000001 5.0
-1.6799999999999998e-08 4.800000000000001 4.800000000000001 4.800000000000001
-1.67e-08 4.800000000000001 4.800000000000001 4.800000000000001
-1.66e-08 4.800000000000001 4.6000000000000005 4.800000000000001
-1.65e-08 4.800000000000001 4.6000000000000005 4.800000000000001
-1.6399999999999998e-08 4.800000000000001 4.6000000000000005 5.0
-1.63e-08 4.800000000000001 4.6000000000000005 5.0
-1.62e-08 4.6000000000000005 4.6000000000000005 5.0
-1.61e-08 4.6000000000000005 4.6000000000000005 5.0
-1.6e-08 4.800000000000001 4.6000000000000005 5.0
-1.59e-08 4.800000000000001 4.6000000000000005 5.0
-1.58e-08 4.800000000000001 4.6000000000000005 5.0
-1.5699999999999998e-08 4.800000000000001 4.6000000000000005 5.0
-1.56e-08 4.800000000000001 4.800000000000001 5.0
-1.55e-08 4.800000000000001 4.800000000000001 5.0
-1.54e-08 4.6000000000000005 4.800000000000001 5.0
-1.5299999999999998e-08 4.6000000000000005 4.800000000000001 5.0
-1.52e-08 4.6000000000000005 4.800000000000001 5.0
-1.51e-08 4.6000000000000005 4.800000000000001 5.0
-1.5e-08 4.6000000000000005 4.800000000000001 5.0
-1.4899999999999998e-08 4.6000000000000005 4.800000000000001 5.0
-1.48e-08 4.800000000000001 4.800000000000001 5.0
-1.47e-08 4.800000000000001 4.800000000000001 5.0
-1.4599999999999998e-08 4.6000000000000005 4.6000000000000005 5.0
-1.45e-08 4.6000000000000005 4.6000000000000005 5.0
-1.44e-08 4.800000000000001 4.6000000000000005 4.800000000000001
-1.4299999999999999e-08 4.800000000000001 4.6000000000000005 4.800000000000001
-1.4199999999999998e-08 4.6000000000000005 4.800000000000001 4.800000000000001
-1.41e-08 4.6000000000000005 4.800000000000001 4.800000000000001
-1.4e-08 4.800000000000001 4.800000000000001 5.0
-1.3899999999999999e-08 4.800000000000001 4.800000000000001 5.0
-1.3799999999999998e-08 4.800000000000001 4.800000000000001 4.800000000000001
-1.37e-08 4.800000000000001 4.800000000000001 4.800000000000001
-1.36e-08 4.800000000000001 4.6000000000000005 4.800000000000001
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

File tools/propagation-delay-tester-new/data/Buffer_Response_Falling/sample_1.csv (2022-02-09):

time channel1 channel2 channel3
-3.4e-08 4.800000000000001 4.800000000000001 4.800000000000001
-3.39e-08 4.800000000000001 4.800000000000001 4.800000000000001
-3.38e-08 4.6000000000000005 4.800000000000001 5.0
-3.37e-08 4.6000000000000005 4.800000000000001 5.0
-3.36e-08 4.6000000000000005 4.800000000000001 5.0
-3.35e-08 4.6000000000000005 4.800000000000001 5.0
-3.34e-08 4.6000000000000005 4.800000000000001 5.0
-3.33e-08 4.6000000000000005 4.800000000000001 5.0
-3.32e-08 4.6000000000000005 4.6000000000000005 4.800000000000001
-3.31e-08 4.6000000000000005 4.6000000000000005 4.800000000000001
-3.3e-08 4.6000000000000005 4.800000000000001 4.800000000000001
-3.29e-08 4.6000000000000005 4.800000000000001 4.800000000000001
-3.28e-08 4.6000000000000005 4.800000000000001 4.800000000000001
-3.27e-08 4.6000000000000005 4.800000000000001 4.800000000000001
-3.26e-08 4.800000000000001 4.6000000000000005 5.0
-3.25e-08 4.800000000000001 4.6000000000000005 5.0
-3.24e-08 4.6000000000000005 4.800000000000001 4.800000000000001
-3.23e-08 4.6000000000000005 4.800000000000001 4.800000000000001
-3.22e-08 4.6000000000000005 4.800000000000001 5.0
-3.21e-08 4.6000000000000005 4.800000000000001 5.0
-3.2e-08 4.800000000000001 4.800000000000001 4.800000000000001
-3.19e-08 4.800000000000001 4.800000000000001 4.800000000000001
-3.18e-08 4.6000000000000005 4.800000000000001 5.0
-3.17e-08 4.6000000000000005 4.800000000000001 5.0
-3.16e-08 4.6000000000000005 4.800000000000001 5.0
-3.15e-08 4.6000000000000005 4.800000000000001 5.0
-3.14e-08 4.6000000000000005 4.6000000000000005 5.0
-3.13e-08 4.6000000000000005 4.6000000000000005 5.0
-3.12e-08 4.800000000000001 4.6000000000000005 5.0
-3.11e-08 4.800000000000001 4.6000000000000005 5.0
-3.1e-08 4.6000000000000005 4.6000000000000005 5.0
-3.09e-08 4.6000000000000005 4.6000000000000005 5.0
-3.08e-08 4.6000000000000005 4.800000000000001 5.0
-3.07e-08 4.6000000000000005 4.800000000000001 5.0
-3.06e-08 4.6000000000000005 4.800000000000001 5.0
-3.05e-08 4.6000000000000005 4.800000000000001 5.0
-3.04e-08 4.6000000000000005 4.800000000000001 5.0
-3.03e-08 4.6000000000000005 4.800000000000001 5.0
-3.02e-08 4.6000000000000005 4.800000000000001 5.0
-3.01e-08 4.6000000000000005 4.800000000000001 5.0
-3e-08 4.800000000000001 4.800000000000001 4.800000000000001
-2.9899999999999996e-08 4.800000000000001 4.800000000000001 4.800000000000001
-2.98e-08 4.800000000000001 4.800000000000001 4.800000000000001
-2.97e-08 4.800000000000001 4.800000000000001 4.800000000000001
-2.96e-08 4.800000000000001 4.800000000000001 5.0
-2.95e-08 4.800000000000001 4.800000000000001 5.0
-2.94e-08 4.6000000000000005 4.800000000000001 5.0
-2.93e-08 4.6000000000000005 4.800000000000001 5.0
-2.92e-08 4.800000000000001 4.800000000000001 5.0
-2.91e-08 4.800000000000001 4.800000000000001 5.0
-2.9e-08 4.6000000000000005 4.800000000000001 5.0
-2.89e-08 4.6000000000000005 4.800000000000001 5.0
-2.88e-08 4.6000000000000005 4.6000000000000005 5.0
-2.87e-08 4.6000000000000005 4.6000000000000005 5.0
-2.8599999999999998e-08 4.800000000000001 4.6000000000000005 5.0
-2.85e-08 4.800000000000001 4.6000000000000005 5.0
-2.84e-08 4.800000000000001 4.800000000000001 5.0
-2.83e-08 4.800000000000001 4.800000000000001 5.0
-2.82e-08 4.800000000000001 4.800000000000001 5.0
-2.81e-08 4.800000000000001 4.800000000000001 5.0
-2.8e-08 4.800000000000001 4.800000000000001 5.0
-2.79e-08 4.800000000000001 4.800000000000001 5.0
-2.78e-08 4.800000000000001 4.6000000000000005 5.0
-2.77e-08 4.800000000000001 4.6000000000000005 5.0
-2.76e-08 4.6000000000000005 4.6000000000000005 4.800000000000001
-2.75e-08 4.6000000000000005 4.6000000000000005 4.800000000000001
-2.74e-08 4.6000000000000005 4.800000000000001 4.800000000000001
-2.73e-08 4.6000000000000005 4.800000000000001 4.800000000000001
-2.72e-08 4.6000000000000005 4.800000000000001 5.0
-2.7099999999999998e-08 4.6000000000000005 4.800000000000001 5.0
-2.7e-08 4.800000000000001 4.800000000000001 4.800000000000001
-2.69e-08 4.800000000000001 4.800000000000001 4.800000000000001
-2.6800000000000002e-08 4.6000000000000005 4.800000000000001 4.800000000000001
-2.67e-08 4.6000000000000005 4.800000000000001 4.800000000000001
-2.66e-08 4.6000000000000005 4.800000000000001 4.800000000000001
-2.65e-08 4.6000000000000005 4.800000000000001 4.800000000000001
-2.6399999999999998e-08 4.800000000000001 4.800000000000001 5.0
-2.63e-08 4.800000000000001 4.800000000000001 5.0
-2.62e-08 4.6000000000000005 4.800000000000001 5.0
-2.6100000000000002e-08 4.6000000000000005 4.800000000000001 5.0
-2.6e-08 4.800000000000001 4.800000000000001 5.0
-2.59e-08 4.800000000000001 4.800000000000001 5.0
-2.58e-08 4.6000000000000005 4.800000000000001 5.0
-2.57e-08 4.6000000000000005 4.800000000000001 5.0
-2.5599999999999998e-08 4.800000000000001 4.800000000000001 5.0
-2.55e-08 4.800000000000001 4.800000000000001 5.0
-2.54e-08 4.800000000000001 4.800000000000001 4.800000000000001
-2.53e-08 4.800000000000001 4.800000000000001 4.800000000000001
-2.52e-08 4.6000000000000005 4.800000000000001 5.0
-2.51e-08 4.6000000000000005 4.800000000000001 5.0
-2.5e-08 4.6000000000000005 4.800000000000001 5.0
-2.4899999999999998e-08 4.6000000000000005 4.800000000000001 5.0
-2.48e-08 4.6000000000000005 4.6000000000000005 5.0
-2.47e-08 4.6000000000000005 4.6000000000000005 5.0
-2.4600000000000002e-08 4.800000000000001 4.800000000000001 5.0
-2.45e-08 4.800000000000001 4.800000000000001 5.0
-2.44e-08 4.800000000000001 4.800000000000001 5.0
-2.43e-08 4.800000000000001 4.800000000000001 5.0
-2.4199999999999998e-08 4.800000000000001 4.6000000000000005 5.0
-2.4099999999999997e-08 4.800000000000001 4.6000000000000005 5.0
-2.4e-08 4.800000000000001 4.800000000000001 5.0
-2.39e-08 4.800000000000001 4.800000000000001 5.0
-2.38e-08 4.800000000000001 4.6000000000000005 5.0
-2.37e-08 4.800000000000001 4.6000000000000005 5.0
-2.36e-08 4.800000000000001 4.800000000000001 5.0
-2.35e-08 4.800000000000001 4.800000000000001 5.0
-2.3399999999999998e-08 4.800000000000001 4.800000000000001 5.0
-2.33e-08 4.800000000000001 4.800000000000001 5.0
-2.32e-08 4.800000000000001 4.6000000000000005 5.0
-2.3100000000000002e-08 4.800000000000001 4.6000000000000005 5.0
-2.3e-08 4.800000000000001 4.6000000000000005 5.0
-2.29e-08 4.800000000000001 4.6000000000000005 5.0
-2.28e-08 4.800000000000001 4.6000000000000005 5.0
-2.2699999999999998e-08 4.800000000000001 4.6000000000000005 5.0
-2.2599999999999997e-08 4.800000000000001 4.6000000000000005 4.800000000000001
-2.25e-08 4.800000000000001 4.6000000000000005 4.800000000000001
-2.2400000000000002e-08 4.800000000000001 4.6000000000000005 4.800000000000001
-2.23e-08 4.800000000000001 4.6000000000000005 4.800000000000001
-2.22e-08 4.800000000000001 4.800000000000001 4.800000000000001
-2.21e-08 4.800000000000001 4.800000000000001 4.800000000000001
-2.2e-08 4.800000000000001 4.800000000000001 4.800000000000001
-2.1899999999999998e-08 4.800000000000001 4.800000000000001 4.800000000000001
-2.18e-08 4.800000000000001 4.800000000000001 4.800000000000001
-2.17e-08 4.800000000000001 4.800000000000001 4.800000000000001
-2.16e-08 4.800000000000001 4.800000000000001 4.800000000000001
-2.15e-08 4.800000000000001 4.800000000000001 4.800000000000001
-2.14e-08 4.800000000000001 4.800000000000001 5.0
-2.13e-08 4.800000000000001 4.800000000000001 5.0
-2.1199999999999998e-08 4.800000000000001 4.6000000000000005 4.800000000000001
-2.11e-08 4.800000000000001 4.6000000000000005 4.800000000000001
-2.1e-08 4.800000000000001 4.6000000000000005 5.0
-2.0900000000000002e-08 4.800000000000001 4.6000000000000005 5.0
-2.08e-08 4.800000000000001 4.800000000000001 4.800000000000001
-2.07e-08 4.800000000000001 4.800000000000001 4.800000000000001
-2.06e-08 4.800000000000001 4.800000000000001 4.800000000000001
-2.0499999999999998e-08 4.800000000000001 4.800000000000001 4.800000000000001
-2.0399999999999997e-08 4.800000000000001 4.800000000000001 4.800000000000001
-2.03e-08 4.800000000000001 4.800000000000001 4.800000000000001
-2.02e-08 4.6000000000000005 4.6000000000000005 4.800000000000001
-2.01e-08 4.6000000000000005 4.6000000000000005 4.800000000000001
-2e-08 4.6000000000000005 4.800000000000001 5.0
-1.99e-08 4.6000000000000005 4.800000000000001 5.0
-1.98e-08 4.6000000000000005 4.800000000000001 4.800000000000001
-1.9699999999999998e-08 4.6000000000000005 4.800000000000001 4.800000000000001
-1.96e-08 4.6000000000000005 4.800000000000001 5.0
-1.95e-08 4.6000000000000005 4.800000000000001 5.0
-1.9400000000000002e-08 4.6000000000000005 4.800000000000001 5.0
-1.93e-08 4.6000000000000005 4.800000000000001 5.0
-1.92e-08 4.6000000000000005 4.800000000000001 5.0
-1.91e-08 4.6000000000000005 4.800000000000001 5.0
-1.8999999999999998e-08 4.6000000000000005 4.800000000000001 5.0
-1.89e-08 4.6000000000000005 4.800000000000001 5.0
-1.88e-08 4.800000000000001 4.800000000000001 5.0
-1.87e-08 4.800000000000001 4.800000000000001 5.0
-1.86e-08 4.800000000000001 4.800000000000001 5.0
-1.85e-08 4.800000000000001 4.800000000000001 5.0
-1.84e-08 4.800000000000001 4.6000000000000005 5.0
-1.83e-08 4.800000000000001 4.6000000000000005 5.0
-1.82e-08 4.6000000000000005 4.800000000000001 5.0
-1.81e-08 4.6000000000000005 4.800000000000001 5.0
-1.8e-08 4.6000000000000005 4.800000000000001 5.0
-1.7899999999999998e-08 4.6000000000000005 4.800000000000001 5.0
-1.78e-08 4.6000000000000005 4.800000000000001 4.800000000000001
-1.77e-08 4.6000000000000005 4.800000000000001 4.800000000000001
-1.76e-08 4.6000000000000005 4.800000000000001 4.800000000000001
-1.7499999999999998e-08 4.6000000000000005 4.800000000000001 4.800000000000001
-1.74e-08 4.800000000000001 4.800000000000001 5.0
-1.73e-08 4.800000000000001 4.800000000000001 5.0
-1.72e-08 4.800000000000001 4.800000000000001 5.0
-1.71e-08 4.800000000000001 4.800000000000001 5.0
-1.7e-08 4.800000000000001 4.800000000000001 5.0
-1.69e-08 4.800000000000001 4.800000000000001 5.0
-1.6799999999999998e-08 4.800000000000001 4.6000000000000005 5.0
-1.67e-08 4.800000000000001 4.6000000000000005 5.0
-1.66e-08 4.800000000000001 4.6000000000000005 5.0
-1.65e-08 4.800000000000001 4.6000000000000005 5.0
-1.6399999999999998e-08 4.800000000000001 4.800000000000001 5.0
-1.63e-08 4.800000000000001 4.800000000000001 5.0
-1.62e-08 4.6000000000000005 4.6000000000000005 5.0
-1.61e-08 4.6000000000000005 4.6000000000000005 5.0
-1.6e-08 4.800000000000001 4.6000000000000005 5.0
-1.59e-08 4.800000000000001 4.6000000000000005 5.0
-1.58e-08 4.800000000000001 4.6000000000000005 5.0
-1.5699999999999998e-08 4.800000000000001 4.6000000000000005 5.0
-1.56e-08 4.800000000000001 4.800000000000001 5.0
-1.55e-08 4.800000000000001 4.800000000000001 5.0
-1.54e-08 4.6000000000000005 4.6000000000000005 5.0
-1.5299999999999998e-08 4.6000000000000005 4.6000000000000005 5.0
-1.52e-08 4.6000000000000005 4.800000000000001 4.800000000000001
-1.51e-08 4.6000000000000005 4.800000000000001 4.800000000000001
-1.5e-08 4.6000000000000005 4.800000000000001 5.0
-1.4899999999999998e-08 4.6000000000000005 4.800000000000001 5.0
-1.48e-08 4.800000000000001 4.800000000000001 4.800000000000001
-1.47e-08 4.800000000000001 4.800000000000001 4.800000000000001
-1.4599999999999998e-08 4.6000000000000005 4.6000000000000005 4.800000000000001
-1.45e-08 4.6000000000000005 4.6000000000000005 4.800000000000001
-1.44e-08 4.800000000000001 4.800000000000001 5.0
-1.4299999999999999e-08 4.800000000000001 4.800000000000001 5.0
-1.4199999999999998e-08 4.6000000000000005 4.800000000000001 4.800000000000001
-1.41e-08 4.6000000000000005 4.800000000000001 4.800000000000001
-1.4e-08 4.800000000000001 4.800000000000001 5.0
-1.3899999999999999e-08 4.800000000000001 4.800000000000001 5.0
-1.3799999999999998e-08 4.800000000000001 4.800000000000001 5.0
-1.37e-08 4.800000000000001 4.800000000000001 5.0
-1.36e-08 4.800000000000001 4.800000000000001 5.0
-1.3499999999999998e-08 4.800000000000001 4.800000000000001 5.0
-1.3400000000000001e-08 4.800000000000001 4.6000000000000005 4.800000000000001
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

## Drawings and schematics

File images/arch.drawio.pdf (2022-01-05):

# Bank Controller D_Bank_IO A_In D_IO WE

# Sup_In BID¹_In

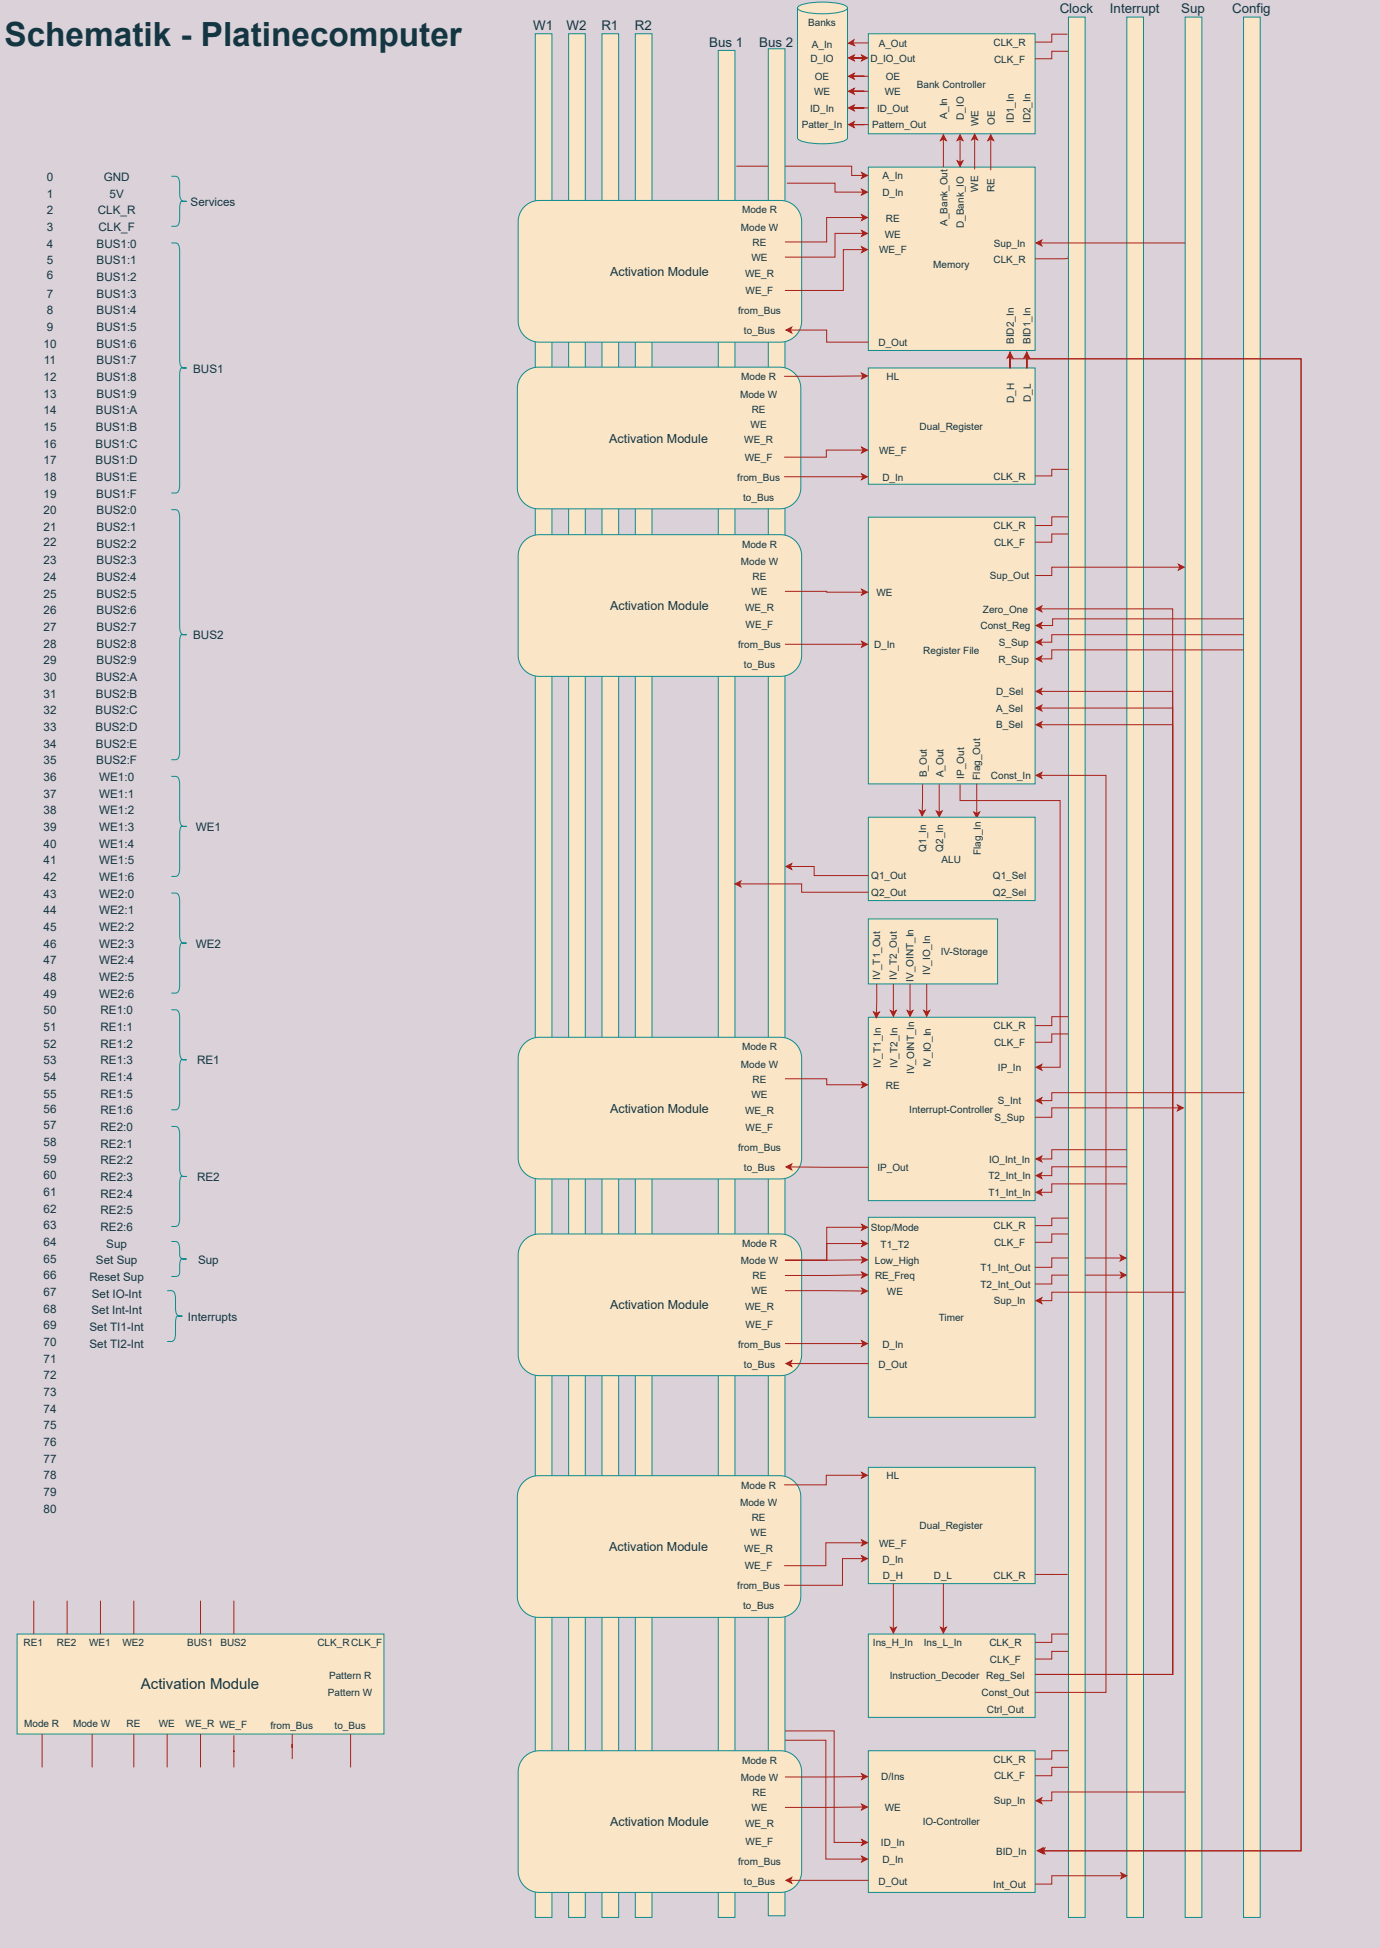
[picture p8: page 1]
Memory; D_Out; CLK_R; A_Bank_Out; IO-Controller; D/Ins; CLK_F; Sup_In; Interrupt-Controller; IV-Storage; IV_T1_In IV_T1_Out; IP_Out; S_Sup; IO_Int_In; Int_Out; T1_Int_In; T2_Int_In; S_Int; CLK_FBID²_In; Instruction_Decoder; Ins_H_In; Ctrl_Out; Register File A_Out; Flag_Out; D_Sel; A_Sel; B_Sel; Sup_Out; R_Sup; Zero_One; B_Out; ALU; Q1_Out; Q2_Out; Q2_Sel Flag_In; Q1_Sel; Timer; T1_Int_Out; T2_Int_Out; Low_High; Stop/Mode; Bus 1 Bus 2; Clock Interrupt; Sup; Config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

Set IO-Int
Set Int-Int
Set TI1-Int
Set TI2-Int

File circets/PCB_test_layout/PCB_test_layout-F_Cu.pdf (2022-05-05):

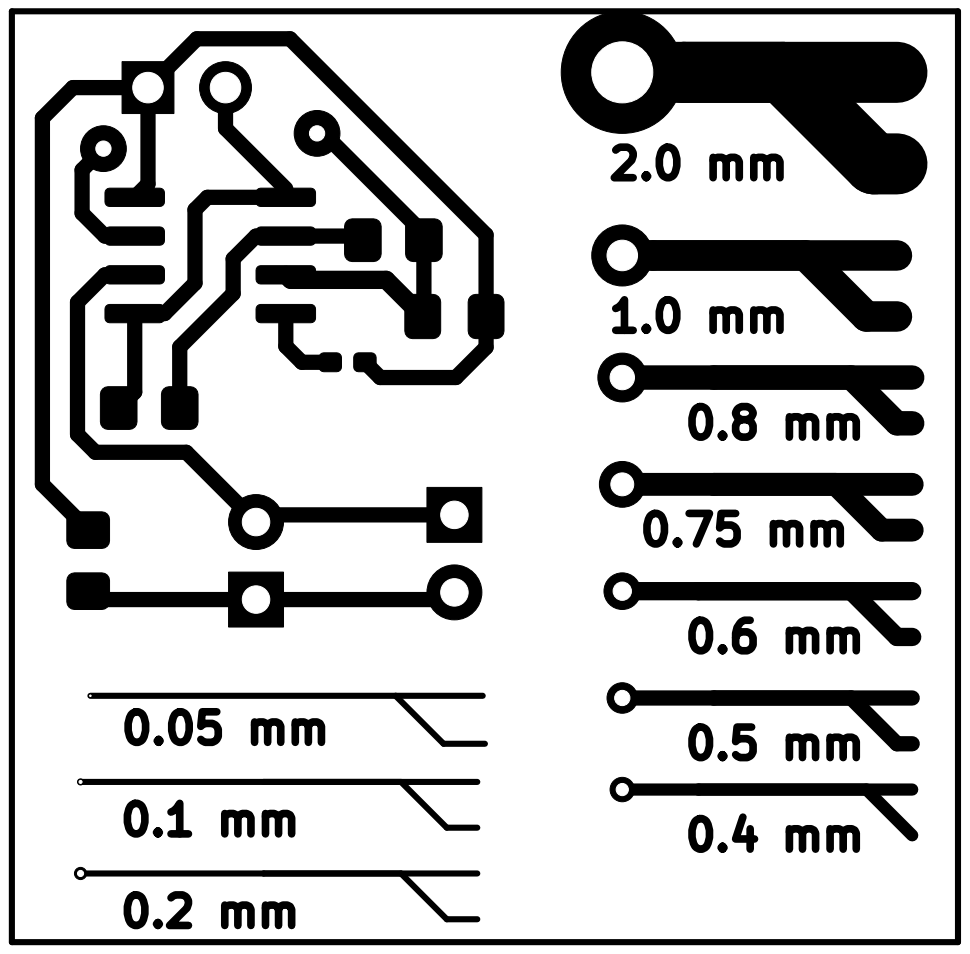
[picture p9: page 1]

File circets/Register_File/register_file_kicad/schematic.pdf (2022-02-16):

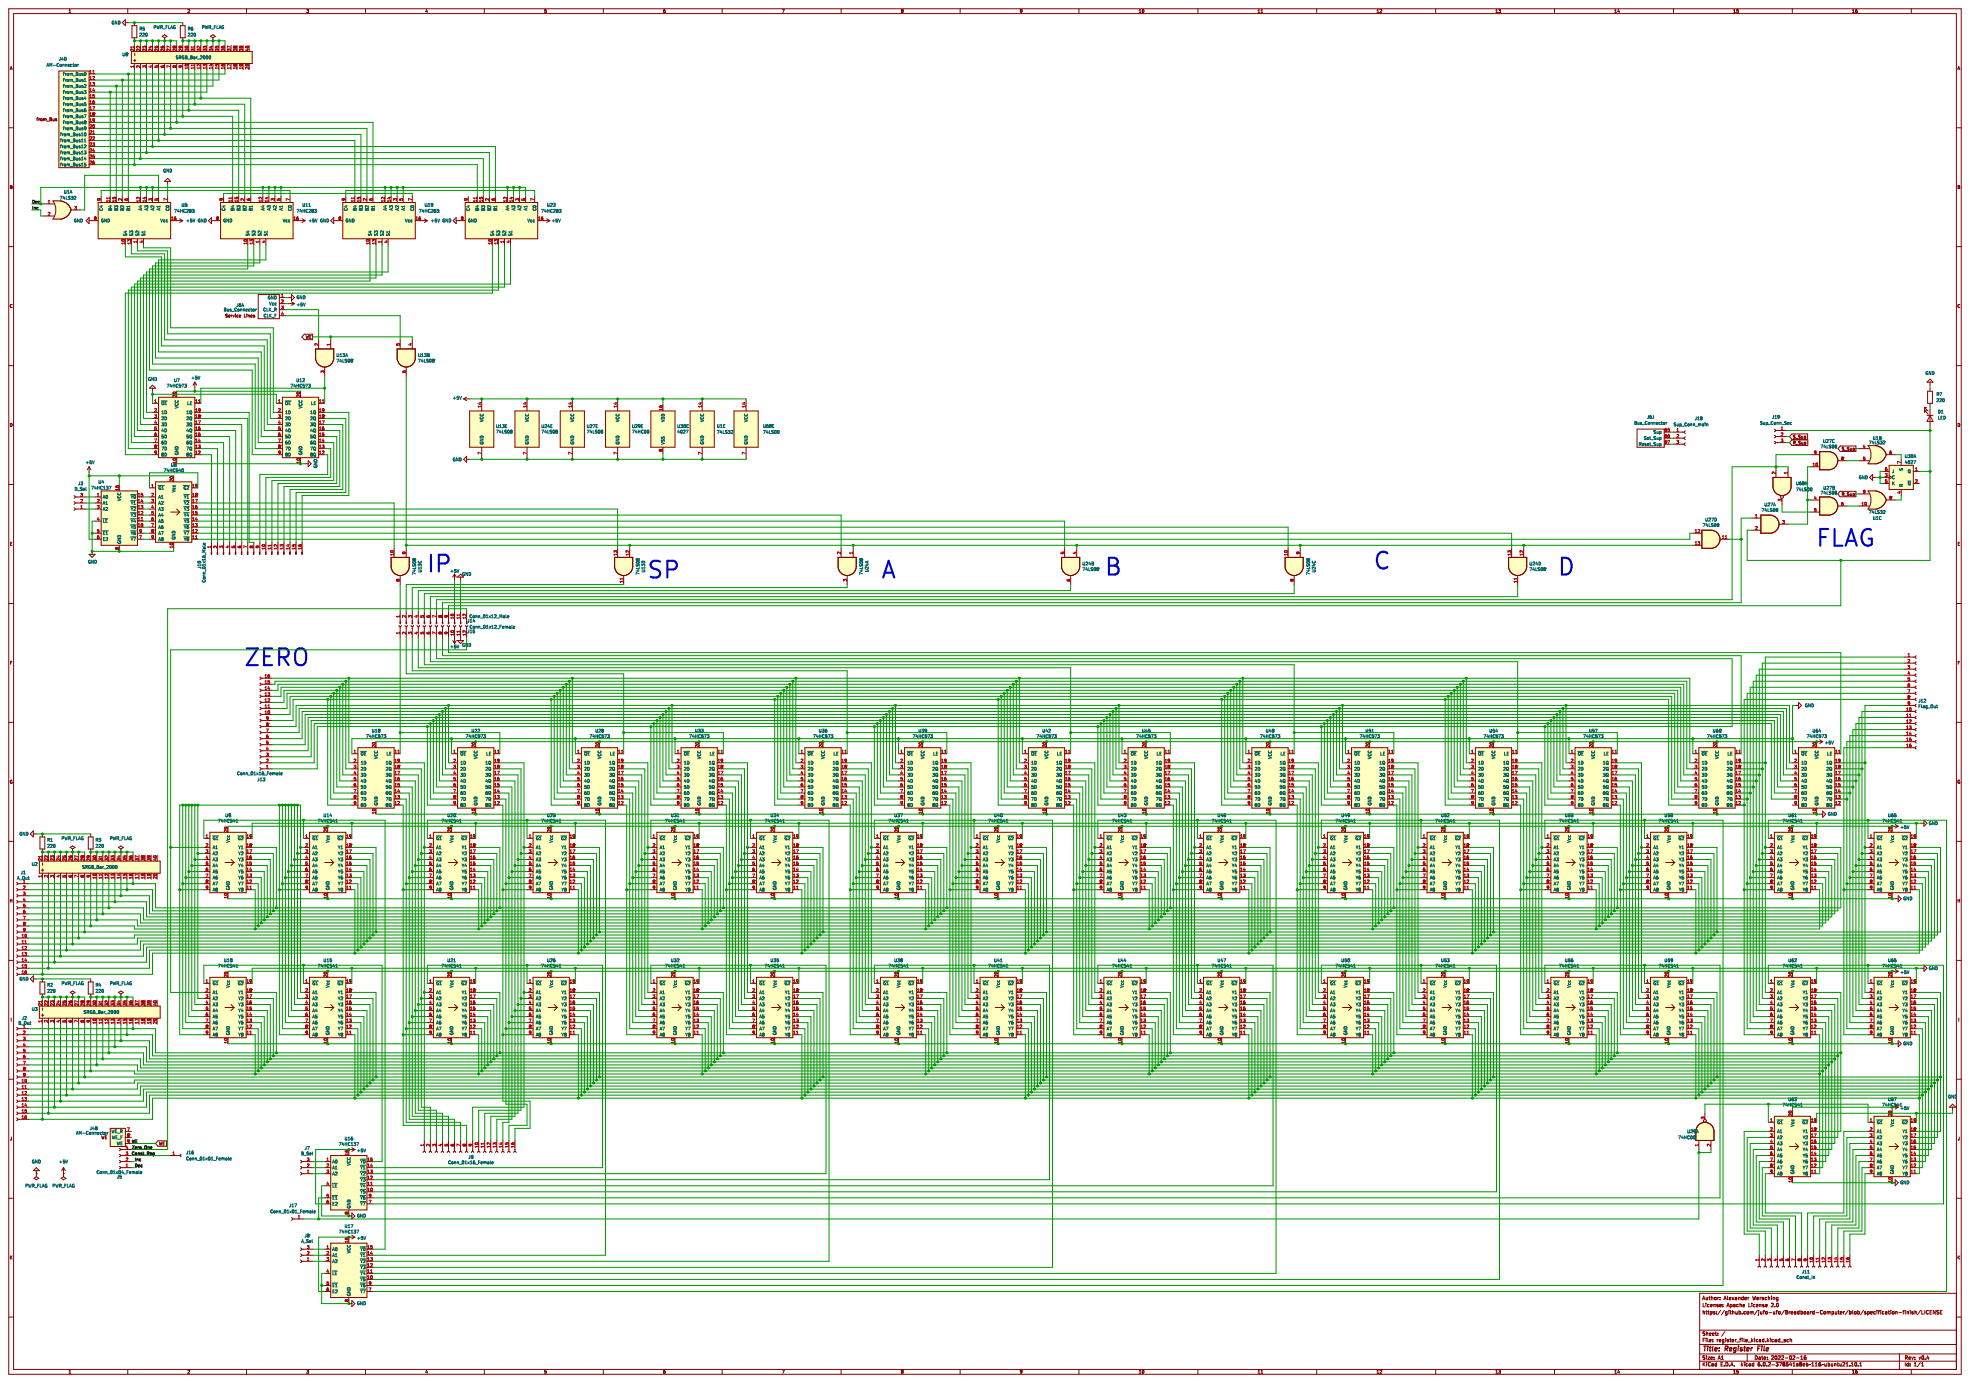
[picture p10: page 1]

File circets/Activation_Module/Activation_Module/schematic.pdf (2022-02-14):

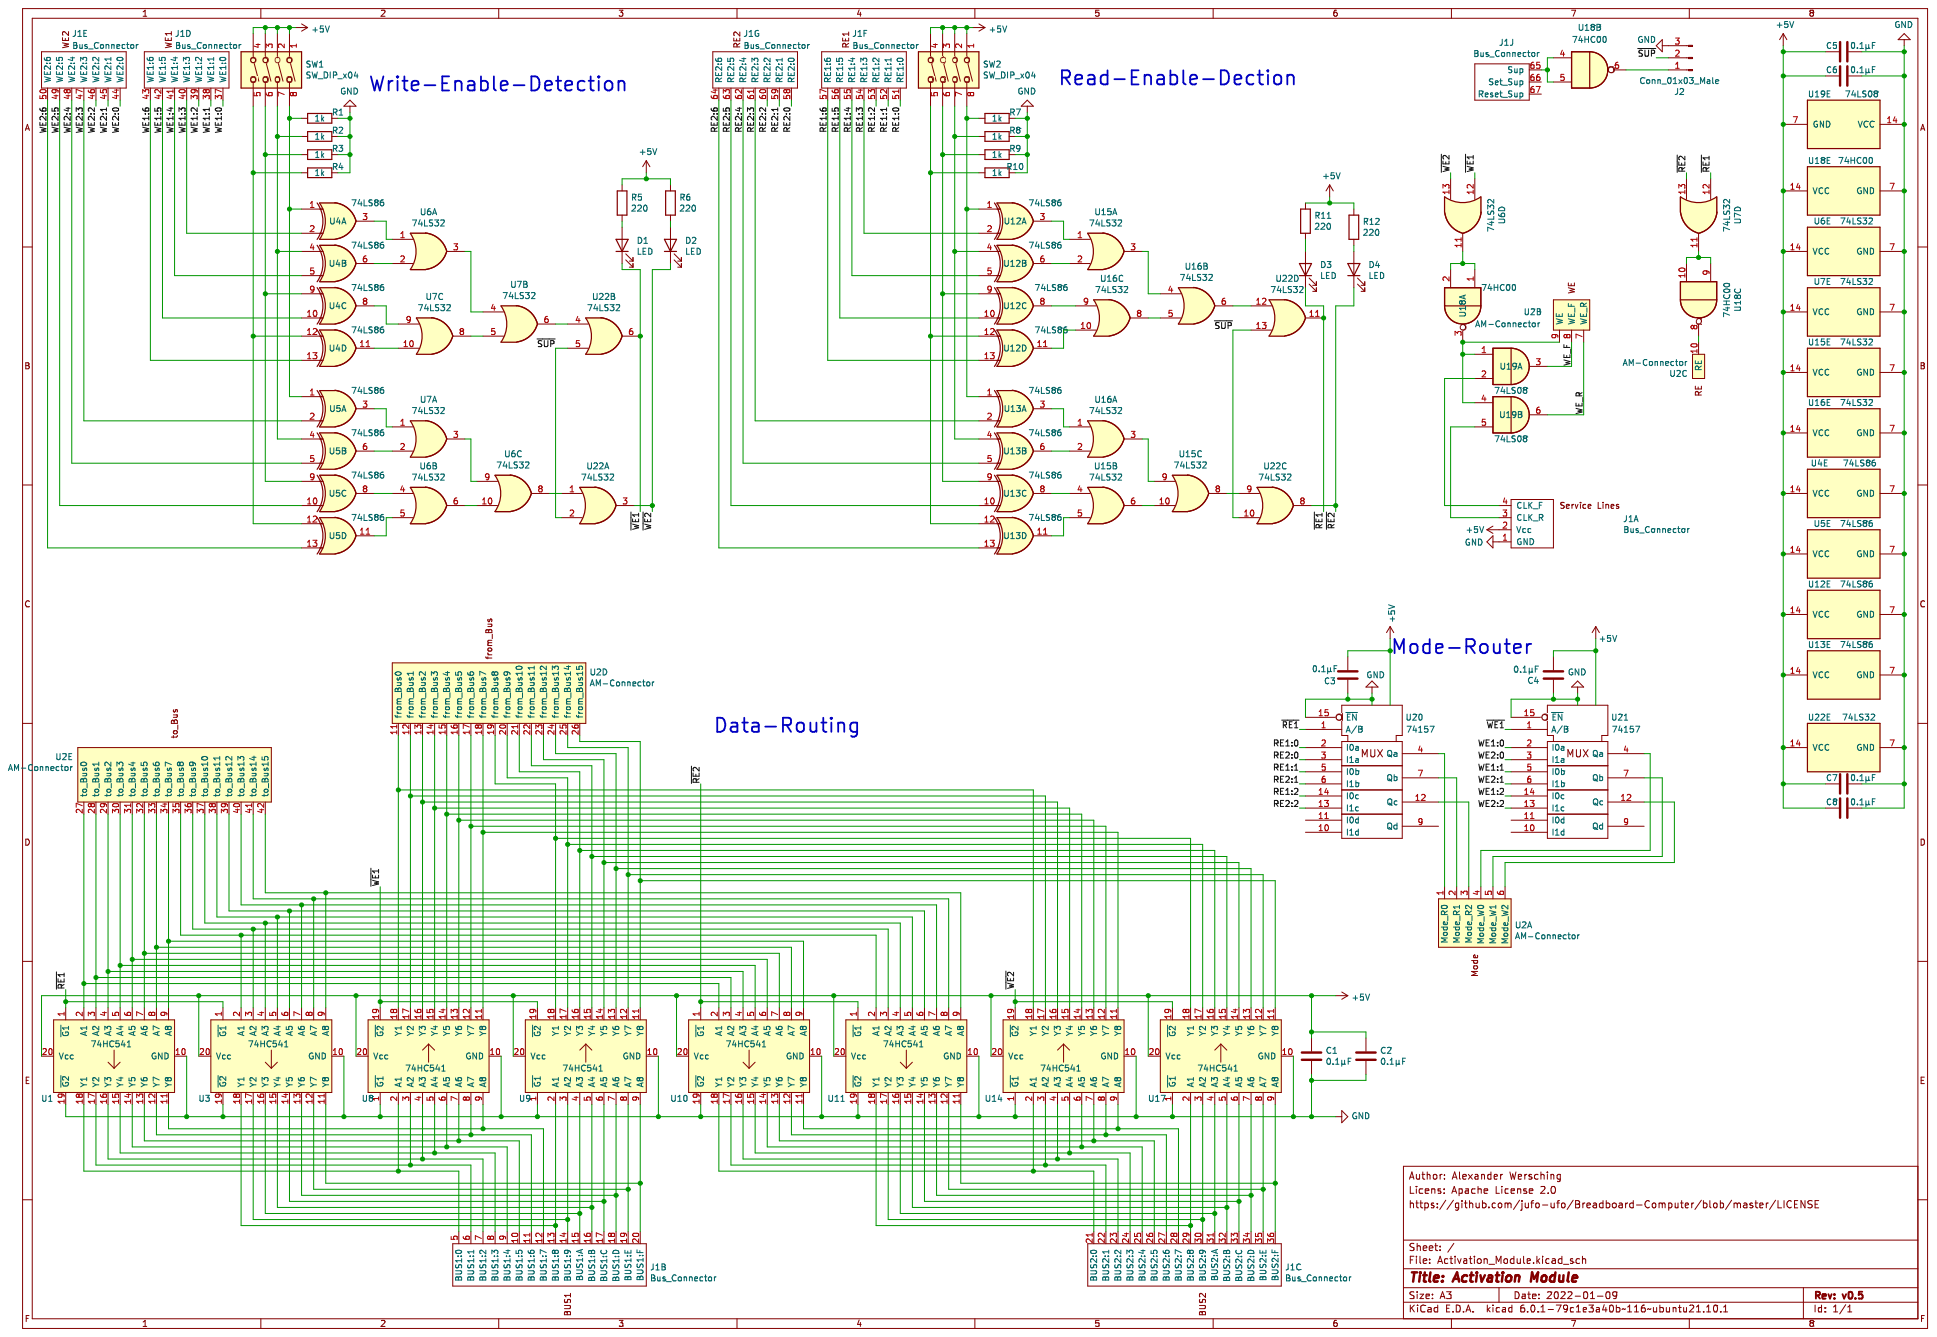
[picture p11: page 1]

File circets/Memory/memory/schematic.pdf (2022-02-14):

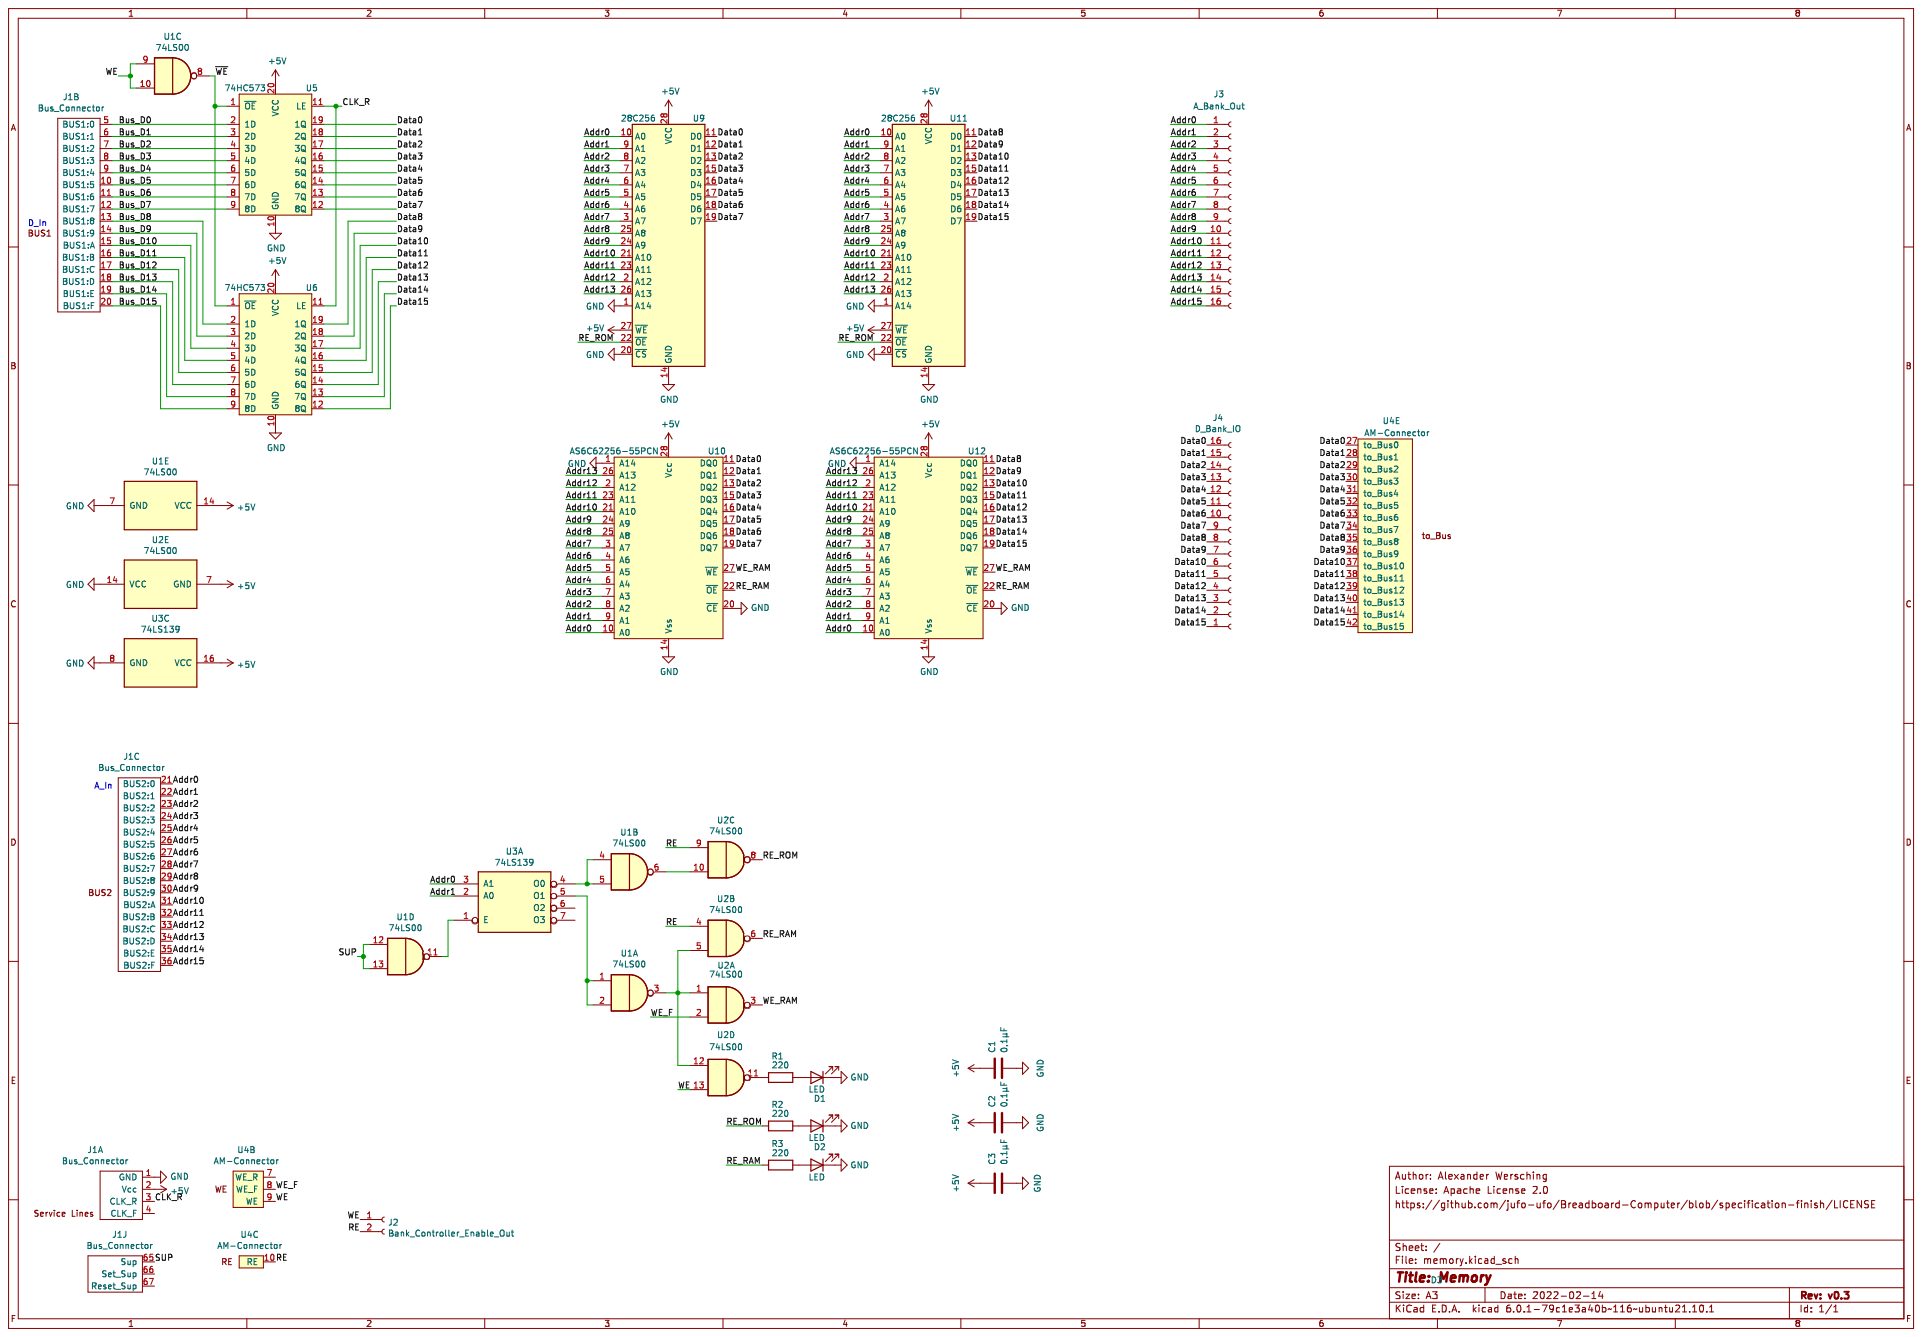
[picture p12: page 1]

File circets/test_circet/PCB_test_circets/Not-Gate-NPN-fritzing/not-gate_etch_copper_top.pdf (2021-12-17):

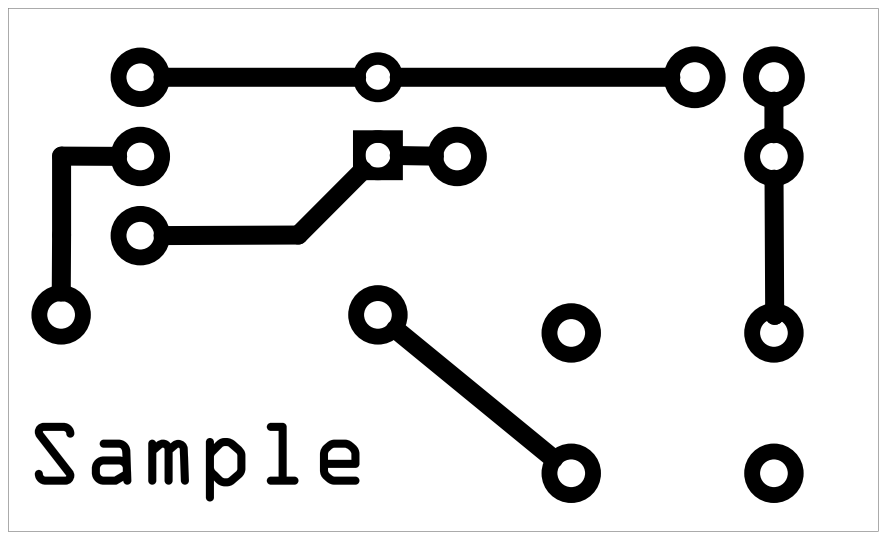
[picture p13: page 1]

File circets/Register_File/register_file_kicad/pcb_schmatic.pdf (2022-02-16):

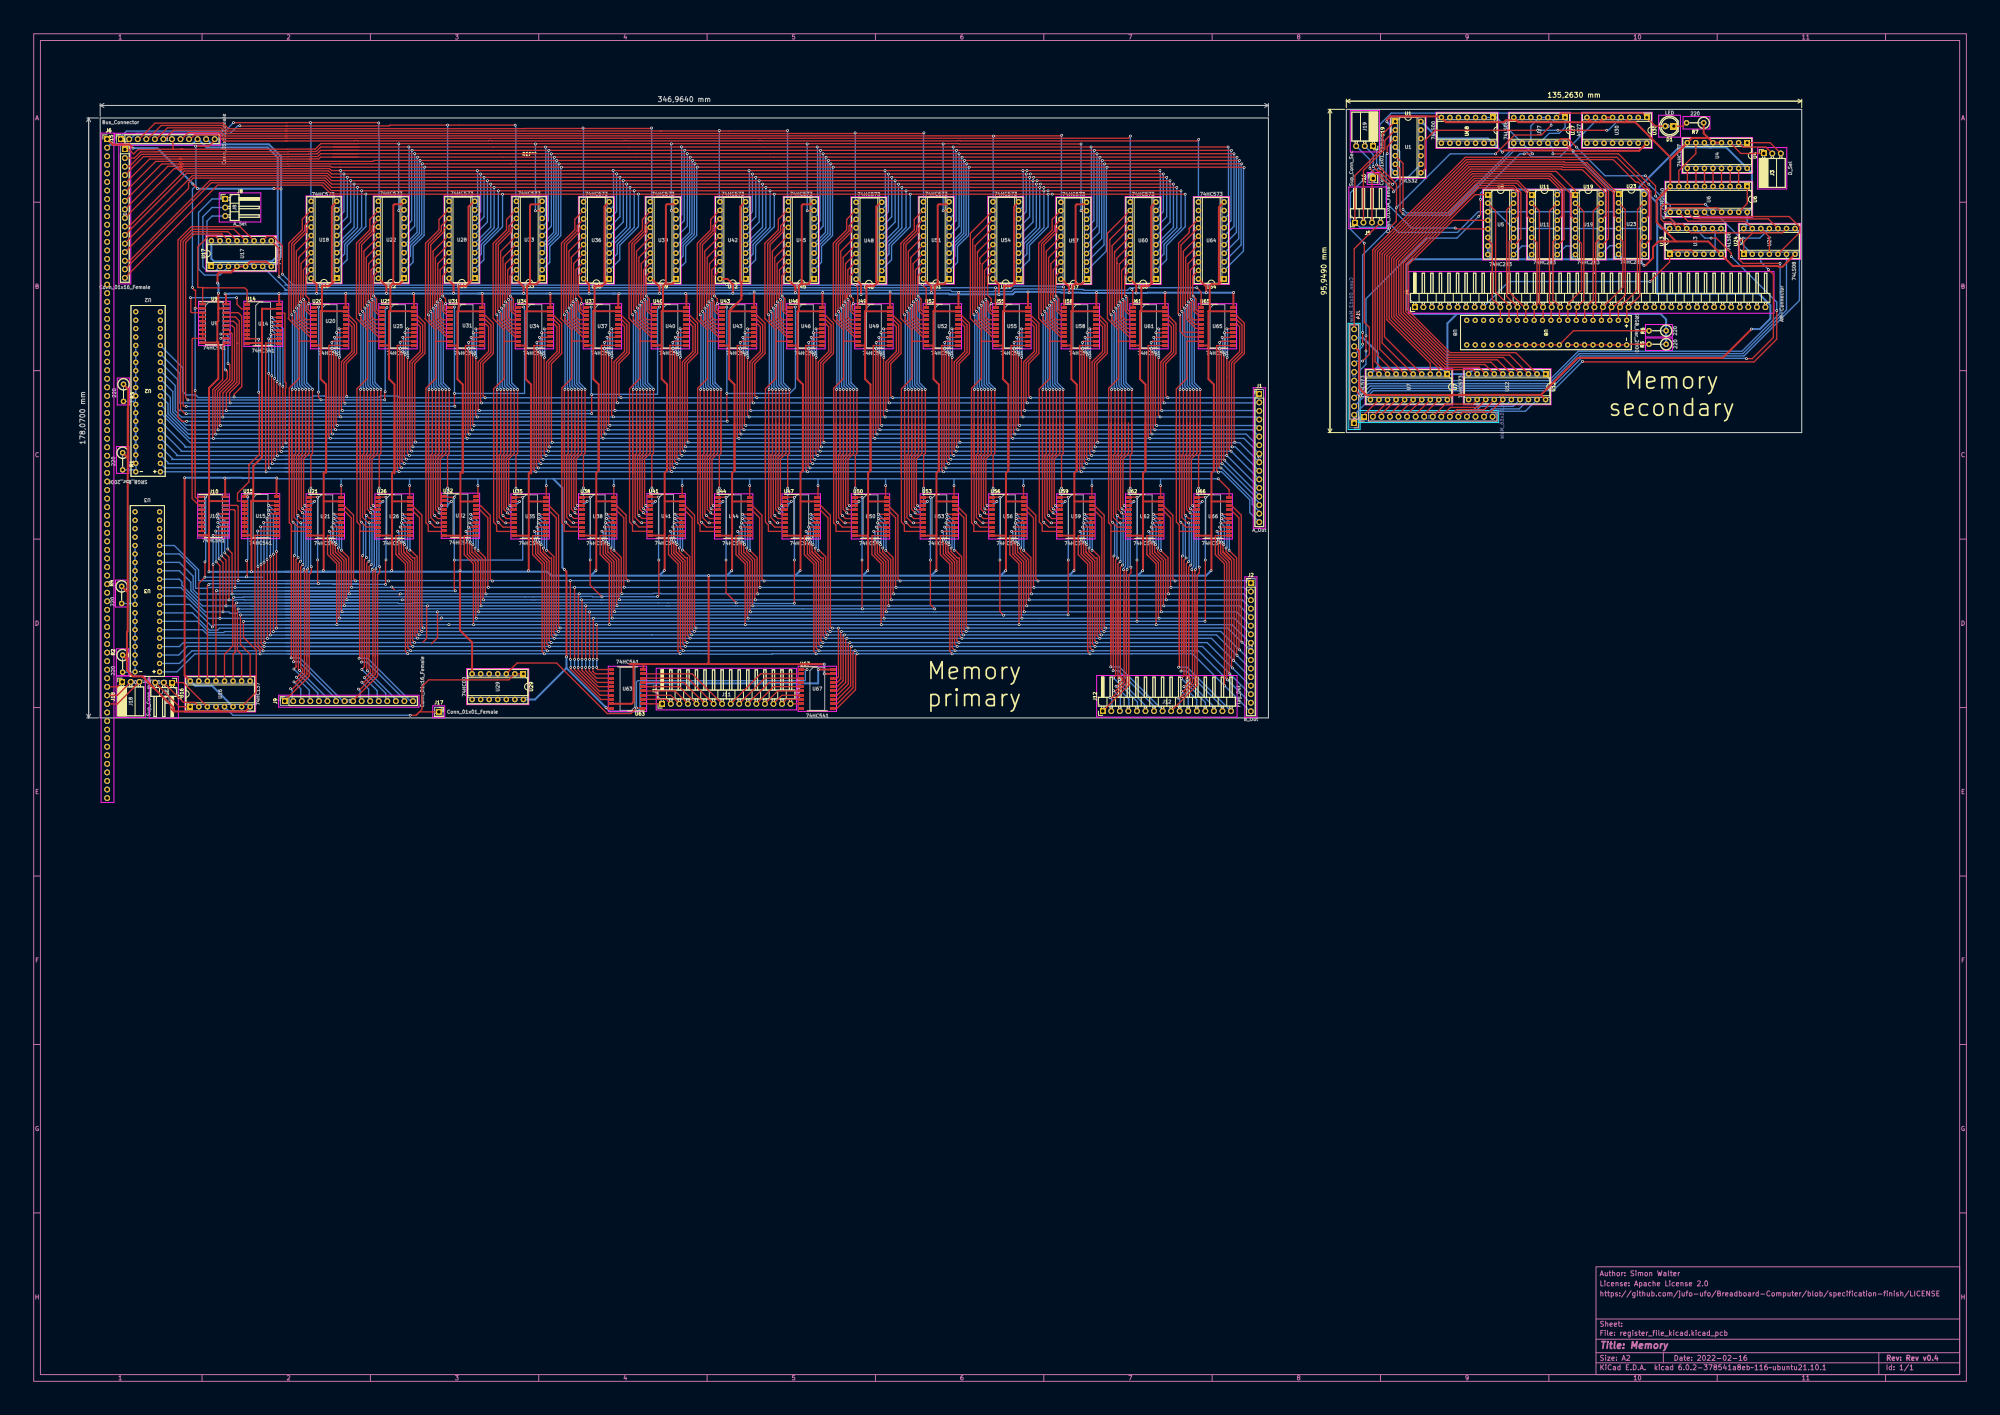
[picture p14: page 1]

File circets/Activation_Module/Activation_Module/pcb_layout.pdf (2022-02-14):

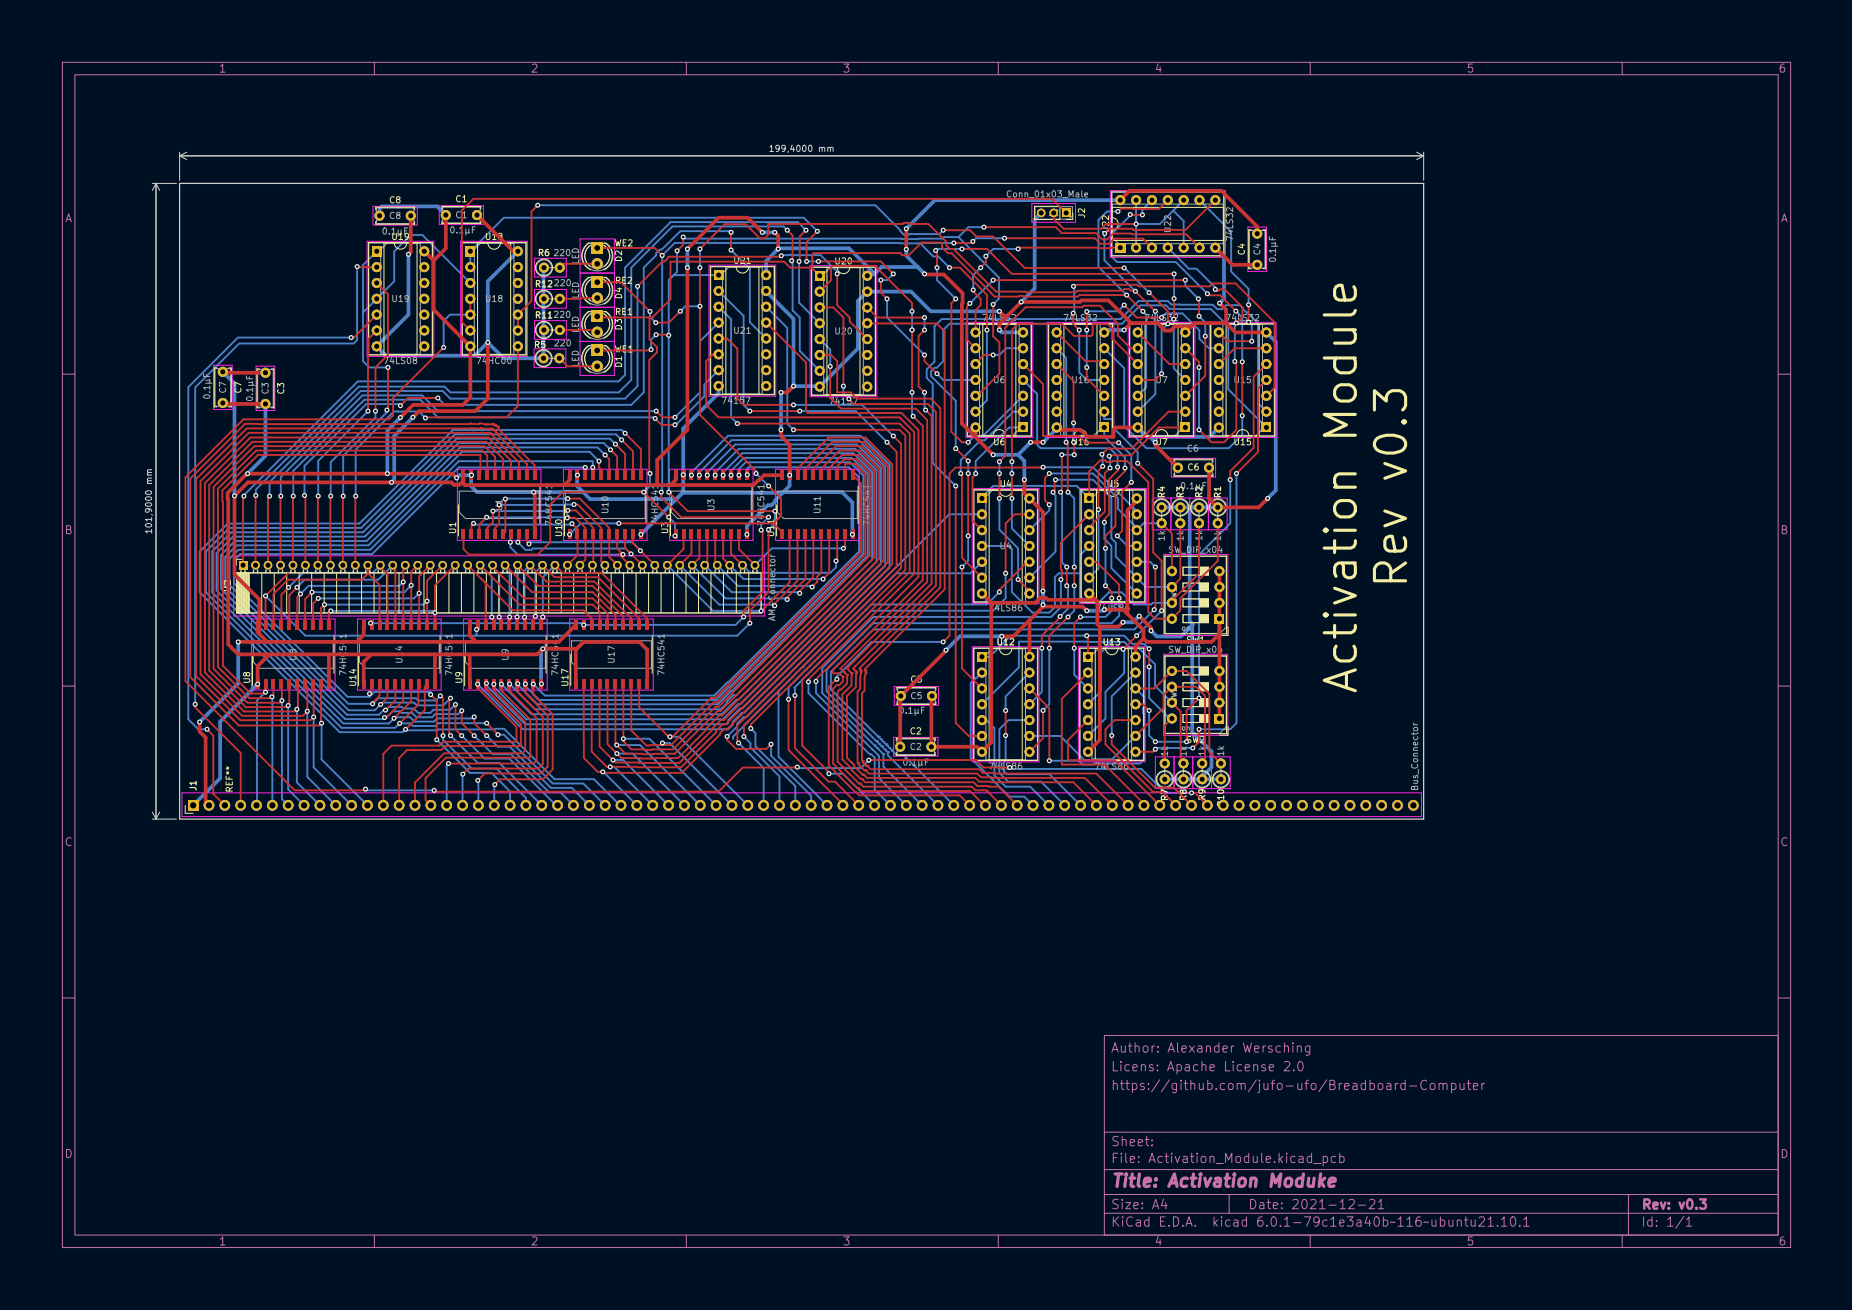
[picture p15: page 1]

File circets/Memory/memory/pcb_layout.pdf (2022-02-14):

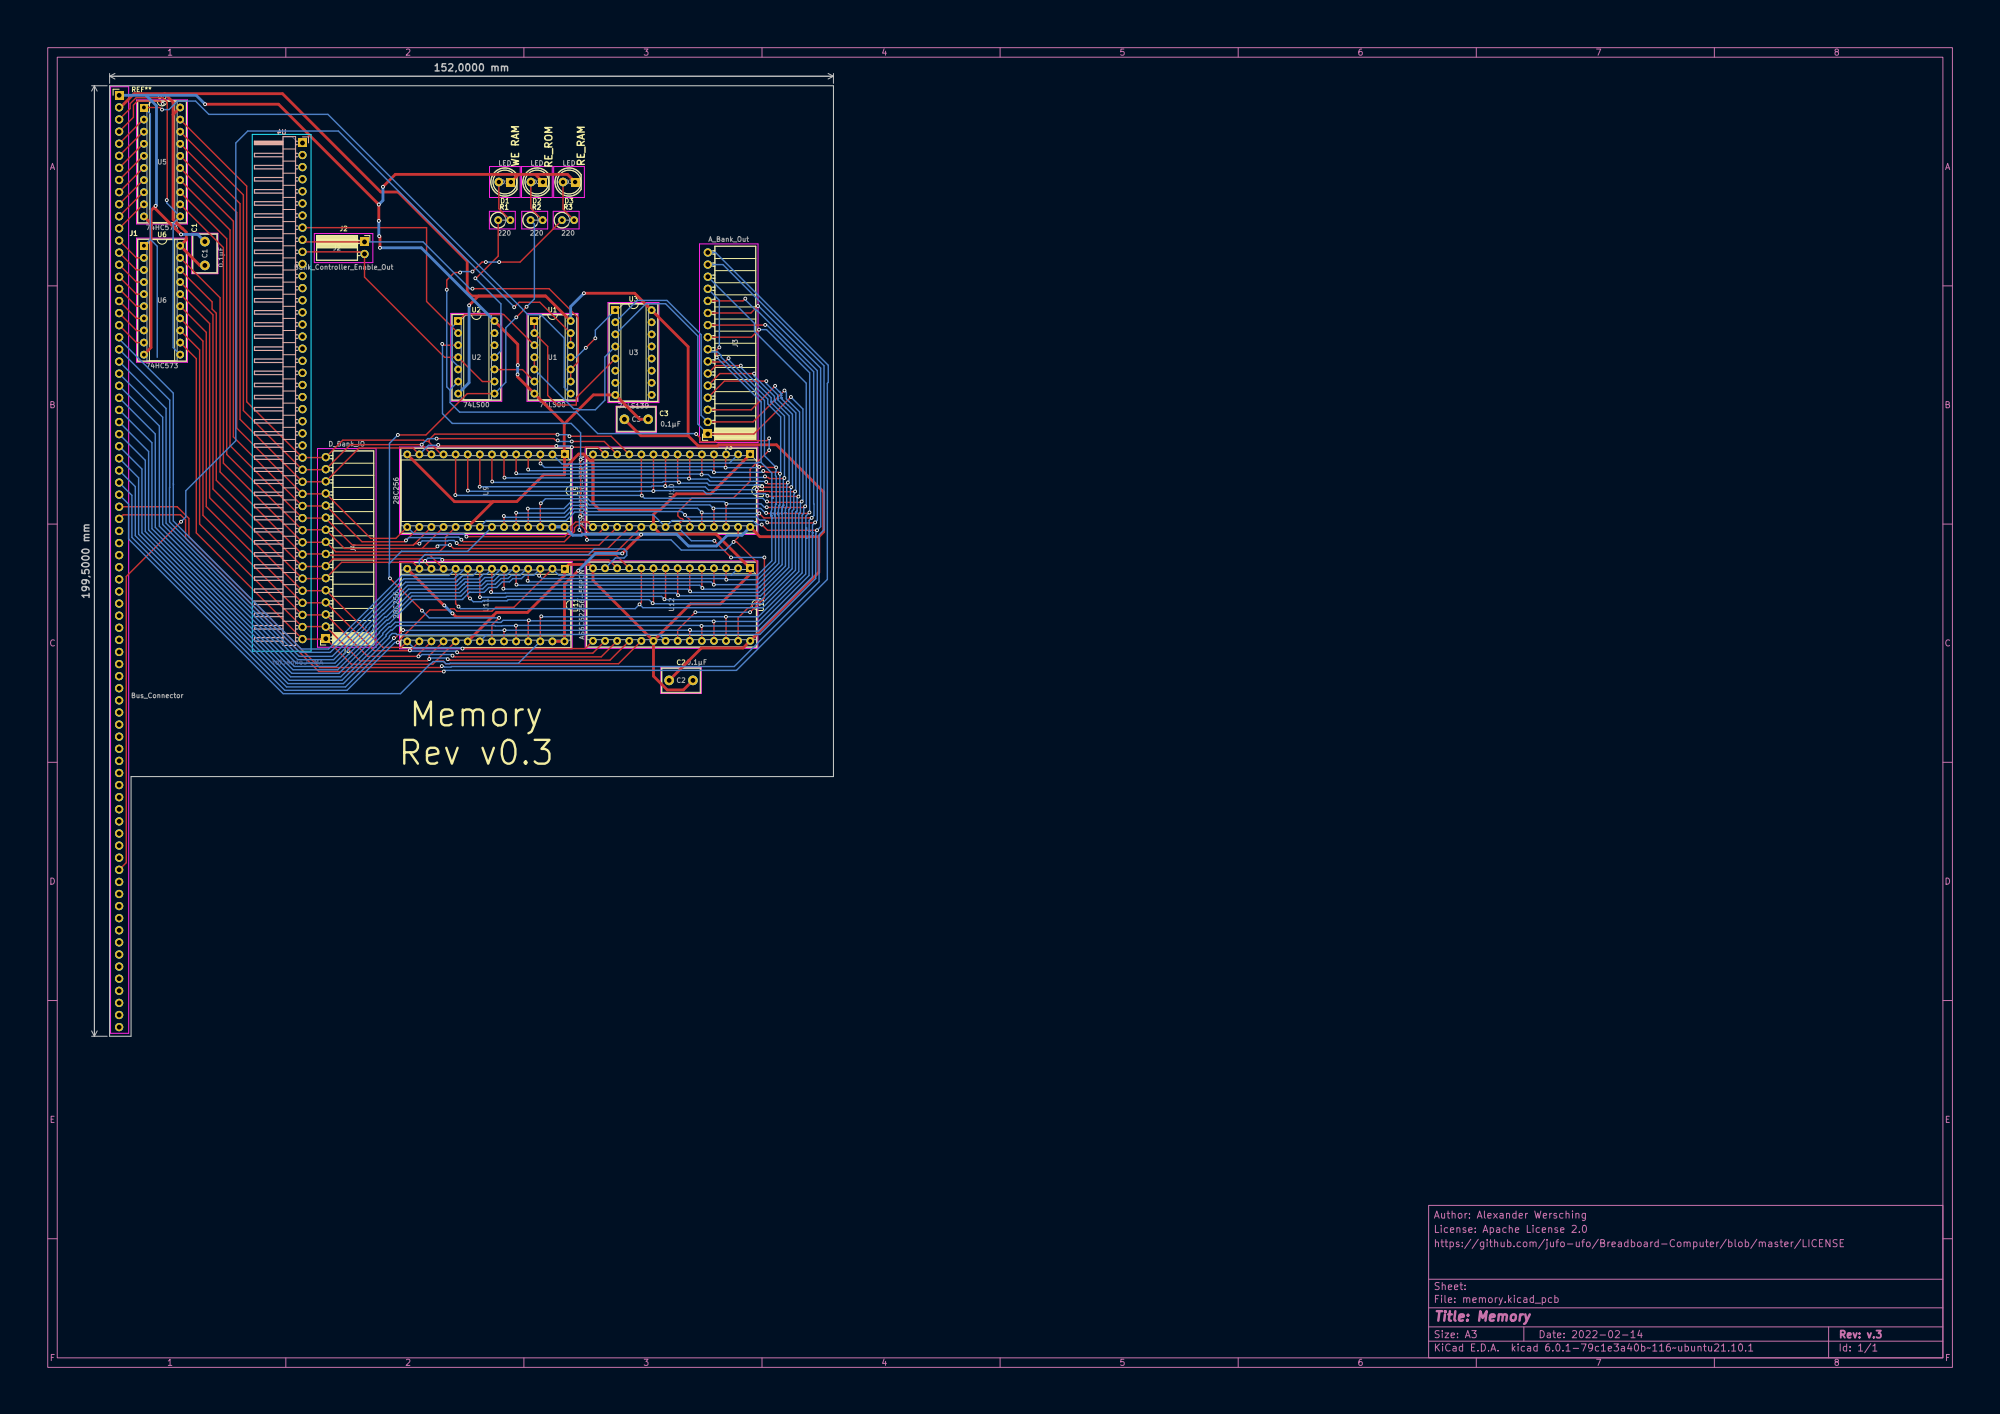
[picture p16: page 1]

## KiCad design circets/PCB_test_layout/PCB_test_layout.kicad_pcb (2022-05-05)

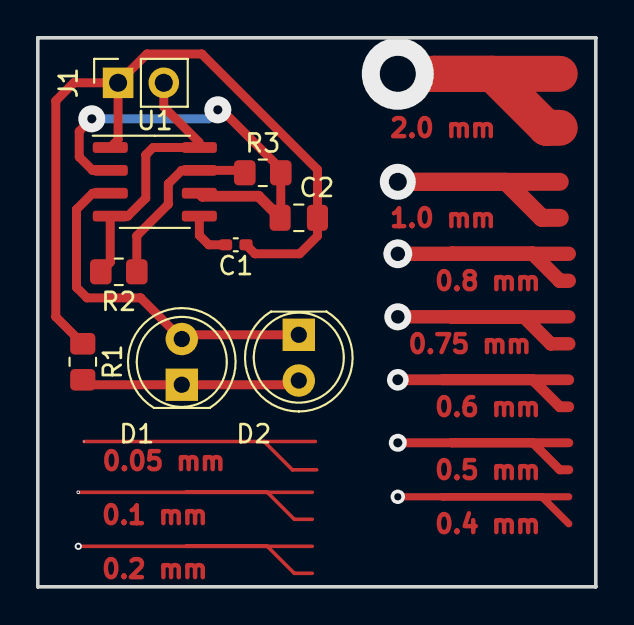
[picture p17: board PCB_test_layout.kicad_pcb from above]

Board: 2 copper layers, 31.0 x 30.5 mm, 9 parts (0 on the bottom side), 7 nets.

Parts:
C1: 10n; C_0402_1005Metric_Pad0.74x0.62mm_HandSolder
C2: 10µ; C_0805_2012Metric_Pad1.18x1.45mm_HandSolder
D1, D2: LED; LED_D5.0mm
J1: Conn_01x02_Male; PinSocket_1x02_P2.54mm_Vertical
R1: 220; R_0805_2012Metric_Pad1.20x1.40mm_HandSolder
R2: 40k; R_0805_2012Metric_Pad1.20x1.40mm_HandSolder
R3: 10k; R_0805_2012Metric_Pad1.20x1.40mm_HandSolder
U1: NE555D; SOIC-8_3.9x4.9mm_P1.27mm

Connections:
+5V: J1.2, R2.2, U1.4 (R), U1.8 (VCC)
GND: C1.1, C2.2, J1.1, R1.1, U1.1 (GND)
unnamed: C1.2, U1.5 (CV)
unnamed: C2.1, R3.2, U1.2 (TR), U1.6 (THR)
unnamed: D1.1 (K), D2.2 (A), R1.2
unnamed: D1.2 (A), D2.1 (K), U1.3 (Q)
unnamed: R2.1, R3.1, U1.7 (DIS)

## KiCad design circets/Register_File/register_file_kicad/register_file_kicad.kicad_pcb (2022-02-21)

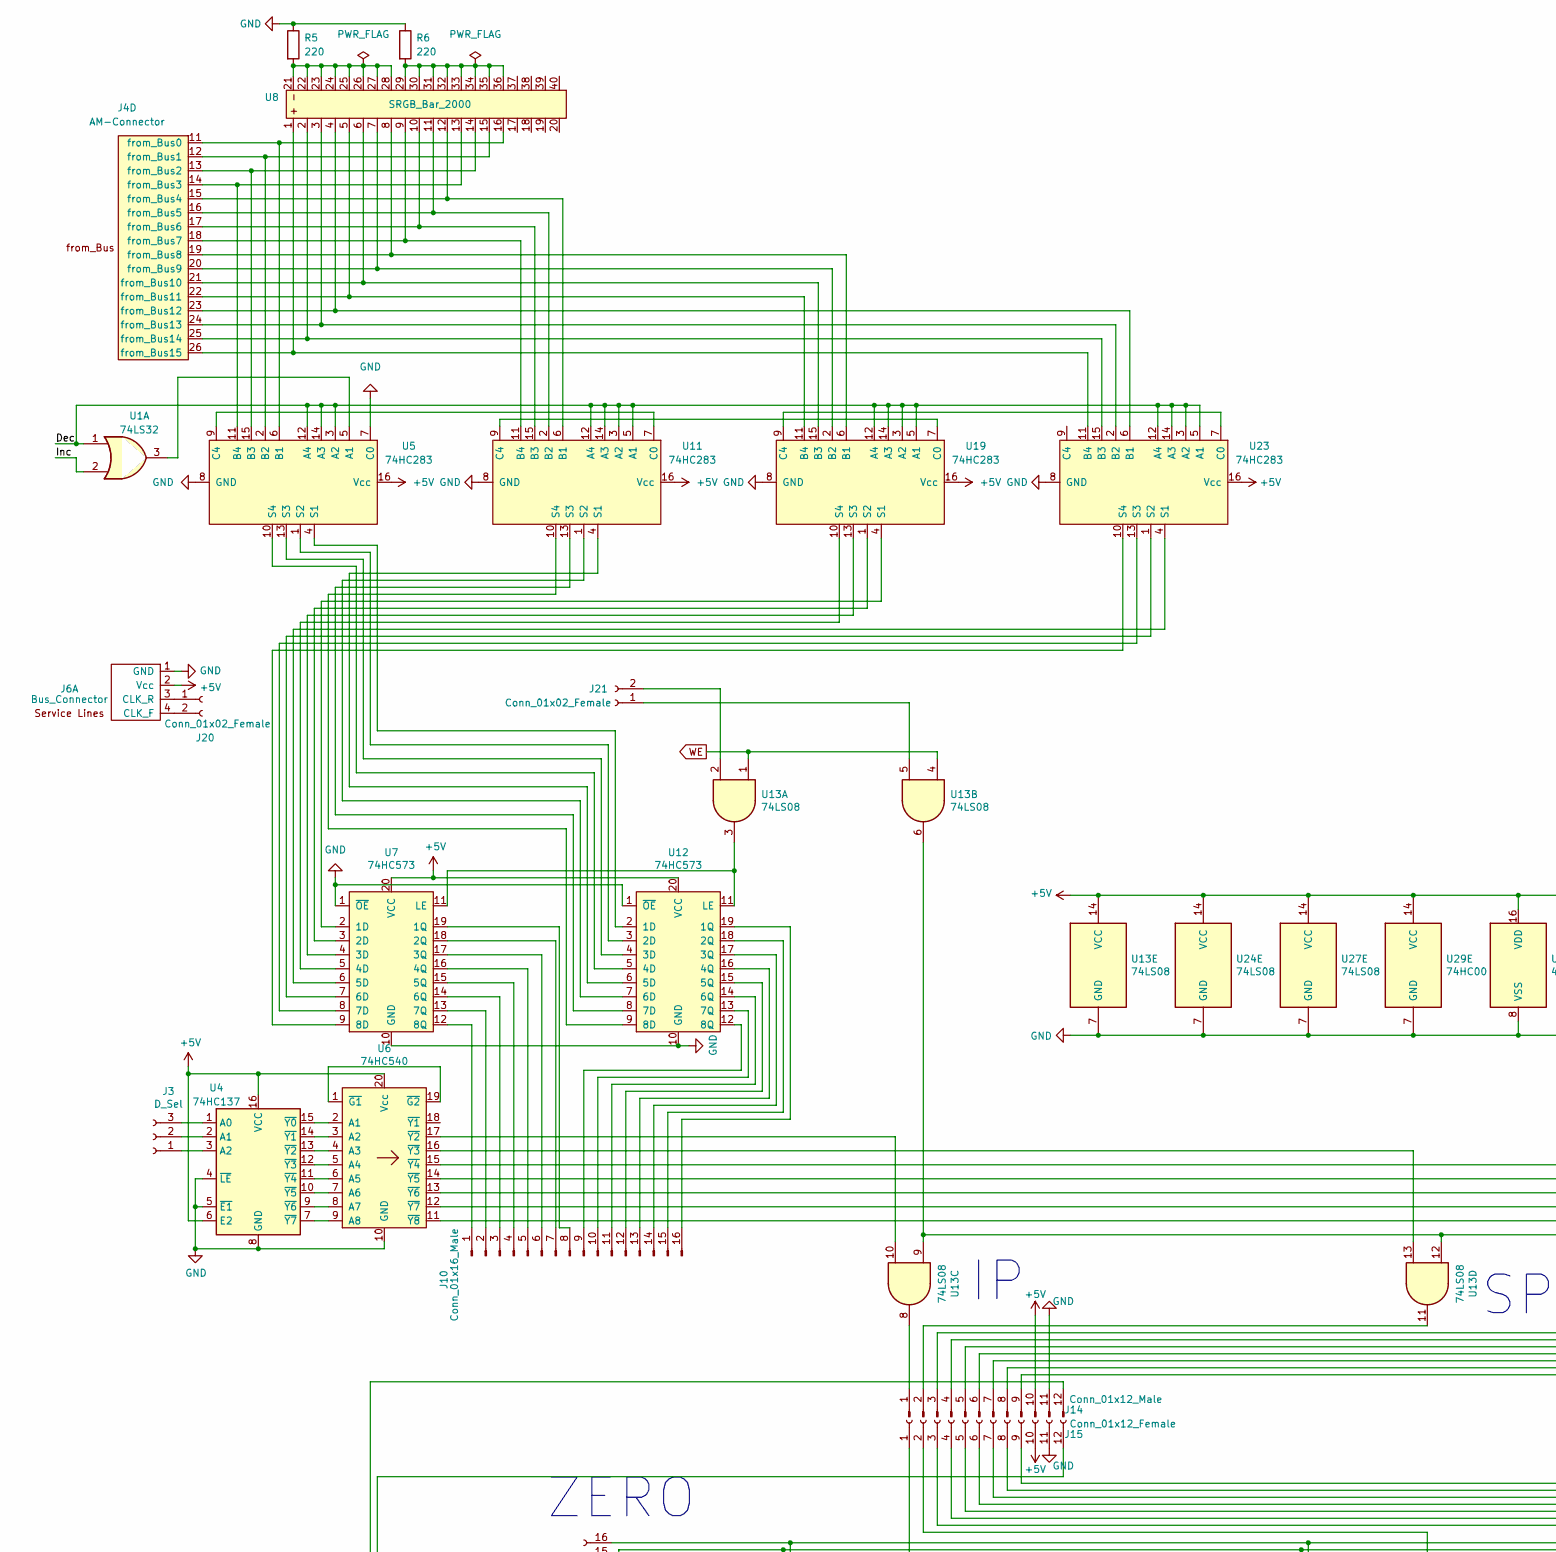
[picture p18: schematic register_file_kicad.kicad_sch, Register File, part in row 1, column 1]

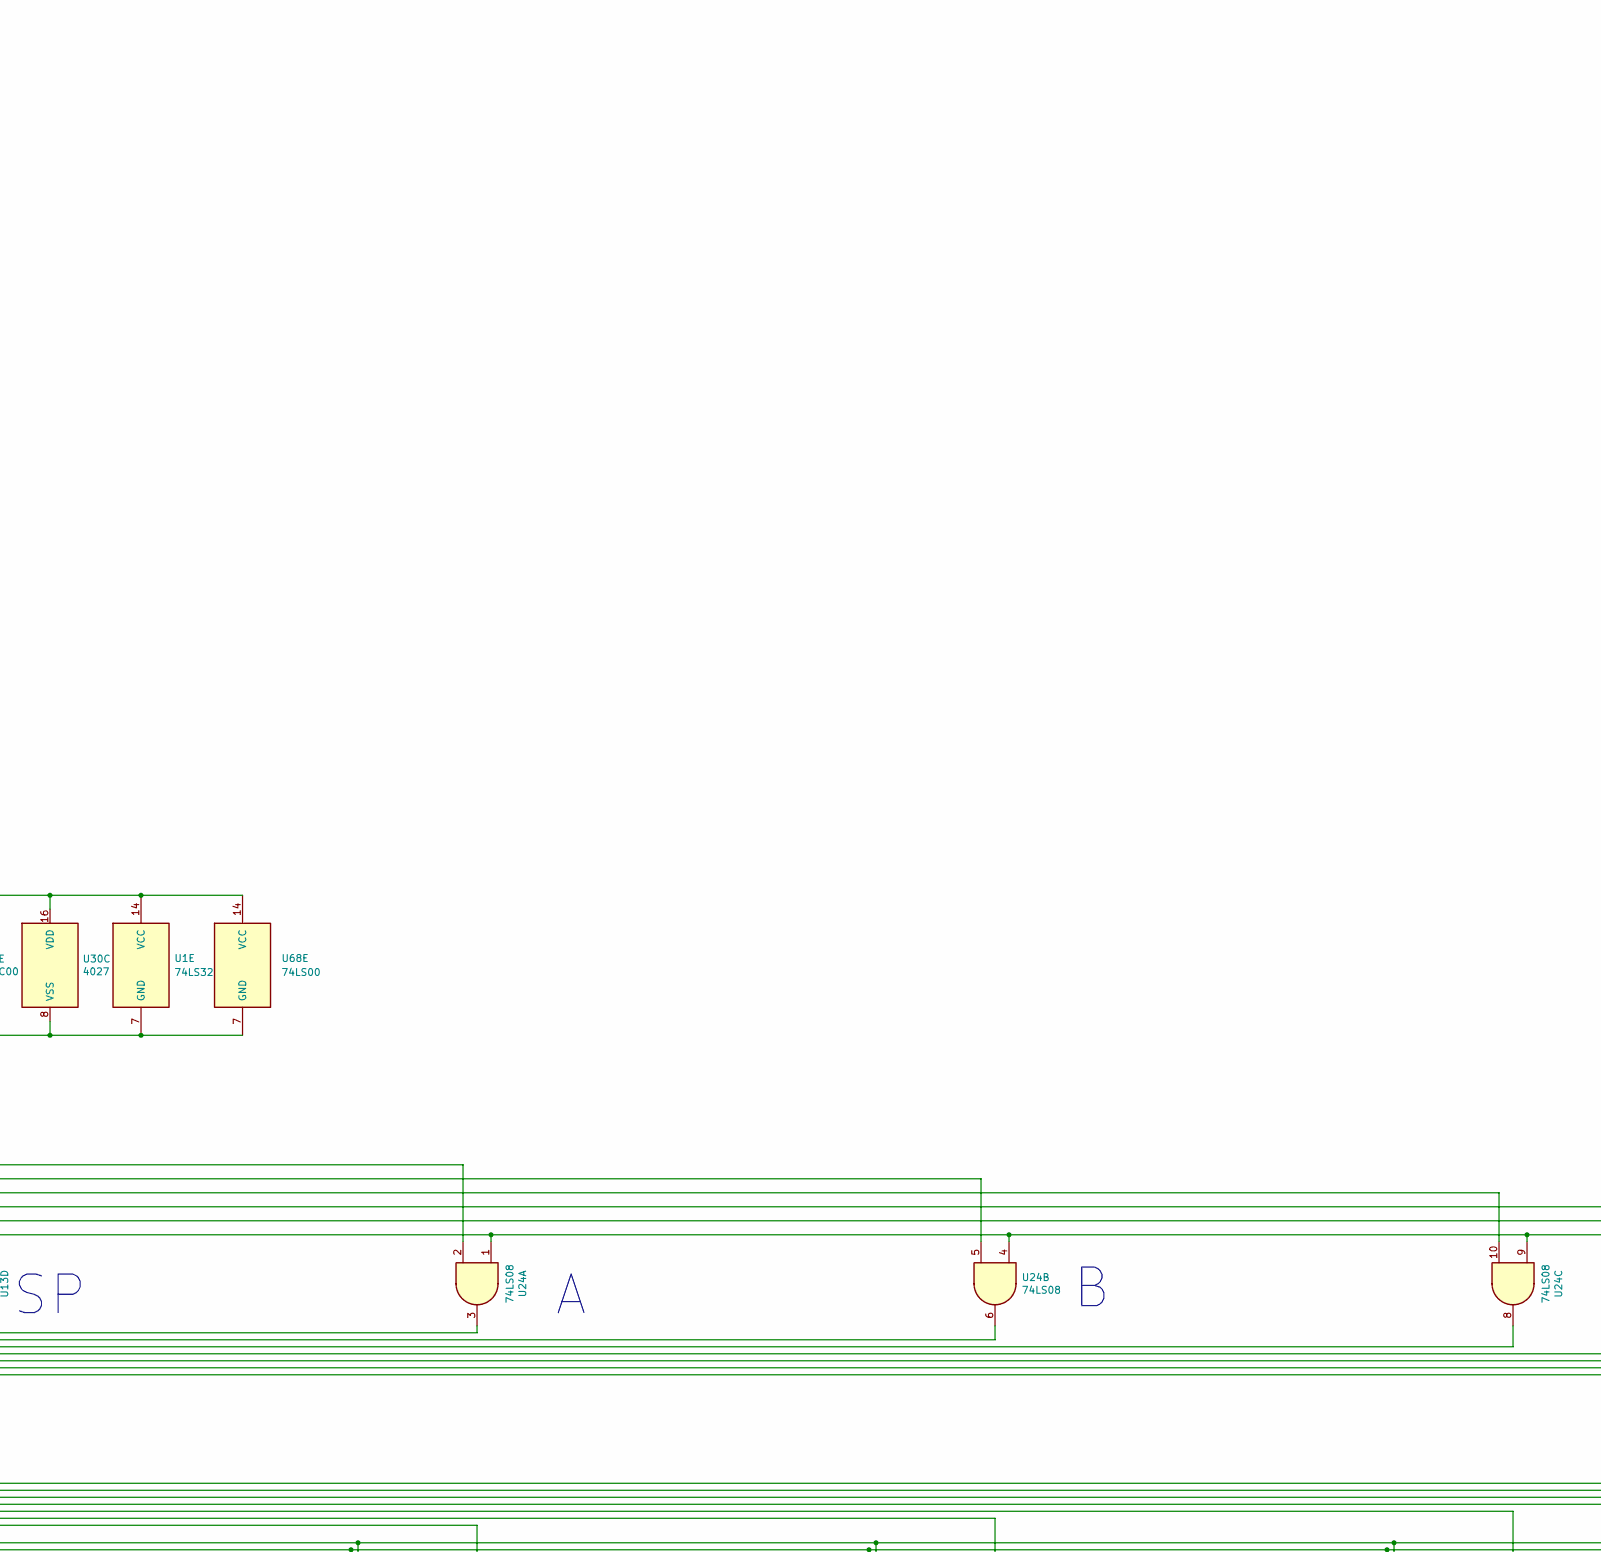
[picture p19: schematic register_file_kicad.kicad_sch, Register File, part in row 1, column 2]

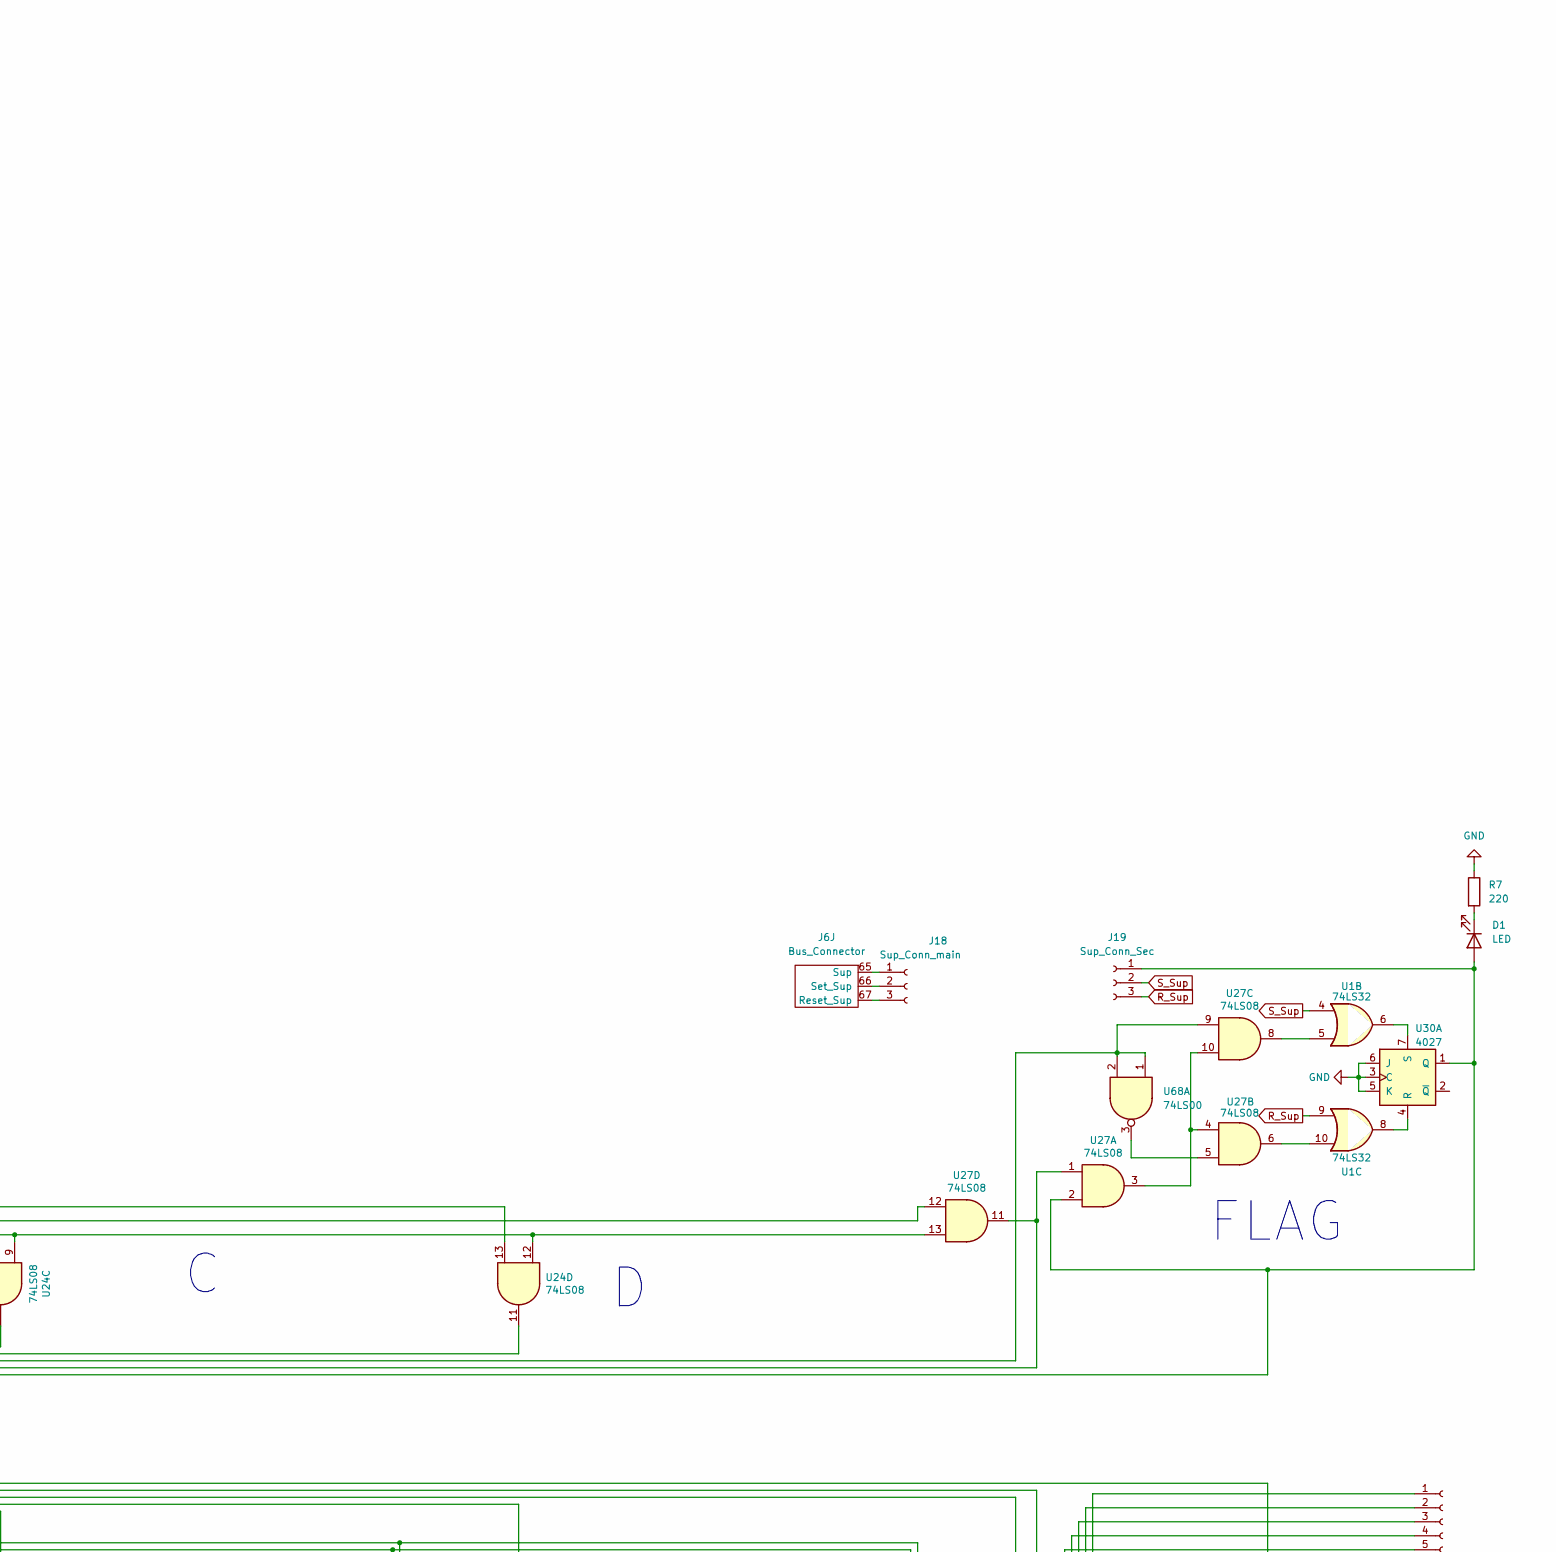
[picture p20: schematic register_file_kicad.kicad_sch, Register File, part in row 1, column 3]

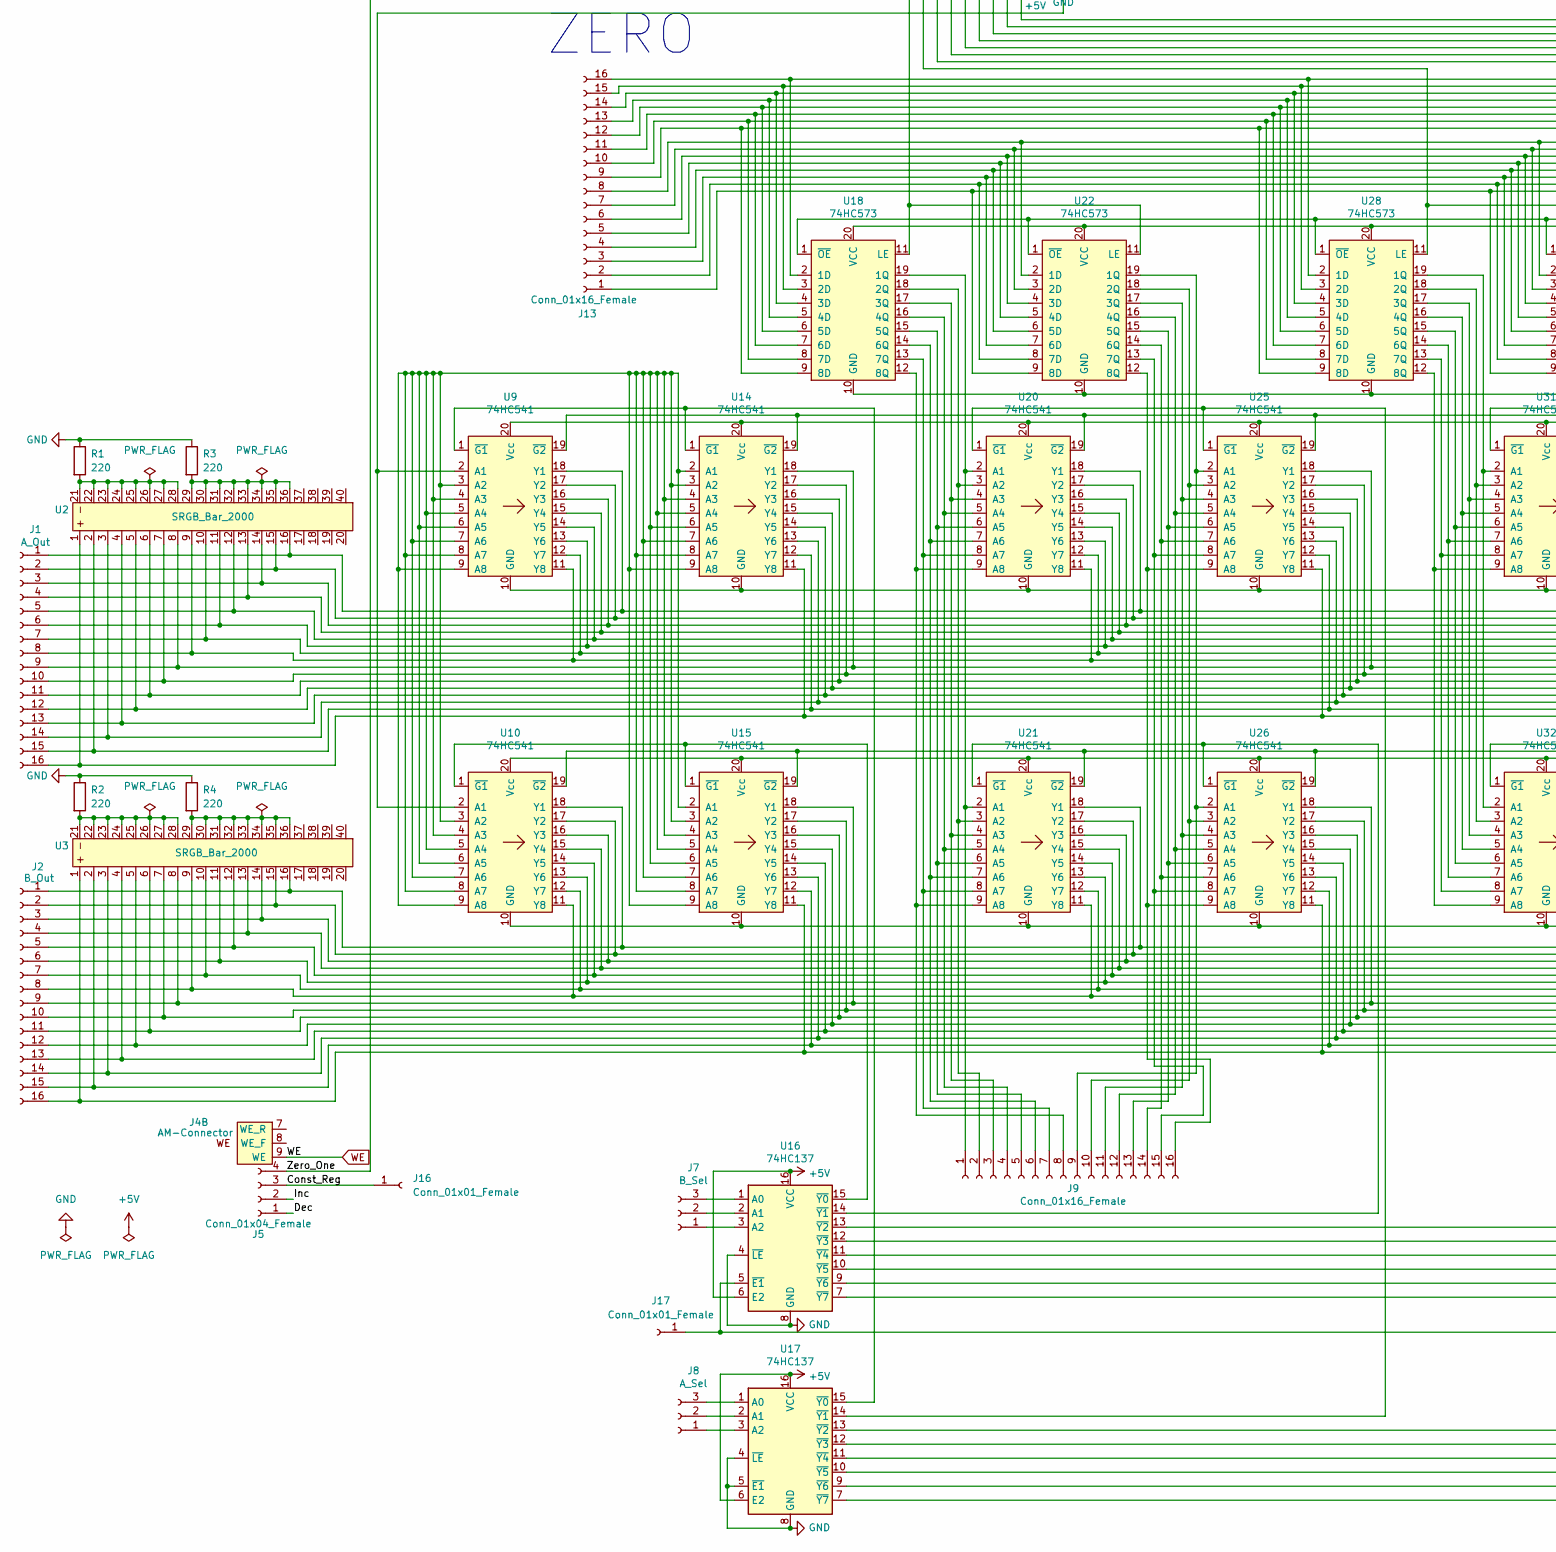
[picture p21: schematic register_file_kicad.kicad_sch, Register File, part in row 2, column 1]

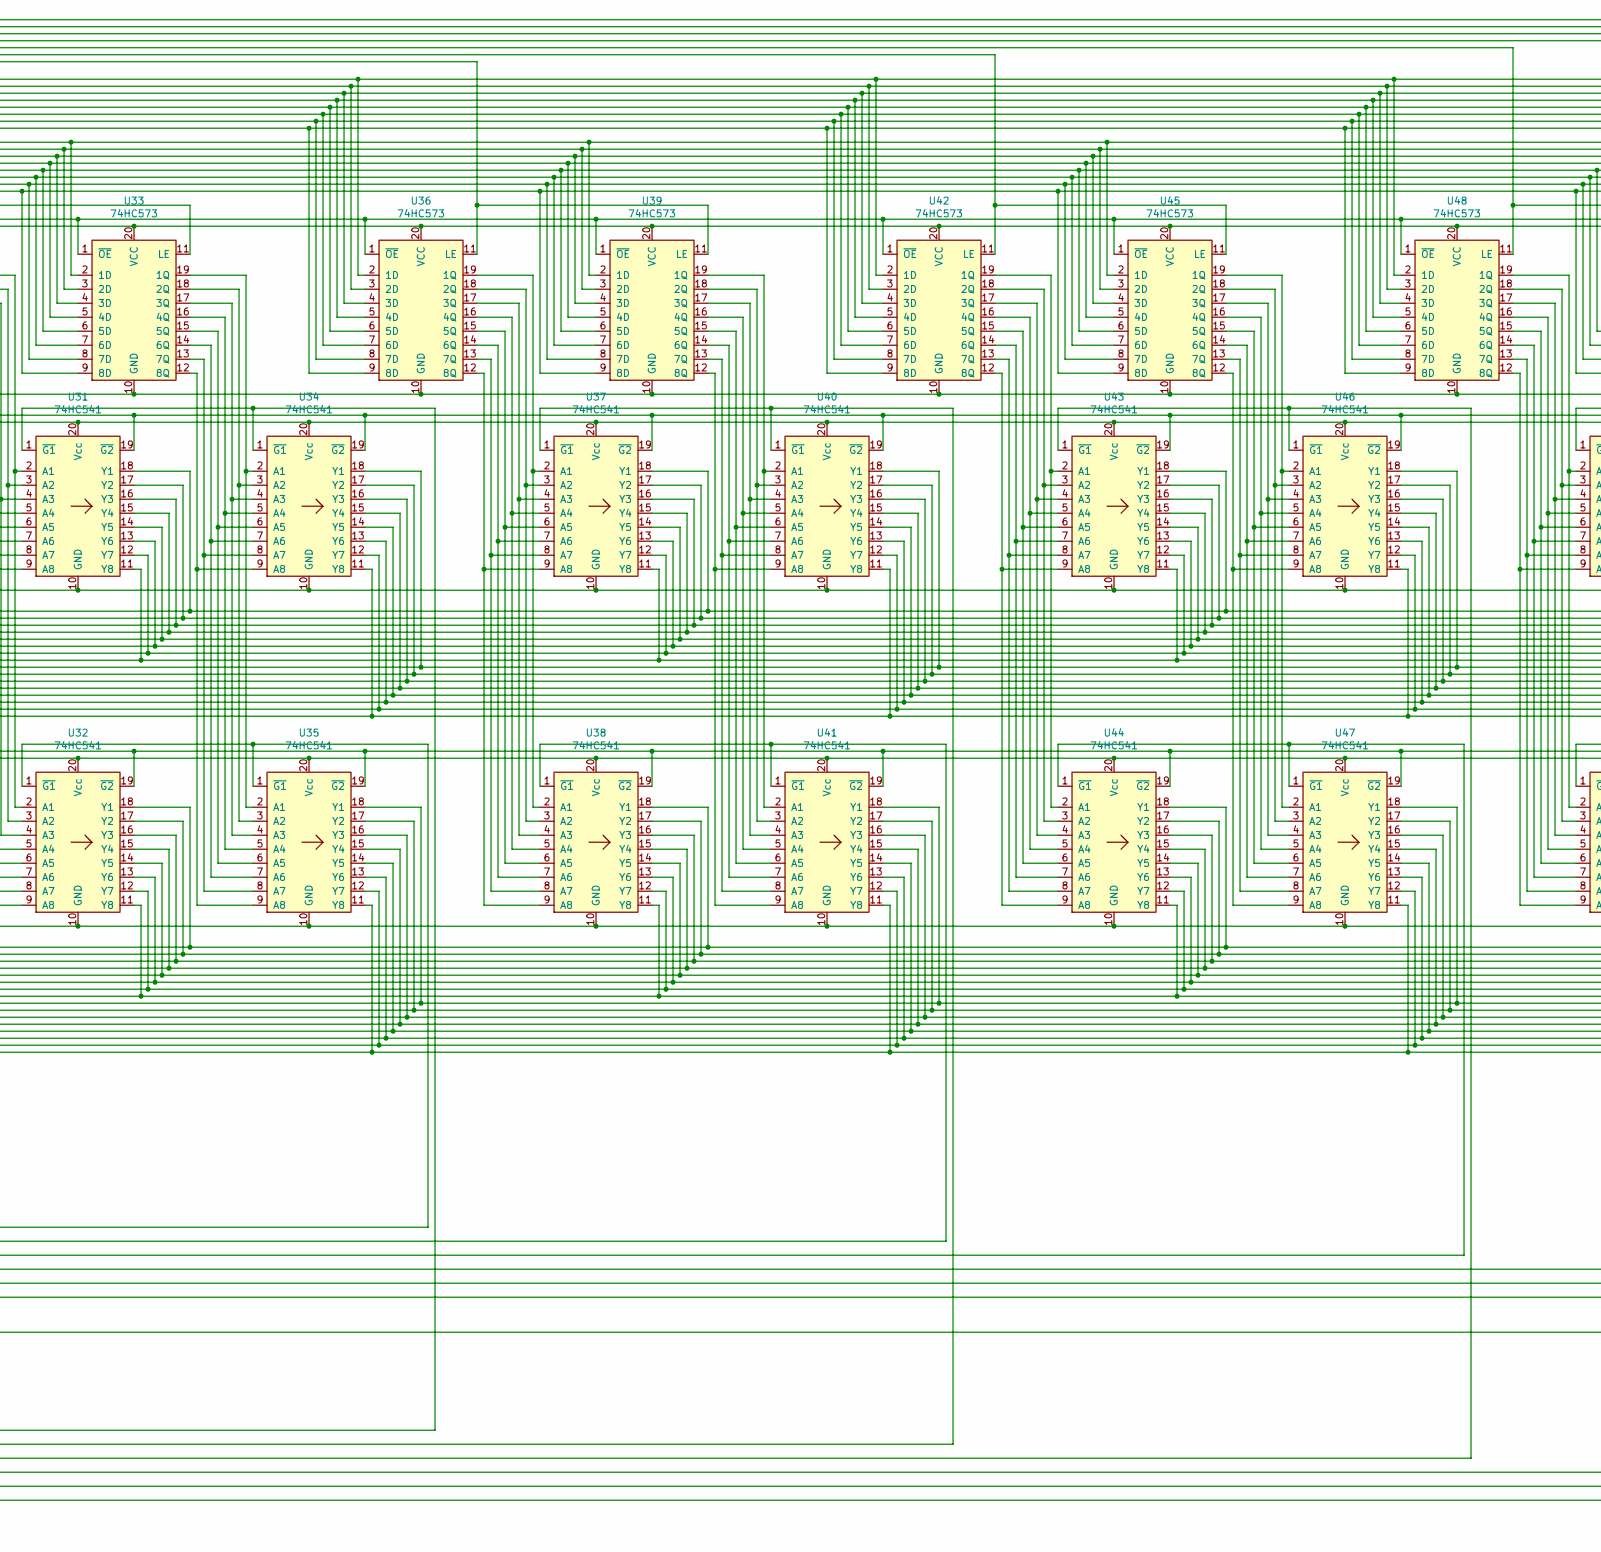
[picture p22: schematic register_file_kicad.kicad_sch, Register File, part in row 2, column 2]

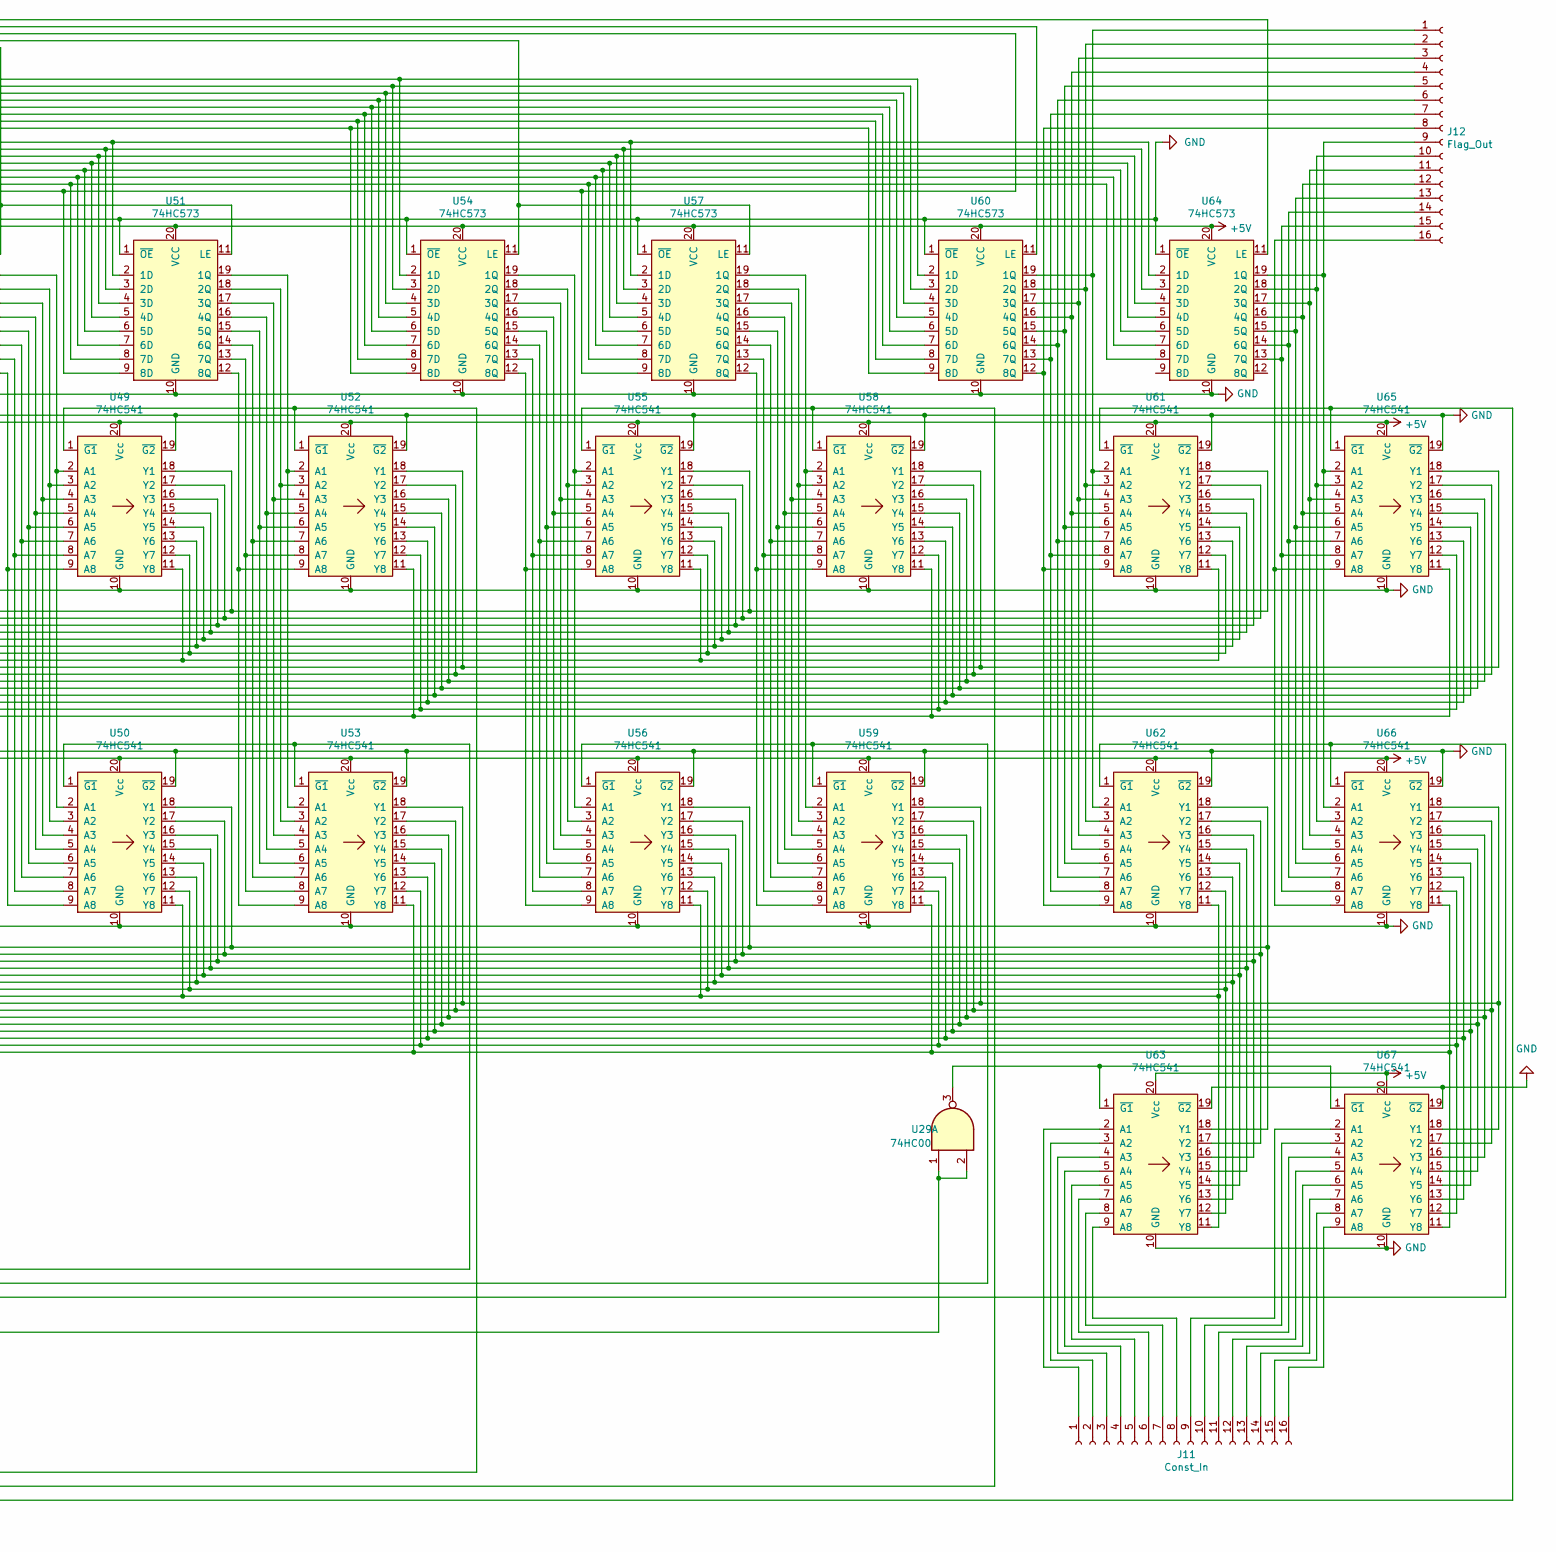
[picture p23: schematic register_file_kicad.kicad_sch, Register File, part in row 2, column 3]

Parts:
D1: LED; LED_D5.0mm
J1: A_Out; PinHeader_1x16_P2.54mm_Vertical
J2: B_Out; PinHeader_1x16_P2.54mm_Vertical
J3: D_Sel; PinSocket_1x03_P2.54mm_Horizontal
J4: AM-Connector; PinHeader_1x42_P2.54mm_Horizontal
J5: Conn_01x04_Female; PinHeader_1x04_P2.54mm_Horizontal
J6: Bus_Connector; PinHeader_1x78_P2.54mm_Horizontal
J7: B_Sel; PinHeader_1x03_P2.54mm_Horizontal
J8: A_Sel; PinHeader_1x03_P2.54mm_Horizontal
J9, J13: Conn_01x16_Female; PinSocket_1x16_P2.54mm_Vertical
J10: Conn_01x16_Male; PinSocket_1x16_P2.54mm_Vertical
J11: Const_In; PinHeader_1x16_P2.54mm_Horizontal
J12: Flag_Out; PinHeader_1x16_P2.54mm_Horizontal
J14: Conn_01x12_Male; PinSocket_1x12_P2.54mm_Vertical
J15: Conn_01x12_Female; PinSocket_1x12_P2.54mm_Vertical
J16, J17: Conn_01x01_Female; PinSocket_1x01_P2.54mm_Vertical
J18: Sup_Conn_main; PinSocket_1x03_P2.54mm_Horizontal
J19: Sup_Conn_Sec; PinSocket_1x03_P2.54mm_Horizontal
J20, J21: Conn_01x02_Female; PinSocket_1x02_P2.54mm_Vertical
R1, R2, R3, R4, R5, R6, R7: 220; R_Axial_DIN0309_L9.0mm_D3.2mm_P5.08mm_Vertical
U1: 74LS32; DIP-14_W7.62mm_Socket
U2, U3, U8: SRGB_Bar_2000; SRGB_2000
U4, U16, U17: 74HC137; DIP-16_W7.62mm_Socket
U5, U11, U19, U23: 74HC283; DIP-16_W7.62mm_Socket
U6: 74HC540; DIP-20_W7.62mm_Socket
U7, U12, U18, U22, U28, U33, U36, U39, U42, U45, U48, U51, U54, U57, U60, U64: 74HC573; DIP-20_W7.62mm_Socket
U9, U10: 74HC541; SO-20_5.3x12.6mm_P1.27mm
U13, U24, U27: 74LS08; DIP-14_W7.62mm_Socket
U14, U15, U20, U21, U25, U26, U31, U32, U34, U35, U37, U38, U40, U41, U43, U44, U46, U47, U49, U50, U52, U53, U55, U56, U58, U59, U61, U62, U63, U65, U66, U67: 74HC541; SO-20_12.8x7.5mm_P1.27mm
U29: 74HC00; DIP-14_W7.62mm_Socket
U30: 4027; DIP-16_W7.62mm_Socket
U68: 74LS00; DIP-14_W7.62mm_Socket

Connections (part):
+5V: J6.2 (Vcc), J14.10, J15.10, U1.14 (VCC), U4.6 (E2), U4.16 (VCC), U5.16 (Vcc), U6.20 (Vcc), U7.20 (VCC), U9.20 (Vcc), U10.20 (Vcc), U11.16 (Vcc), U12.20 (VCC), U13.14 (VCC), U14.20 (Vcc), U15.20 (Vcc), U16.6 (E2), U16.16 (VCC), U17.6 (E2), U17.16 (VCC), U18.20 (VCC), U19.16 (Vcc), U20.20 (Vcc), U21.20 (Vcc), U22.20 (VCC), U23.16 (Vcc), U24.14 (VCC), U25.20 (Vcc), U26.20 (Vcc), U27.14 (VCC), U28.20 (VCC), U29.14 (VCC), U30.16 (VDD), U31.20 (Vcc), U32.20 (Vcc), U33.20 (VCC), U34.20 (Vcc), U35.20 (Vcc), U36.20 (VCC), U37.20 (Vcc), U38.20 (Vcc), U39.20 (VCC), U40.20 (Vcc), U41.20 (Vcc), U42.20 (VCC), U43.20 (Vcc), U44.20 (Vcc), U45.20 (VCC), U46.20 (Vcc), U47.20 (Vcc), U48.20 (VCC), U49.20 (Vcc), U50.20 (Vcc), U51.20 (VCC), U52.20 (Vcc), U53.20 (Vcc), U54.20 (VCC), U55.20 (Vcc), U56.20 (Vcc), U57.20 (VCC), U58.20 (Vcc), U59.20 (Vcc), U60.20 (VCC), U61.20 (Vcc), U62.20 (Vcc), U63.20 (Vcc), U64.20 (VCC), U65.20 (Vcc), U66.20 (Vcc), U67.20 (Vcc), U68.14 (VCC)
/Const_Reg: J5.3, J16.1
/Dec: J5.1, U1.1, U5.3 (A2), U5.12 (A4), U5.14 (A3), U11.3 (A2), U11.5 (A1), U11.12 (A4), U11.14 (A3), U19.3 (A2), U19.5 (A1), U19.12 (A4), U19.14 (A3), U23.3 (A2), U23.5 (A1), U23.12 (A4), U23.14 (A3)
/Inc: J5.2, U1.2
/Zero_One: J5.4, J14.12
GND: J6.1 (GND), J14.11, J15.11, R1.1, R2.1, R3.1, R4.1, R5.1, R6.1, R7.1, U1.7 (GND), U4.4 (~LE), U4.5 (~E1), U4.8 (GND), U5.7 (C0), U5.8 (GND), U6.10 (GND), U7.1 (~OE), U7.10 (GND), U9.10 (GND), U9.19 (~G2), U10.10 (GND), U10.19 (~G2), U11.8 (GND), U12.1 (~OE), U12.10 (GND), U13.7 (GND), U14.10 (GND), U14.19 (~G2), U15.10 (GND), U15.19 (~G2), U16.4 (~LE), U16.8 (GND), U17.4 (~LE), U17.5 (~E1), U17.8 (GND), U18.1 (~OE), U18.10 (GND), U19.8 (GND), U20.10 (GND), U20.19 (~G2), U21.10 (GND), U21.19 (~G2), U22.1 (~OE), U22.10 (GND), U23.8 (GND), U24.7 (GND), U25.10 (GND), U25.19 (~G2), U26.10 (GND), U26.19 (~G2), U27.7 (GND), U28.1 (~OE), U28.10 (GND), U29.7 (GND), U30.3 (C), U30.5 (K), U30.6 (J), U30.8 (VSS), U31.10 (GND), U31.19 (~G2), U32.10 (GND), U32.19 (~G2), U33.1 (~OE), U33.10 (GND), U34.10 (GND), U34.19 (~G2), U35.10 (GND), U35.19 (~G2), U36.1 (~OE), U36.10 (GND), U37.10 (GND), U37.19 (~G2), U38.10 (GND), U38.19 (~G2), U39.1 (~OE), U39.10 (GND), U40.10 (GND), U40.19 (~G2), U41.10 (GND), U41.19 (~G2), U42.1 (~OE), U42.10 (GND), U43.10 (GND)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
unnamed: D1.1 (K), R7.2
unnamed: D1.2 (A), J14.9, J19.1, U27.2, U30.1 (Q)
unnamed: J1.1, U2.16, U9.18 (Y1), U20.18 (Y1), U31.18 (Y1), U37.18 (Y1), U43.18 (Y1), U49.18 (Y1), U55.18 (Y1), U61.18 (Y1)
unnamed: J1.2, U2.15, U9.17 (Y2), U20.17 (Y2), U31.17 (Y2), U37.17 (Y2), U43.17 (Y2), U49.17 (Y2), U55.17 (Y2), U61.17 (Y2)
unnamed: J1.3, U2.14, U9.16 (Y3), U20.16 (Y3), U31.16 (Y3), U37.16 (Y3), U43.16 (Y3), U49.16 (Y3), U55.16 (Y3), U61.16 (Y3)
unnamed: J1.4, U2.13, U9.15 (Y4), U20.15 (Y4), U31.15 (Y4), U37.15 (Y4), U43.15 (Y4), U49.15 (Y4), U55.15 (Y4), U61.15 (Y4)
unnamed: J1.5, U2.12, U9.14 (Y5), U20.14 (Y5), U31.14 (Y5), U37.14 (Y5), U43.14 (Y5), U49.14 (Y5), U55.14 (Y5), U61.14 (Y5)
unnamed: J1.6, U2.11, U9.13 (Y6), U20.13 (Y6), U31.13 (Y6), U37.13 (Y6), U43.13 (Y6), U49.13 (Y6), U55.13 (Y6), U61.13 (Y6)
unnamed: J1.7, U2.10, U9.12 (Y7), U20.12 (Y7), U31.12 (Y7), U37.12 (Y7), U43.12 (Y7), U49.12 (Y7), U55.12 (Y7), U61.12 (Y7)
unnamed: J1.8, U2.9, U9.11 (Y8), U20.11 (Y8), U31.11 (Y8), U37.11 (Y8), U43.11 (Y8), U49.11 (Y8), U55.11 (Y8), U61.11 (Y8)
unnamed: J1.9, U2.8, U14.18 (Y1), U25.18 (Y1), U34.18 (Y1), U40.18 (Y1), U46.18 (Y1), U52.18 (Y1), U58.18 (Y1), U65.18 (Y1)
unnamed: J1.10, U2.7, U14.17 (Y2), U25.17 (Y2), U34.17 (Y2), U40.17 (Y2), U46.17 (Y2), U52.17 (Y2), U58.17 (Y2), U65.17 (Y2)
unnamed: J1.11, U2.6, U14.16 (Y3), U25.16 (Y3), U34.16 (Y3), U40.16 (Y3), U46.16 (Y3), U52.16 (Y3), U58.16 (Y3), U65.16 (Y3)
unnamed: J1.12, U2.5, U14.15 (Y4), U25.15 (Y4), U34.15 (Y4), U40.15 (Y4), U46.15 (Y4), U52.15 (Y4), U58.15 (Y4), U65.15 (Y4)
unnamed: J1.13, U2.4, U14.14 (Y5), U25.14 (Y5), U34.14 (Y5), U40.14 (Y5), U46.14 (Y5), U52.14 (Y5), U58.14 (Y5), U65.14 (Y5)
unnamed: J1.14, U2.3, U14.13 (Y6), U25.13 (Y6), U34.13 (Y6), U40.13 (Y6), U46.13 (Y6), U52.13 (Y6), U58.13 (Y6), U65.13 (Y6)
unnamed: J1.15, U2.2, U14.12 (Y7), U25.12 (Y7), U34.12 (Y7), U40.12 (Y7), U46.12 (Y7), U52.12 (Y7), U58.12 (Y7), U65.12 (Y7)
unnamed: J1.16, U2.1, U14.11 (Y8), U25.11 (Y8), U34.11 (Y8), U40.11 (Y8), U46.11 (Y8), U52.11 (Y8), U58.11 (Y8), U65.11 (Y8)
unnamed: J2.1, U3.16, U10.18 (Y1), U21.18 (Y1), U32.18 (Y1), U38.18 (Y1), U44.18 (Y1), U50.18 (Y1), U56.18 (Y1), U62.18 (Y1), U63.18 (Y1)
unnamed: J2.2, U3.15, U10.17 (Y2), U21.17 (Y2), U32.17 (Y2), U38.17 (Y2), U44.17 (Y2), U50.17 (Y2), U56.17 (Y2), U62.17 (Y2), U63.17 (Y2)
unnamed: J2.3, U3.14, U10.16 (Y3), U21.16 (Y3), U32.16 (Y3), U38.16 (Y3), U44.16 (Y3), U50.16 (Y3), U56.16 (Y3), U62.16 (Y3), U63.16 (Y3)
unnamed: J2.4, U3.13, U10.15 (Y4), U21.15 (Y4), U32.15 (Y4), U38.15 (Y4), U44.15 (Y4), U50.15 (Y4), U56.15 (Y4), U62.15 (Y4), U63.15 (Y4)
unnamed: J2.5, U3.12, U10.14 (Y5), U21.14 (Y5), U32.14 (Y5), U38.14 (Y5), U44.14 (Y5), U50.14 (Y5), U56.14 (Y5), U62.14 (Y5), U63.14 (Y5)
unnamed: J2.6, U3.11, U10.13 (Y6), U21.13 (Y6), U32.13 (Y6), U38.13 (Y6), U44.13 (Y6), U50.13 (Y6), U56.13 (Y6), U62.13 (Y6), U63.13 (Y6)
unnamed: J2.7, U3.10, U10.12 (Y7), U21.12 (Y7), U32.12 (Y7), U38.12 (Y7), U44.12 (Y7), U50.12 (Y7), U56.12 (Y7), U62.12 (Y7), U63.12 (Y7)
unnamed: J2.8, U3.9, U10.11 (Y8), U21.11 (Y8), U32.11 (Y8), U38.11 (Y8), U44.11 (Y8), U50.11 (Y8), U56.11 (Y8), U62.11 (Y8), U63.11 (Y8)
unnamed: J2.9, U3.8, U15.18 (Y1), U26.18 (Y1), U35.18 (Y1), U41.18 (Y1), U47.18 (Y1), U53.18 (Y1), U59.18 (Y1), U66.18 (Y1), U67.18 (Y1)
unnamed: J2.10, U3.7, U15.17 (Y2), U26.17 (Y2), U35.17 (Y2), U41.17 (Y2), U47.17 (Y2), U53.17 (Y2), U59.17 (Y2), U66.17 (Y2), U67.17 (Y2)
unnamed: J2.11, U3.6, U15.16 (Y3), U26.16 (Y3), U35.16 (Y3), U41.16 (Y3), U47.16 (Y3), U53.16 (Y3), U59.16 (Y3), U66.16 (Y3), U67.16 (Y3)
unnamed: J2.12, U3.5, U15.15 (Y4), U26.15 (Y4), U35.15 (Y4), U41.15 (Y4), U47.15 (Y4), U53.15 (Y4), U59.15 (Y4), U66.15 (Y4), U67.15 (Y4)
unnamed: J2.13, U3.4, U15.14 (Y5), U26.14 (Y5), U35.14 (Y5), U41.14 (Y5), U47.14 (Y5), U53.14 (Y5), U59.14 (Y5), U66.14 (Y5), U67.14 (Y5)
unnamed: J2.14, U3.3, U15.13 (Y6), U26.13 (Y6), U35.13 (Y6), U41.13 (Y6), U47.13 (Y6), U53.13 (Y6), U59.13 (Y6), U66.13 (Y6), U67.13 (Y6)
unnamed: J2.15, U3.2, U15.12 (Y7), U26.12 (Y7), U35.12 (Y7), U41.12 (Y7), U47.12 (Y7), U53.12 (Y7), U59.12 (Y7), U66.12 (Y7), U67.12 (Y7)
unnamed: J2.16, U3.1, U15.11 (Y8), U26.11 (Y8), U35.11 (Y8), U41.11 (Y8), U47.11 (Y8), U53.11 (Y8), U59.11 (Y8), U66.11 (Y8), U67.11 (Y8)
unnamed: J3.1, U4.3 (A2)
unnamed: J3.2, U4.2 (A1)
unnamed: J3.3, U4.1 (A0)
unnamed: J4.11 (from_Bus0), U5.6 (B1), U8.16
unnamed: J4.12 (from_Bus1), U5.2 (B2), U8.15
unnamed: J4.13 (from_Bus2), U5.15 (B3), U8.14
unnamed: J4.14 (from_Bus3), U5.11 (B4), U8.13
unnamed: J4.15 (from_Bus4), U8.12, U11.6 (B1)
unnamed: J4.16 (from_Bus5), U8.11, U11.2 (B2)
unnamed: J4.17 (from_Bus6), U8.10, U11.15 (B3)
unnamed: J4.18 (from_Bus7), U8.9, U11.11 (B4)
unnamed: J4.19 (from_Bus8), U8.8, U19.6 (B1)
unnamed: J4.20 (from_Bus9), U8.7, U19.2 (B2)
unnamed: J4.21 (from_Bus10), U8.6, U19.15 (B3)
unnamed: J4.22 (from_Bus11), U8.5, U19.11 (B4)
unnamed: J4.23 (from_Bus12), U8.4, U23.6 (B1)
unnamed: J4.24 (from_Bus13), U8.3, U23.2 (B2)
unnamed: J4.25 (from_Bus14), U8.2, U23.15 (B3)
unnamed: J4.26 (from_Bus15), U8.1, U23.11 (B4)
unnamed: J6.3 (CLK_R), J20.1
unnamed: J6.4 (CLK_F), J20.2
unnamed: J7.1, U16.3 (A2)
unnamed: J7.2, U16.2 (A1)
unnamed: J7.3, U16.1 (A0)
unnamed: J8.1, U17.3 (A2)
unnamed: J8.2, U17.2 (A1)
unnamed: J8.3, U17.1 (A0)
unnamed: J9.1, U18.19 (1Q), U20.2 (A1), U21.2 (A1)
unnamed: J9.2, U18.18 (2Q), U20.3 (A2), U21.3 (A2)
unnamed: J9.3, U18.17 (3Q), U20.4 (A3), U21.4 (A3)
unnamed: J9.4, U18.16 (4Q), U20.5 (A4), U21.5 (A4)
unnamed: J9.5, U18.15 (5Q), U20.6 (A5), U21.6 (A5)
unnamed: J9.6, U18.14 (6Q), U20.7 (A6), U21.7 (A6)
unnamed: J9.7, U18.13 (7Q), U20.8 (A7), U21.8 (A7)
unnamed: J9.8, U18.12 (8Q), U20.9 (A8), U21.9 (A8)
unnamed: J9.9, U22.19 (1Q), U25.2 (A1), U26.2 (A1)
unnamed: J9.10, U22.18 (2Q), U25.3 (A2), U26.3 (A2)
unnamed: J9.11, U22.17 (3Q), U25.4 (A3), U26.4 (A3)
unnamed: J9.12, U22.16 (4Q), U25.5 (A4), U26.5 (A4)
unnamed: J9.13, U22.15 (5Q), U25.6 (A5), U26.6 (A5)
unnamed: J9.14, U22.14 (6Q), U25.7 (A6), U26.7 (A6)
unnamed: J9.15, U22.13 (7Q), U25.8 (A7), U26.8 (A7)
unnamed: J9.16, U22.12 (8Q), U25.9 (A8), U26.9 (A8)
unnamed: J10.1, U7.12 (8Q)
unnamed: J10.2, U7.13 (7Q)
unnamed: J10.3, U7.14 (6Q)
unnamed: J10.4, U7.15 (5Q)
unnamed: J10.5, U7.16 (4Q)
unnamed: J10.6, U7.17 (3Q)
unnamed: J10.7, U7.18 (2Q)
unnamed: J10.8, U7.19 (1Q)
unnamed: J10.9, U12.12 (8Q)
unnamed: J10.10, U12.13 (7Q)
unnamed: J10.11, U12.14 (6Q)
unnamed: J10.12, U12.15 (5Q)
unnamed: J10.13, U12.16 (4Q)
unnamed: J10.14, U12.17 (3Q)
unnamed: J10.15, U12.18 (2Q)
unnamed: J10.16, U12.19 (1Q)
unnamed: J11.1, U63.2 (A1)
unnamed: J11.2, U63.3 (A2)
unnamed: J11.3, U63.4 (A3)
unnamed: J11.4, U63.5 (A4)
unnamed: J11.5, U63.6 (A5)
unnamed: J11.6, U63.7 (A6)
unnamed: J11.7, U63.8 (A7)
unnamed: J11.8, U63.9 (A8)
unnamed: J11.9, U67.2 (A1)
unnamed: J11.10, U67.3 (A2)
unnamed: J11.11, U67.4 (A3)
unnamed: J11.12, U67.5 (A4)
unnamed: J11.13, U67.6 (A5)
unnamed: J11.14, U67.7 (A6)
unnamed: J11.15, U67.8 (A7)
unnamed: J11.16, U67.9 (A8)
unnamed: J12.1, U60.19 (1Q), U61.2 (A1), U62.2 (A1)
unnamed: J12.2, U60.18 (2Q), U61.3 (A2), U62.3 (A2)
unnamed: J12.3, U60.17 (3Q), U61.4 (A3), U62.4 (A3)
unnamed: J12.4, U60.16 (4Q), U61.5 (A4), U62.5 (A4)
unnamed: J12.5, U60.15 (5Q), U61.6 (A5), U62.6 (A5)
unnamed: J12.6, U60.14 (6Q), U61.7 (A6), U62.7 (A6)
unnamed: J12.7, U60.13 (7Q), U61.8 (A7), U62.8 (A7)
unnamed: J12.8, U60.12 (8Q), U61.9 (A8), U62.9 (A8)
unnamed: J12.9, U64.19 (1Q), U65.2 (A1), U66.2 (A1)
unnamed: J12.10, U64.18 (2Q), U65.3 (A2), U66.3 (A2)
unnamed: J12.11, U64.17 (3Q), U65.4 (A3), U66.4 (A3)
unnamed: J12.12, U64.16 (4Q), U65.5 (A4), U66.5 (A4)
unnamed: J12.13, U64.15 (5Q), U65.6 (A5), U66.6 (A5)
unnamed: J12.14, U64.14 (6Q), U65.7 (A6), U66.7 (A6)
unnamed: J12.15, U64.13 (7Q), U65.8 (A7), U66.8 (A7)
unnamed: J12.16, U65.9 (A8), U66.9 (A8)
unnamed: J13.1, J15.7, U22.9 (8D), U33.9 (8D), U39.9 (8D), U45.9 (8D), U51.9 (8D), U57.9 (8D)
unnamed: J13.2, U22.8 (7D), U33.8 (7D), U39.8 (7D), U45.8 (7D), U51.8 (7D), U57.8 (7D), U64.8 (7D)
unnamed: J13.3, U22.7 (6D), U33.7 (6D), U39.7 (6D), U45.7 (6D), U51.7 (6D), U57.7 (6D), U64.7 (6D)
unnamed: J13.4, U22.6 (5D), U33.6 (5D), U39.6 (5D), U45.6 (5D), U51.6 (5D), U57.6 (5D), U64.6 (5D)
unnamed: J13.5, U22.5 (4D), U33.5 (4D), U39.5 (4D), U45.5 (4D), U51.5 (4D), U57.5 (4D), U64.5 (4D)
unnamed: J13.6, U22.4 (3D), U33.4 (3D), U39.4 (3D), U45.4 (3D), U51.4 (3D), U57.4 (3D), U64.4 (3D)
unnamed: J13.7, U22.3 (2D), U33.3 (2D), U39.3 (2D), U45.3 (2D), U51.3 (2D), U57.3 (2D), U64.3 (2D)
unnamed: J13.8, U22.2 (1D), U33.2 (1D), U39.2 (1D), U45.2 (1D), U51.2 (1D), U57.2 (1D), U64.2 (1D)
unnamed: J13.9, U18.9 (8D), U28.9 (8D), U36.9 (8D), U42.9 (8D), U48.9 (8D), U54.9 (8D), U60.9 (8D)
unnamed: J13.10, U18.8 (7D), U28.8 (7D), U36.8 (7D), U42.8 (7D), U48.8 (7D), U54.8 (7D), U60.8 (7D)
unnamed: J13.11, U18.7 (6D), U28.7 (6D), U36.7 (6D), U42.7 (6D), U48.7 (6D), U54.7 (6D), U60.7 (6D)
unnamed: J13.12, U18.6 (5D), U28.6 (5D), U36.6 (5D), U42.6 (5D), U48.6 (5D), U54.6 (5D), U60.6 (5D)
unnamed: J13.13, U18.5 (4D), U28.5 (4D), U36.5 (4D), U42.5 (4D), U48.5 (4D), U54.5 (4D), U60.5 (4D)
unnamed: J13.14, U18.4 (3D), U28.4 (3D), U36.4 (3D), U42.4 (3D), U48.4 (3D), U54.4 (3D), U60.4 (3D)
unnamed: J13.15, U18.3 (2D), U28.3 (2D), U36.3 (2D), U42.3 (2D), U48.3 (2D), U54.3 (2D), U60.3 (2D)
unnamed: J13.16, U18.2 (1D), U28.2 (1D), U36.2 (1D), U42.2 (1D), U48.2 (1D), U54.2 (1D), U60.2 (1D)
unnamed: J14.1, U13.8
unnamed: J14.2, U13.11
unnamed: J14.3, U24.3
unnamed: J14.4, U24.6
unnamed: J14.5, U24.8
unnamed: J14.6, U24.11
unnamed: J14.7, U27.9, U68.1, U68.2
unnamed: J14.8, U27.1, U27.11
unnamed: J15.1, U18.11 (LE), U22.11 (LE)
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

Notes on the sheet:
FLAG
ZERO

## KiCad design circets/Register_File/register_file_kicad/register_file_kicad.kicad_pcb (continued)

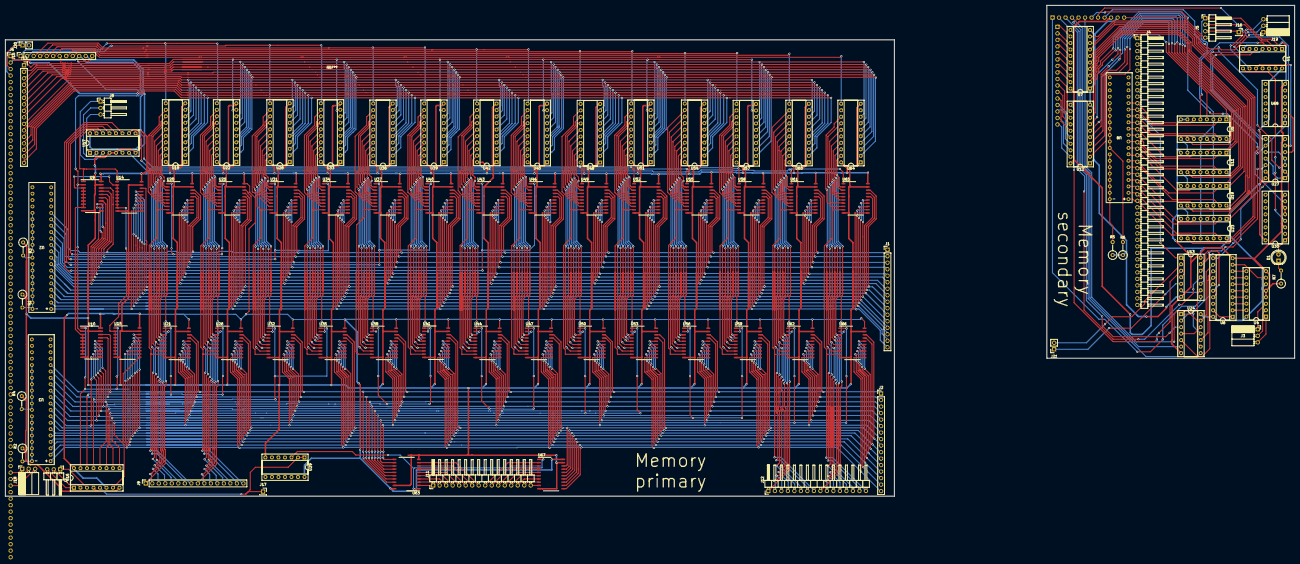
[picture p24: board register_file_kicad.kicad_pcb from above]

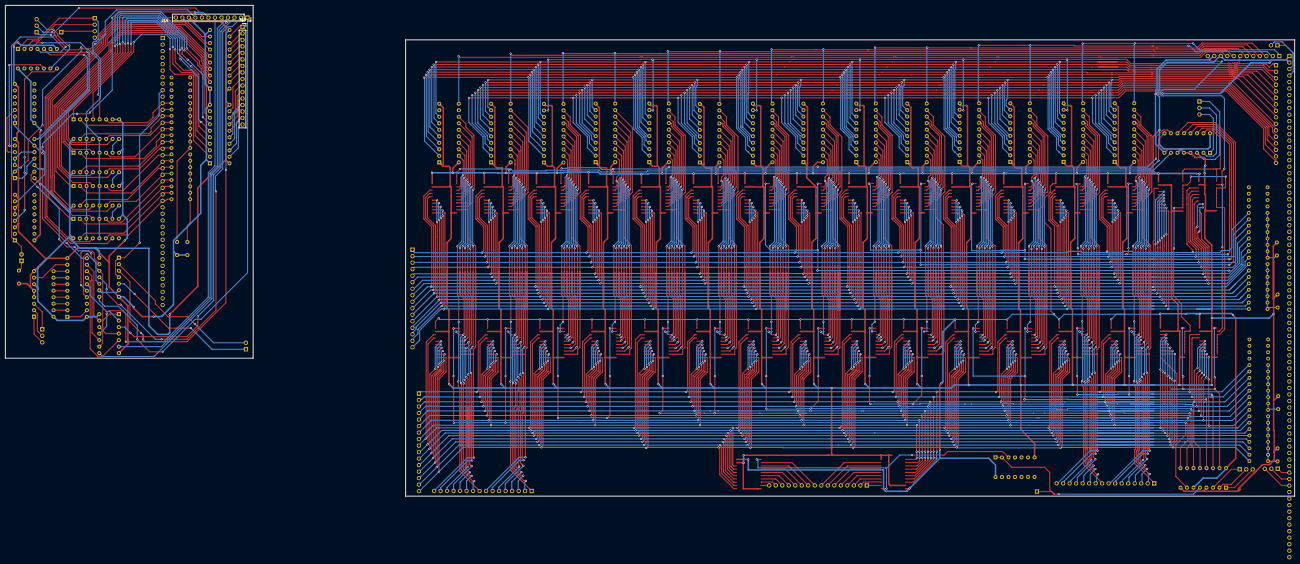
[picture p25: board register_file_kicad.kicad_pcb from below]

Board: 2 copper layers, 503.1 x 191.5 mm, 97 parts (2 on the bottom side), 321 nets.

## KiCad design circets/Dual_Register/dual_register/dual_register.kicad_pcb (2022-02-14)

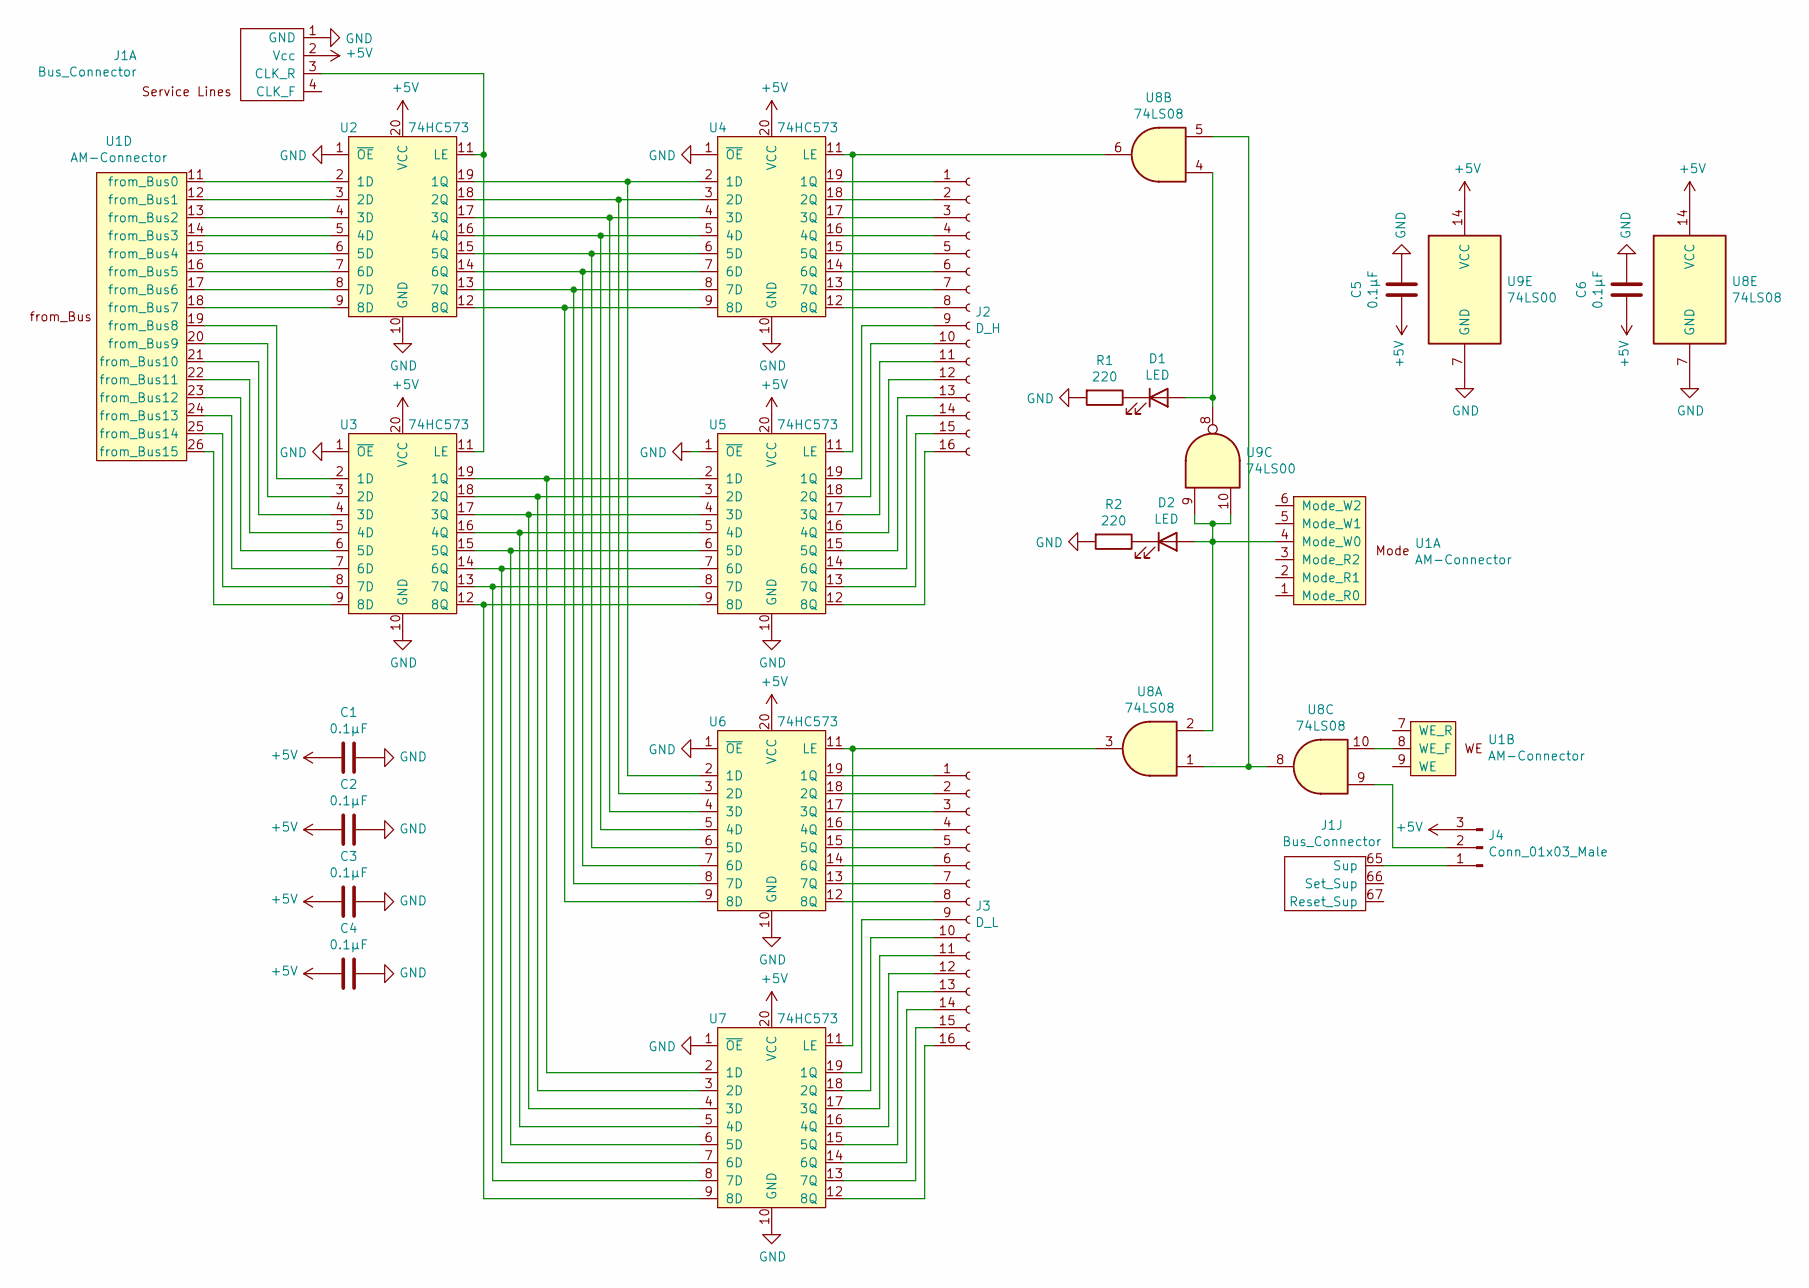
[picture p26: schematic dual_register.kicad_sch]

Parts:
C1, C2, C3, C4, C5, C6: 0.1µF; C_Disc_D8.0mm_W5.0mm_P5.00mm
D1, D2: LED; LED_D5.0mm
J1: Bus_Connector; PinHeader_1x78_P2.54mm_Horizontal
J2: D_H; PinHeader_1x16_P2.00mm_Vertical
J3: D_L; PinHeader_1x16_P2.00mm_Vertical
J4: Conn_01x03_Male; PinSocket_1x03_P2.00mm_Vertical
R1, R2: 220; R_Axial_DIN0309_L9.0mm_D3.2mm_P2.54mm_Vertical
U1: AM-Connector; PinHeader_1x42_P2.54mm_Horizontal
U2, U3, U4, U5, U6, U7: 74HC573; DIP-20_W7.62mm_Socket
U8: 74LS08; DIP-14_W7.62mm_Socket
U9: 74LS00; DIP-14_W7.62mm_Socket

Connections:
+5V: C1.2, C2.2, C3.2, C4.2, C5.2, C6.2, J1.2 (Vcc), J4.3, U2.20 (VCC), U3.20 (VCC), U4.20 (VCC), U5.20 (VCC), U6.20 (VCC), U7.20 (VCC), U8.14 (VCC), U9.14 (VCC)
GND: C1.1, C2.1, C3.1, C4.1, C5.1, C6.1, J1.1 (GND), R1.2, R2.2, U2.1 (~OE), U2.10 (GND), U3.1 (~OE), U3.10 (GND), U4.1 (~OE), U4.10 (GND), U5.1 (~OE), U5.10 (GND), U6.1 (~OE), U6.10 (GND), U7.1 (~OE), U7.10 (GND), U8.7 (GND), U9.7 (GND)
unnamed: D1.1 (K), R1.1
unnamed: D1.2 (A), U8.4, U9.8
unnamed: D2.1 (K), R2.1
unnamed: D2.2 (A), U1.4 (Mode_W0), U8.2, U9.9, U9.10
unnamed: J1.3 (CLK_R), U2.11 (LE), U3.11 (LE)
unnamed: J1.65 (Sup), J4.1
unnamed: J2.1, U4.19 (1Q)
unnamed: J2.2, U4.18 (2Q)
unnamed: J2.3, U4.17 (3Q)
unnamed: J2.4, U4.16 (4Q)
unnamed: J2.5, U4.15 (5Q)
unnamed: J2.6, U4.14 (6Q)
unnamed: J2.7, U4.13 (7Q)
unnamed: J2.8, U4.12 (8Q)
unnamed: J2.9, U5.19 (1Q)
unnamed: J2.10, U5.18 (2Q)
unnamed: J2.11, U5.17 (3Q)
unnamed: J2.12, U5.16 (4Q)
unnamed: J2.13, U5.15 (5Q)
unnamed: J2.14, U5.14 (6Q)
unnamed: J2.15, U5.13 (7Q)
unnamed: J2.16, U5.12 (8Q)
unnamed: J3.1, U6.19 (1Q)
unnamed: J3.2, U6.18 (2Q)
unnamed: J3.3, U6.17 (3Q)
unnamed: J3.4, U6.16 (4Q)
unnamed: J3.5, U6.15 (5Q)
unnamed: J3.6, U6.14 (6Q)
unnamed: J3.7, U6.13 (7Q)
unnamed: J3.8, U6.12 (8Q)
unnamed: J3.9, U7.19 (1Q)
unnamed: J3.10, U7.18 (2Q)
unnamed: J3.11, U7.17 (3Q)
unnamed: J3.12, U7.16 (4Q)
unnamed: J3.13, U7.15 (5Q)
unnamed: J3.14, U7.14 (6Q)
unnamed: J3.15, U7.13 (7Q)
unnamed: J3.16, U7.12 (8Q)
unnamed: J4.2, U8.9
unnamed: U1.8 (WE_F), U8.10
unnamed: U1.11 (from_Bus0), U2.2 (1D)
unnamed: U1.12 (from_Bus1), U2.3 (2D)
unnamed: U1.13 (from_Bus2), U2.4 (3D)
unnamed: U1.14 (from_Bus3), U2.5 (4D)
unnamed: U1.15 (from_Bus4), U2.6 (5D)
unnamed: U1.16 (from_Bus5), U2.7 (6D)
unnamed: U1.17 (from_Bus6), U2.8 (7D)
unnamed: U1.18 (from_Bus7), U2.9 (8D)
unnamed: U1.19 (from_Bus8), U3.2 (1D)
unnamed: U1.20 (from_Bus9), U3.3 (2D)
unnamed: U1.21 (from_Bus10), U3.4 (3D)
unnamed: U1.22 (from_Bus11), U3.5 (4D)
unnamed: U1.23 (from_Bus12), U3.6 (5D)
unnamed: U1.24 (from_Bus13), U3.7 (6D)
unnamed: U1.25 (from_Bus14), U3.8 (7D)
unnamed: U1.26 (from_Bus15), U3.9 (8D)
unnamed: U2.12 (8Q), U4.9 (8D), U6.9 (8D)
unnamed: U2.13 (7Q), U4.8 (7D), U6.8 (7D)
unnamed: U2.14 (6Q), U4.7 (6D), U6.7 (6D)
unnamed: U2.15 (5Q), U4.6 (5D), U6.6 (5D)
unnamed: U2.16 (4Q), U4.5 (4D), U6.5 (4D)
unnamed: U2.17 (3Q), U4.4 (3D), U6.4 (3D)
unnamed: U2.18 (2Q), U4.3 (2D), U6.3 (2D)
unnamed: U2.19 (1Q), U4.2 (1D), U6.2 (1D)
unnamed: U3.12 (8Q), U5.9 (8D), U7.9 (8D)
unnamed: U3.13 (7Q), U5.8 (7D), U7.8 (7D)
unnamed: U3.14 (6Q), U5.7 (6D), U7.7 (6D)
unnamed: U3.15 (5Q), U5.6 (5D), U7.6 (5D)
unnamed: U3.16 (4Q), U5.5 (4D), U7.5 (4D)
unnamed: U3.17 (3Q), U5.4 (3D), U7.4 (3D)
unnamed: U3.18 (2Q), U5.3 (2D), U7.3 (2D)
unnamed: U3.19 (1Q), U5.2 (1D), U7.2 (1D)
unnamed: U4.11 (LE), U5.11 (LE), U8.6
unnamed: U6.11 (LE), U7.11 (LE), U8.3
unnamed: U8.1, U8.5, U8.8

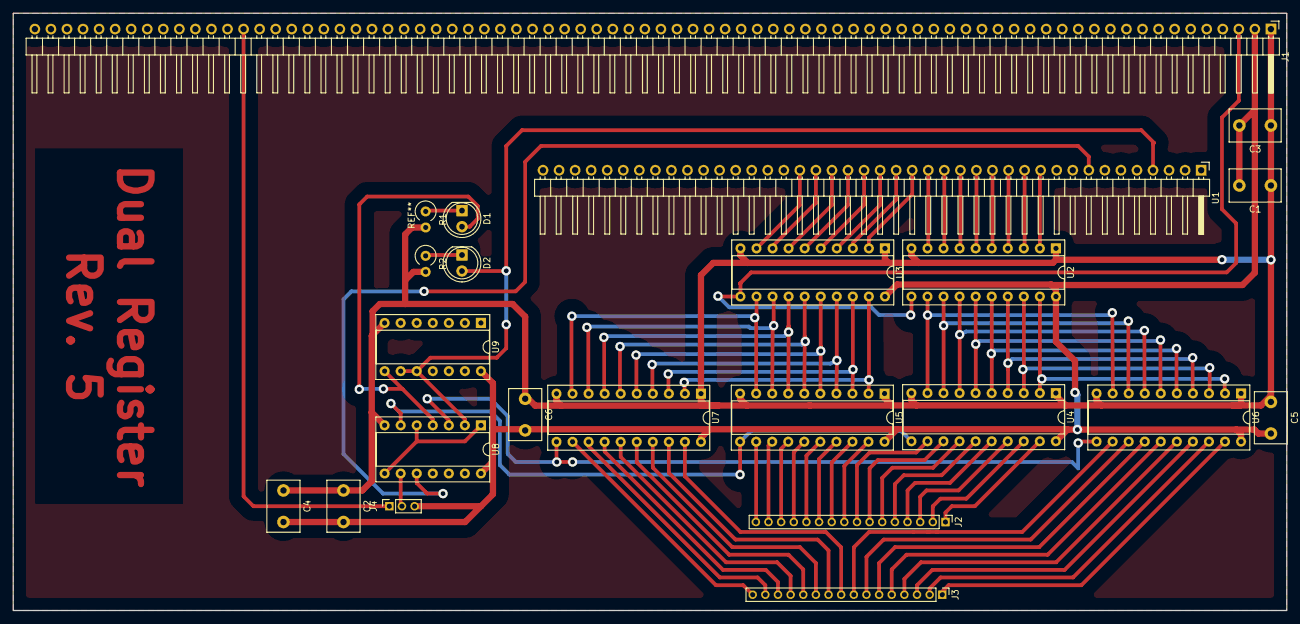
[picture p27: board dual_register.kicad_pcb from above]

Board: 2 copper layers, 201.5 x 94.5 mm, 23 parts (0 on the bottom side), 77 nets.

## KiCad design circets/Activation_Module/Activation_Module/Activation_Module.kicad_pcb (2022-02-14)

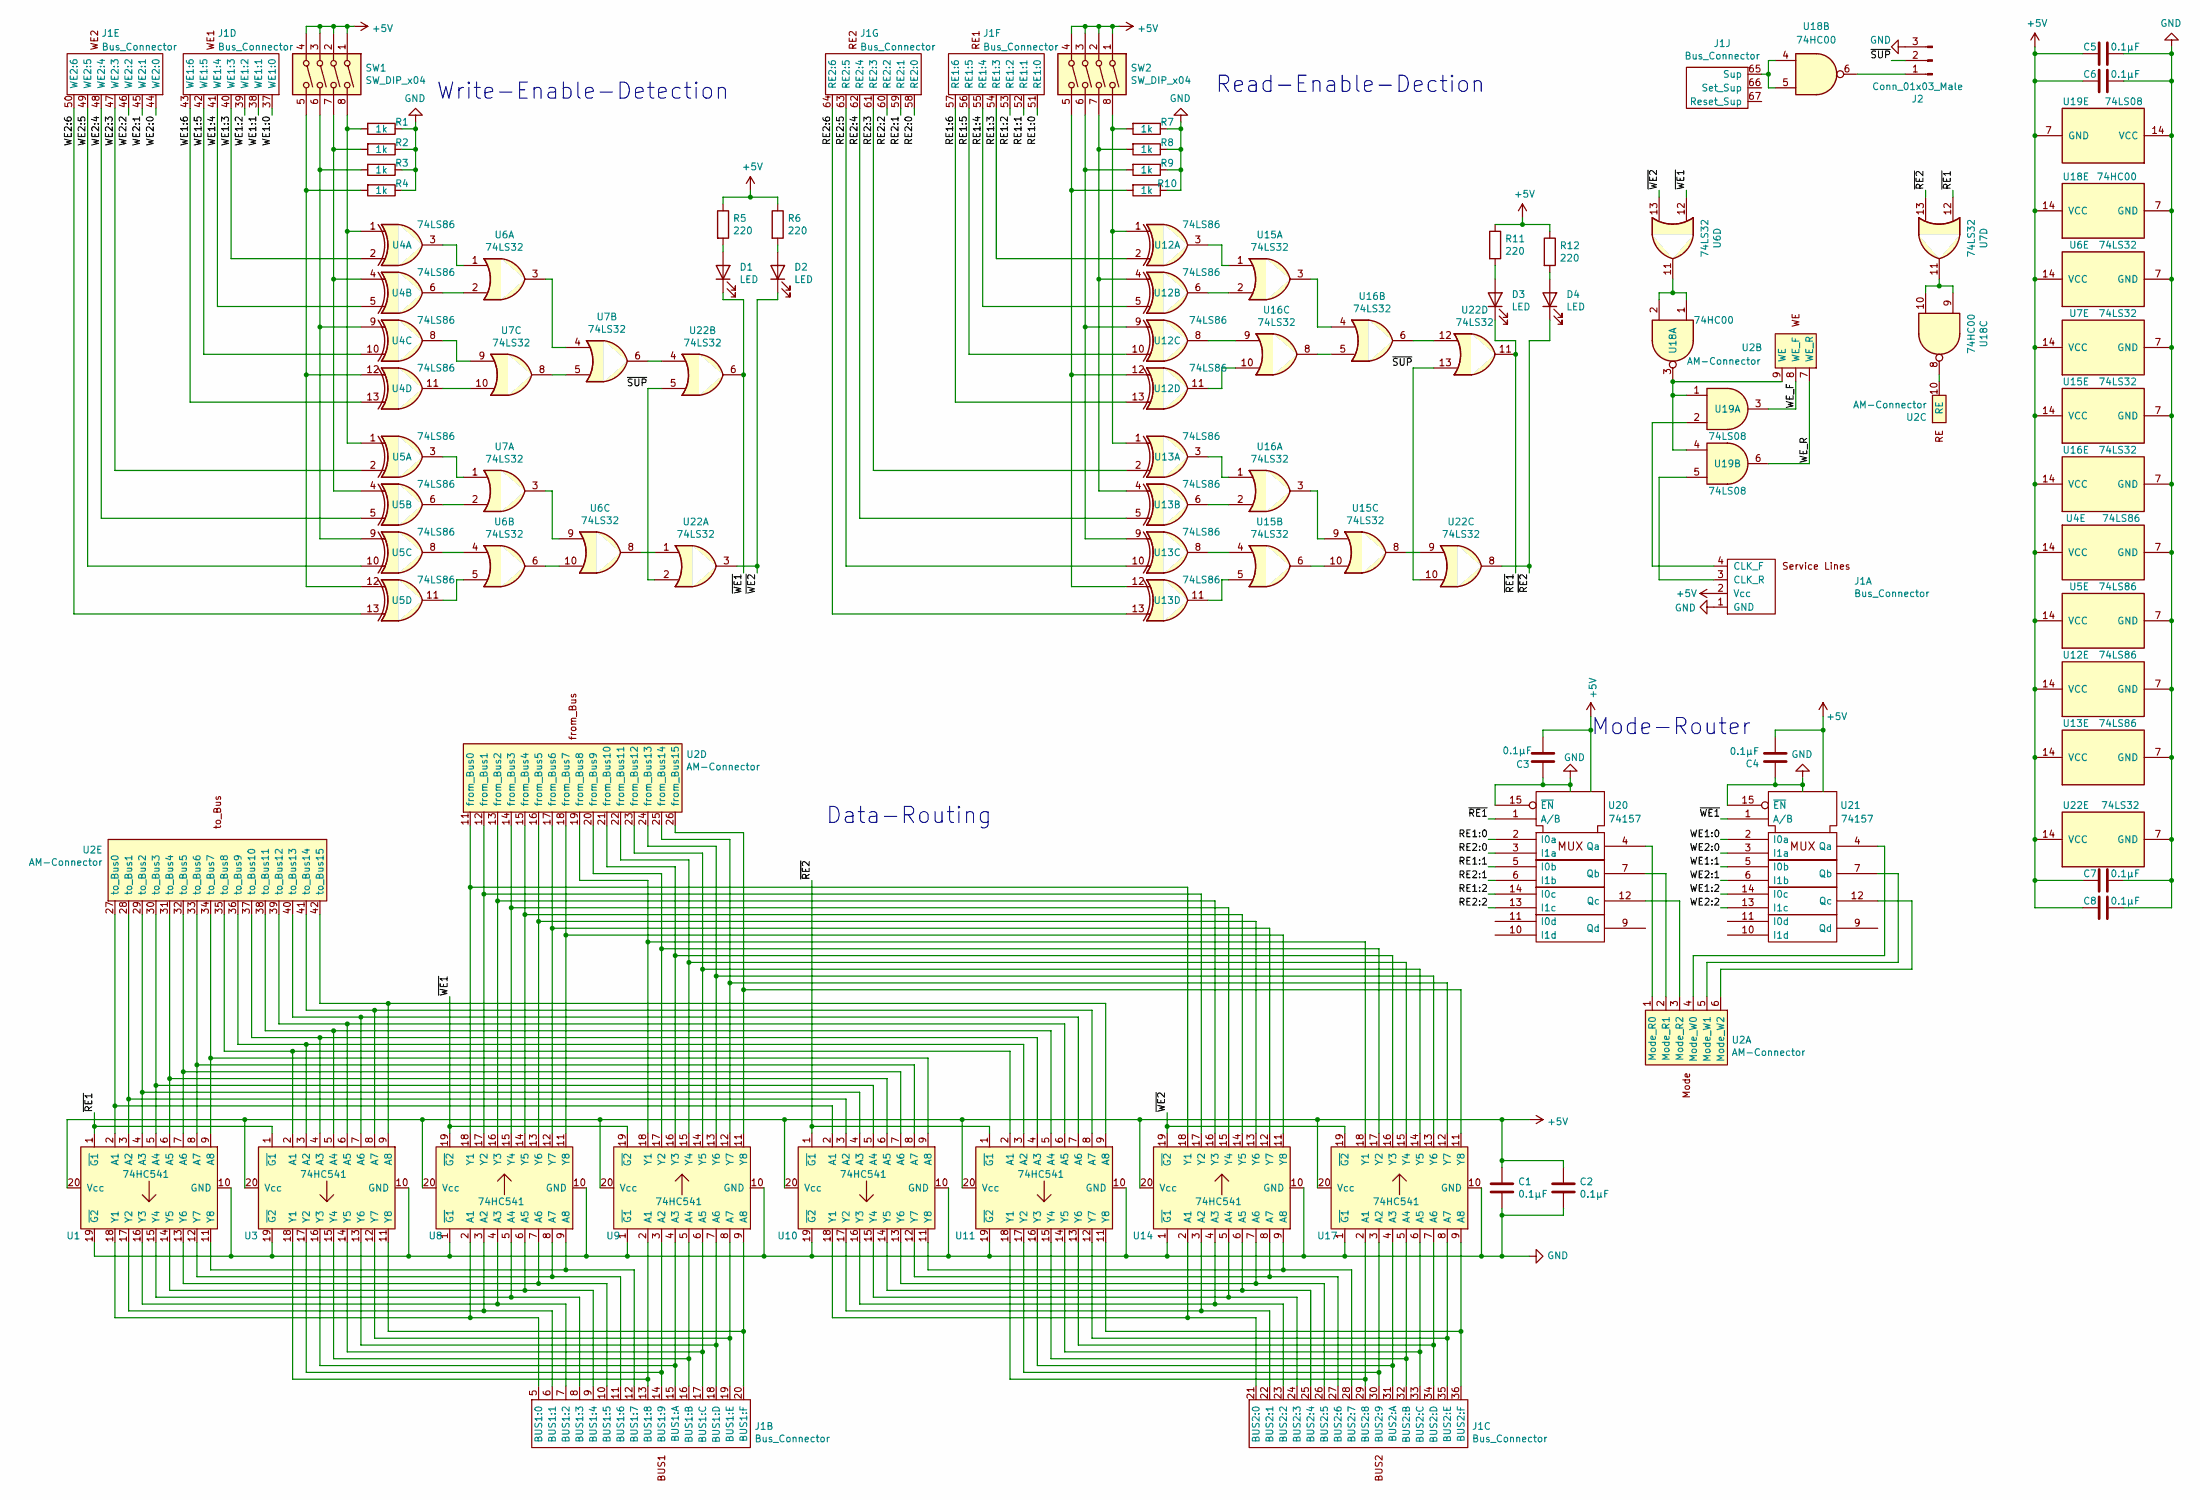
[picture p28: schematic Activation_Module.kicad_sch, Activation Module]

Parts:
C1, C2, C3, C4, C5, C6, C7, C8: 0.1µF; C_Disc_D6.0mm_W2.5mm_P5.00mm
D1, D2, D3, D4: LED; LED_D4.0mm
J1: Bus_Connector; PinHeader_1x78_P2.54mm_Horizontal
J2: Conn_01x03_Male; PinSocket_1x03_P2.00mm_Vertical
R1, R2, R3, R4, R7, R8, R9, R10: 1k; R_Axial_DIN0207_L6.3mm_D2.5mm_P2.54mm_Vertical
R5, R6, R11, R12: 220; R_Axial_DIN0207_L6.3mm_D2.5mm_P2.54mm_Vertical
SW1, SW2: SW_DIP_x04; SW_DIP_SPSTx04_Slide_9.78x12.34mm_W7.62mm_P2.54mm
U1, U3, U8, U9, U10, U11, U14, U17: 74HC541; SO-20_12.8x7.5mm_P1.27mm
U2: AM-Connector; PinSocket_1x42_P2.00mm_Horizontal
U4, U5, U12, U13: 74LS86; DIP-14_W7.62mm_Socket
U6, U7, U15, U16, U22: 74LS32; DIP-14_W7.62mm_Socket
U18: 74HC00; DIP-14_W7.62mm_Socket
U19: 74LS08; DIP-14_W7.62mm_Socket
U20, U21: 74157; DIP-16_W7.62mm_Socket

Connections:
+5V: C1.1, C2.1, C3.1, C4.2, C5.2, C6.2, C7.2, C8.2, J1.2 (Vcc), R5.1, R6.1, R11.1, R12.1, SW1.1, SW1.2, SW1.3, SW1.4, SW2.1, SW2.2, SW2.3, SW2.4, U1.20 (Vcc), U3.20 (Vcc), U4.14 (VCC), U5.14 (VCC), U6.14 (VCC), U7.14 (VCC), U8.20 (Vcc), U9.20 (Vcc), U10.20 (Vcc), U11.20 (Vcc), U12.14 (VCC), U13.14 (VCC), U14.20 (Vcc), U15.14 (VCC), U16.14 (VCC), U17.20 (Vcc), U18.14 (VCC), U19.7 (GND), U20.16 (VCC), U21.16 (VCC), U22.14 (VCC)
/RE1:0: J1.51 (RE1:0), U20.2 (I0a)
/RE1:1: J1.52 (RE1:1), U20.5 (I0b)
/RE1:2: J1.53 (RE1:2), U20.14 (I0c)
/RE1:3: J1.54 (RE1:3), U12.2
/RE1:4: J1.55 (RE1:4), U12.5
/RE1:5: J1.56 (RE1:5), U12.10
/RE1:6: J1.57 (RE1:6), U12.13
/RE2:0: J1.58 (RE2:0), U20.3 (I1a)
/RE2:1: J1.59 (RE2:1), U20.6 (I1b)
/RE2:2: J1.60 (RE2:2), U20.13 (I1c)
/RE2:3: J1.61 (RE2:3), U13.2
/RE2:4: J1.62 (RE2:4), U13.5
/RE2:5: J1.63 (RE2:5), U13.10
/RE2:6: J1.64 (RE2:6), U13.13
/WE1:0: J1.37 (WE1:0), U21.2 (I0a)
/WE1:1: J1.38 (WE1:1), U21.5 (I0b)
/WE1:2: J1.39 (WE1:2), U21.14 (I0c)
/WE1:3: J1.40 (WE1:3), U4.2
/WE1:4: J1.41 (WE1:4), U4.5
/WE1:5: J1.42 (WE1:5), U4.10
/WE1:6: J1.43 (WE1:6), U4.13
/WE2:0: J1.44 (WE2:0), U21.3 (I1a)
/WE2:1: J1.45 (WE2:1), U21.6 (I1b)
/WE2:2: J1.46 (WE2:2), U21.13 (I1c)
/WE2:3: J1.47 (WE2:3), U5.2
/WE2:4: J1.48 (WE2:4), U5.5
/WE2:5: J1.49 (WE2:5), U5.10
/WE2:6: J1.50 (WE2:6), U5.13
/WE_F: U2.8 (WE_F), U19.3
/WE_R: U2.7 (WE_R), U19.6
/~RE1: D3.1 (K), U1.1 (~G1), U3.1 (~G1), U7.12, U20.1 (A/B), U22.11
/~RE2: D4.1 (K), U7.13, U10.1 (~G1), U11.1 (~G1), U22.8
/~SUP: J2.2, U22.2, U22.5, U22.10, U22.13
/~WE1: D1.1 (K), U6.12, U8.19 (~G2), U9.19 (~G2), U21.1 (A/B), U22.6
/~WE2: D2.1 (K), U6.13, U14.19 (~G2), U17.19 (~G2), U22.3
GND: C1.2, C2.2, C3.2, C4.1, C5.1, C6.1, C7.1, C8.1, J1.1 (GND), J2.3, R1.1, R2.1, R3.1, R4.1, R7.1, R8.1, R9.1, R10.1, U1.10 (GND), U1.19 (~G2), U3.10 (GND), U3.19 (~G2), U4.7 (GND), U5.7 (GND), U6.7 (GND), U7.7 (GND), U8.1 (~G1), U8.10 (GND), U9.1 (~G1), U9.10 (GND), U10.10 (GND), U10.19 (~G2), U11.10 (GND), U11.19 (~G2), U12.7 (GND), U13.7 (GND), U14.1 (~G1), U14.10 (GND), U15.7 (GND), U16.7 (GND), U17.1 (~G1), U17.10 (GND), U18.7 (GND), U19.14 (VCC), U20.8 (GND), U20.15 (~EN), U21.8 (GND), U21.15 (~EN), U22.7 (GND)
unnamed: D1.2 (A), R5.2
unnamed: D2.2 (A), R6.2
unnamed: D3.2 (A), R11.2
unnamed: D4.2 (A), R12.2
unnamed: J1.3 (CLK_R), U19.5
unnamed: J1.4 (CLK_F), U19.2
unnamed: J1.5 (BUS1:0), U1.18 (Y1), U8.2 (A1)
unnamed: J1.6 (BUS1:1), U1.17 (Y2), U8.3 (A2)
unnamed: J1.7 (BUS1:2), U1.16 (Y3), U8.4 (A3)
unnamed: J1.8 (BUS1:3), U1.15 (Y4), U8.5 (A4)
unnamed: J1.9 (BUS1:4), U1.14 (Y5), U8.6 (A5)
unnamed: J1.10 (BUS1:5), U1.13 (Y6), U8.7 (A6)
unnamed: J1.11 (BUS1:6), U1.12 (Y7), U8.8 (A7)
unnamed: J1.12 (BUS1:7), U1.11 (Y8), U8.9 (A8)
unnamed: J1.13 (BUS1:8), U3.18 (Y1), U9.2 (A1)
unnamed: J1.14 (BUS1:9), U3.17 (Y2), U9.3 (A2)
unnamed: J1.15 (BUS1:A), U3.16 (Y3), U9.4 (A3)
unnamed: J1.16 (BUS1:B), U3.15 (Y4), U9.5 (A4)
unnamed: J1.17 (BUS1:C), U3.14 (Y5), U9.6 (A5)
unnamed: J1.18 (BUS1:D), U3.13 (Y6), U9.7 (A6)
unnamed: J1.19 (BUS1:E), U3.12 (Y7), U9.8 (A7)
unnamed: J1.20 (BUS1:F), U3.11 (Y8), U9.9 (A8)
unnamed: J1.21 (BUS2:0), U10.18 (Y1), U14.2 (A1)
unnamed: J1.22 (BUS2:1), U10.17 (Y2), U14.3 (A2)
unnamed: J1.23 (BUS2:2), U10.16 (Y3), U14.4 (A3)
unnamed: J1.24 (BUS2:3), U10.15 (Y4), U14.5 (A4)
unnamed: J1.25 (BUS2:4), U10.14 (Y5), U14.6 (A5)
unnamed: J1.26 (BUS2:5), U10.13 (Y6), U14.7 (A6)
unnamed: J1.27 (BUS2:6), U10.12 (Y7), U14.8 (A7)
unnamed: J1.28 (BUS2:7), U10.11 (Y8), U14.9 (A8)
unnamed: J1.29 (BUS2:8), U11.18 (Y1), U17.2 (A1)
unnamed: J1.30 (BUS2:9), U11.17 (Y2), U17.3 (A2)
unnamed: J1.31 (BUS2:A), U11.16 (Y3), U17.4 (A3)
unnamed: J1.32 (BUS2:B), U11.15 (Y4), U17.5 (A4)
unnamed: J1.33 (BUS2:C), U11.14 (Y5), U17.6 (A5)
unnamed: J1.34 (BUS2:D), U11.13 (Y6), U17.7 (A6)
unnamed: J1.35 (BUS2:E), U11.12 (Y7), U17.8 (A7)
unnamed: J1.36 (BUS2:F), U11.11 (Y8), U17.9 (A8)
unnamed: J1.65 (Sup), U18.4, U18.5
unnamed: J2.1, U18.6
unnamed: R1.2, SW1.8, U4.1, U5.1
unnamed: R2.2, SW1.7, U4.4, U5.4
unnamed: R3.2, SW1.6, U4.9, U5.9
unnamed: R4.2, SW1.5, U4.12, U5.12
unnamed: R7.2, SW2.8, U12.1, U13.1
unnamed: R8.2, SW2.7, U12.4, U13.4
unnamed: R9.2, SW2.6, U12.9, U13.9
unnamed: R10.2, SW2.5, U12.12, U13.12
unnamed: U1.2 (A1), U2.27 (to_Bus0), U10.2 (A1)
unnamed: U1.3 (A2), U2.28 (to_Bus1), U10.3 (A2)
unnamed: U1.4 (A3), U2.29 (to_Bus2), U10.4 (A3)
unnamed: U1.5 (A4), U2.30 (to_Bus3), U10.5 (A4)
unnamed: U1.6 (A5), U2.31 (to_Bus4), U10.6 (A5)
unnamed: U1.7 (A6), U2.32 (to_Bus5), U10.7 (A6)
unnamed: U1.8 (A7), U2.33 (to_Bus6), U10.8 (A7)
unnamed: U1.9 (A8), U2.34 (to_Bus7), U10.9 (A8)
unnamed: U2.1 (Mode_R0), U20.4 (Qa)
unnamed: U2.2 (Mode_R1), U20.7 (Qb)
unnamed: U2.3 (Mode_R2), U20.12 (Qc)
unnamed: U2.4 (Mode_W0), U21.4 (Qa)
unnamed: U2.5 (Mode_W1), U21.7 (Qb)
unnamed: U2.6 (Mode_W2), U21.12 (Qc)
unnamed: U4.3, U6.1
unnamed: U4.6, U6.2
unnamed: U4.8, U7.9
unnamed: U4.11, U7.10
unnamed: U5.3, U7.1
unnamed: U5.6, U7.2
unnamed: U5.8, U6.4
unnamed: U5.11, U6.5
unnamed: U6.3, U7.4
unnamed: U6.9, U7.3
unnamed: U6.6, U6.10
unnamed: U7.5, U7.8
unnamed: U2.35 (to_Bus8), U3.2 (A1), U11.2 (A1)
unnamed: U2.36 (to_Bus9), U3.3 (A2), U11.3 (A2)
unnamed: U2.37 (to_Bus10), U3.4 (A3), U11.4 (A3)
unnamed: U2.38 (to_Bus11), U3.5 (A4), U11.5 (A4)
unnamed: U2.39 (to_Bus12), U3.6 (A5), U11.6 (A5)
unnamed: U2.40 (to_Bus13), U3.7 (A6), U11.7 (A6)
unnamed: U2.41 (to_Bus14), U3.8 (A7), U11.8 (A7)
unnamed: U2.42 (to_Bus15), U3.9 (A8), U11.9 (A8)
unnamed: U12.3, U15.1
unnamed: U12.6, U15.2
unnamed: U12.8, U16.9
unnamed: U12.11, U16.10
unnamed: U13.3, U16.1
unnamed: U13.6, U16.2
unnamed: U13.8, U15.4
unnamed: U13.11, U15.5
unnamed: U2.18 (from_Bus7), U8.11 (Y8), U14.11 (Y8)
unnamed: U2.17 (from_Bus6), U8.12 (Y7), U14.12 (Y7)
unnamed: U2.16 (from_Bus5), U8.13 (Y6), U14.13 (Y6)
unnamed: U2.15 (from_Bus4), U8.14 (Y5), U14.14 (Y5)
unnamed: U2.14 (from_Bus3), U8.15 (Y4), U14.15 (Y4)
unnamed: U2.13 (from_Bus2), U8.16 (Y3), U14.16 (Y3)
unnamed: U2.12 (from_Bus1), U8.17 (Y2), U14.17 (Y2)
unnamed: U2.11 (from_Bus0), U8.18 (Y1), U14.18 (Y1)
unnamed: U15.3, U16.4
unnamed: U15.8, U22.9
unnamed: U15.9, U16.3
unnamed: U15.6, U15.10
unnamed: U16.5, U16.8
unnamed: U16.6, U22.12
unnamed: U2.26 (from_Bus15), U9.11 (Y8), U17.11 (Y8)
unnamed: U2.25 (from_Bus14), U9.12 (Y7), U17.12 (Y7)
unnamed: U2.24 (from_Bus13), U9.13 (Y6), U17.13 (Y6)
unnamed: U2.23 (from_Bus12), U9.14 (Y5), U17.14 (Y5)
unnamed: U2.22 (from_Bus11), U9.15 (Y4), U17.15 (Y4)
unnamed: U2.21 (from_Bus10), U9.16 (Y3), U17.16 (Y3)
unnamed: U2.20 (from_Bus9), U9.17 (Y2), U17.17 (Y2)
unnamed: U2.19 (from_Bus8), U9.18 (Y1), U17.18 (Y1)
unnamed: U6.11, U18.1, U18.2
unnamed: U2.9 (WE), U18.3, U19.1, U19.4
unnamed: U2.10 (RE), U18.8
unnamed: U7.11, U18.9, U18.10
unnamed: U6.8, U22.1
unnamed: U7.6, U22.4

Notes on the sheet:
Mode-Router
Data-Routing
Write-Enable-Detection
Read-Enable-Dection


Board: 2 copper layers, 199.4 x 101.9 mm, 50 parts (0 on the bottom side), 155 nets.

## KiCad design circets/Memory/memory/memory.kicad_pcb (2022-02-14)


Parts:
C1, C2, C3: 0.1µF; C_Disc_D8.0mm_W5.0mm_P5.00mm
D1, D2, D3: LED; LED_D5.0mm
J1: Bus_Connector; PinHeader_1x78_P2.54mm_Horizontal
J2: Bank_Controller_Enable_Out; PinSocket_1x02_P2.54mm_Horizontal
J3: A_Bank_Out; PinSocket_1x16_P2.54mm_Horizontal
J4: D_Bank_IO; PinSocket_1x16_P2.54mm_Horizontal
R1, R2, R3: 220; R_Axial_DIN0309_L9.0mm_D3.2mm_P2.54mm_Vertical
U1, U2: 74LS00; DIP-14_W7.62mm_Socket
U3: 74LS139; DIP-16_W7.62mm_Socket
U4: AM-Connector; PinHeader_1x42_P2.54mm_Horizontal
U5, U6: 74HC573; DIP-20_W7.62mm_Socket
U9, U11: 28C256; DIP-28_W15.24mm_Socket
U10, U12: AS6C62256-55PCN; DIP-28_W15.24mm_Socket

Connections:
+5V: C1.1, C2.1, C3.1, J1.2 (Vcc), U1.14 (VCC), U2.7 (GND), U3.16 (VCC), U5.20 (VCC), U6.20 (VCC), U9.27 (~WE), U9.28 (VCC), U10.28 (Vcc), U11.27 (~WE), U11.28 (VCC), U12.28 (Vcc)
/Addr0: J1.21 (BUS2:0), J3.1, U3.3 (A1), U9.10 (A0), U10.10 (A0), U11.10 (A0), U12.10 (A0)
/Addr1: J1.22 (BUS2:1), J3.2, U3.2 (A0), U9.9 (A1), U10.9 (A1), U11.9 (A1), U12.9 (A1)
/Addr2: J1.23 (BUS2:2), J3.3, U9.8 (A2), U10.8 (A2), U11.8 (A2), U12.8 (A2)
/Addr3: J1.24 (BUS2:3), J3.4, U9.7 (A3), U10.7 (A3), U11.7 (A3), U12.7 (A3)
/Addr4: J1.25 (BUS2:4), J3.5, U9.6 (A4), U10.6 (A4), U11.6 (A4), U12.6 (A4)
/Addr5: J1.26 (BUS2:5), J3.6, U9.5 (A5), U10.5 (A5), U11.5 (A5), U12.5 (A5)
/Addr6: J1.27 (BUS2:6), J3.7, U9.4 (A6), U10.4 (A6), U11.4 (A6), U12.4 (A6)
/Addr7: J1.28 (BUS2:7), J3.8, U9.3 (A7), U10.3 (A7), U11.3 (A7), U12.3 (A7)
/Addr8: J1.29 (BUS2:8), J3.9, U9.25 (A8), U10.25 (A8), U11.25 (A8), U12.25 (A8)
/Addr9: J1.30 (BUS2:9), J3.10, U9.24 (A9), U10.24 (A9), U11.24 (A9), U12.24 (A9)
/Addr10: J1.31 (BUS2:A), J3.11, U9.21 (A10), U10.21 (A10), U11.21 (A10), U12.21 (A10)
/Addr11: J1.32 (BUS2:B), J3.12, U9.23 (A11), U10.23 (A11), U11.23 (A11), U12.23 (A11)
/Addr12: J1.33 (BUS2:C), J3.13, U9.2 (A12), U10.2 (A12), U11.2 (A12), U12.2 (A12)
/Addr13: J1.34 (BUS2:D), J3.14, U9.26 (A13), U10.26 (A13), U11.26 (A13), U12.26 (A13)
/Addr14: J1.35 (BUS2:E), J3.15
/Addr15: J1.36 (BUS2:F), J3.16
/Bus_D0: J1.5 (BUS1:0), U5.2 (1D)
/Bus_D1: J1.6 (BUS1:1), U5.3 (2D)
/Bus_D2: J1.7 (BUS1:2), U5.4 (3D)
/Bus_D3: J1.8 (BUS1:3), U5.5 (4D)
/Bus_D4: J1.9 (BUS1:4), U5.6 (5D)
/Bus_D5: J1.10 (BUS1:5), U5.7 (6D)
/Bus_D6: J1.11 (BUS1:6), U5.8 (7D)
/Bus_D7: J1.12 (BUS1:7), U5.9 (8D)
/Bus_D8: J1.13 (BUS1:8), U6.2 (1D)
/Bus_D9: J1.14 (BUS1:9), U6.3 (2D)
/Bus_D10: J1.15 (BUS1:A), U6.4 (3D)
/Bus_D11: J1.16 (BUS1:B), U6.5 (4D)
/Bus_D12: J1.17 (BUS1:C), U6.6 (5D)
/Bus_D13: J1.18 (BUS1:D), U6.7 (6D)
/Bus_D14: J1.19 (BUS1:E), U6.8 (7D)
/Bus_D15: J1.20 (BUS1:F), U6.9 (8D)
/CLK_R: J1.3 (CLK_R), U5.11 (LE), U6.11 (LE)
/Data0: J4.16, U4.27 (to_Bus0), U5.19 (1Q), U9.11 (D0), U10.11 (DQ0)
/Data1: J4.15, U4.28 (to_Bus1), U5.18 (2Q), U9.12 (D1), U10.12 (DQ1)
/Data2: J4.14, U4.29 (to_Bus2), U5.17 (3Q), U9.13 (D2), U10.13 (DQ2)
/Data3: J4.13, U4.30 (to_Bus3), U5.16 (4Q), U9.15 (D3), U10.15 (DQ3)
/Data4: J4.12, U4.31 (to_Bus4), U5.15 (5Q), U9.16 (D4), U10.16 (DQ4)
/Data5: J4.11, U4.32 (to_Bus5), U5.14 (6Q), U9.17 (D5), U10.17 (DQ5)
/Data6: J4.10, U4.33 (to_Bus6), U5.13 (7Q), U9.18 (D6), U10.18 (DQ6)
/Data7: J4.9, U4.34 (to_Bus7), U5.12 (8Q), U9.19 (D7), U10.19 (DQ7)
/Data8: J4.8, U4.35 (to_Bus8), U6.19 (1Q), U11.11 (D0), U12.11 (DQ0)
/Data9: J4.7, U4.36 (to_Bus9), U6.18 (2Q), U11.12 (D1), U12.12 (DQ1)
/Data10: J4.6, U4.37 (to_Bus10), U6.17 (3Q), U11.13 (D2), U12.13 (DQ2)
/Data11: J4.5, U4.38 (to_Bus11), U6.16 (4Q), U11.15 (D3), U12.15 (DQ3)
/Data12: J4.4, U4.39 (to_Bus12), U6.15 (5Q), U11.16 (D4), U12.16 (DQ4)
/Data13: J4.3, U4.40 (to_Bus13), U6.14 (6Q), U11.17 (D5), U12.17 (DQ5)
/Data14: J4.2, U4.41 (to_Bus14), U6.13 (7Q), U11.18 (D6), U12.18 (DQ6)
/Data15: J4.1, U4.42 (to_Bus15), U6.12 (8Q), U11.19 (D7), U12.19 (DQ7)
/RE: J2.2, U2.4, U2.9, U4.10 (RE)
/RE_RAM: R3.1, U2.6, U10.22 (~OE), U12.22 (~OE)
/RE_ROM: R2.1, U2.8, U9.22 (~OE), U11.22 (~OE)
/SUP: J1.65 (Sup), U1.12, U1.13
/WE: J2.1, U1.9, U1.10, U2.13, U4.9 (WE)
/WE_F: U2.2, U4.8 (WE_F)
/WE_RAM: U2.3, U10.27 (~WE), U12.27 (~WE)
/~WE: U1.8, U5.1 (~OE), U6.1 (~OE)
GND: C1.2, C2.2, C3.2, D1.1 (K), D2.1 (K), D3.1 (K), J1.1 (GND), U1.7 (GND), U2.14 (VCC), U3.8 (GND), U5.10 (GND), U6.10 (GND), U9.1 (A14), U9.14 (GND), U9.20 (~CS), U10.1 (A14), U10.14 (Vss), U10.20 (~CE), U11.1 (A14), U11.14 (GND), U11.20 (~CS), U12.1 (A14), U12.14 (Vss), U12.20 (~CE)
unnamed: D1.2 (A), R1.2
unnamed: D2.2 (A), R2.2
unnamed: D3.2 (A), R3.2
unnamed: U1.1, U1.2, U3.5 (O1)
unnamed: U1.3, U2.1, U2.5, U2.12
unnamed: U1.4, U1.5, U3.4 (O0)
unnamed: U1.6, U2.10
unnamed: U1.11, U3.1 (E)
unnamed: R1.1, U2.11

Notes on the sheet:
D_In
A_In

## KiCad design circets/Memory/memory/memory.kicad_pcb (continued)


Board: 2 copper layers, 152.0 x 199.5 mm, 23 parts (1 on the bottom side), 68 nets.

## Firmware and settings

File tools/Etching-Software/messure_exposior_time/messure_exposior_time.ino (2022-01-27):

#include <EEPROM.h>

const int ROM_ADDRESS = 0x0;
const int DELAY = 10000;

void setup() {
  Serial.begin(9600);
  if(analogRead(0) < 10) {
    EEPROM.put(ROM_ADDRESS, 0);
  }
}

void loop() {
  unsigned int time_passed;
  EEPROM.get(ROM_ADDRESS, time_passed);
  if(analogRead(0) < 10) {
    EEPROM.put(ROM_ADDRESS, time_passed + (DELAY / 1000));
  }
  Serial.print("Last Time passed: ");
  Serial.println(time_passed);
  delay(DELAY);  
}

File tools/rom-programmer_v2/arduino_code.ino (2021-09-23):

#define ADDRESS_LOW 6
#define ADDRESS_HIGH 7
#define DATA 8
#define CLOCK 4
#define CLEAR 3
#define WRITE_ENABLE_ROM 9
#define STATUS 13

#define DELAY 1

void writeData(short address, byte data) {
  digitalWrite(CLEAR, LOW);
  delay(DELAY);
  digitalWrite(CLEAR, HIGH);
  delay(DELAY);
  for(int i=0; i<8; i++) {
     digitalWrite(ADDRESS_LOW, (address >> (7-i)) & 1);
     digitalWrite(ADDRESS_HIGH, (address >> (7-i + 8)) & 1);
     digitalWrite(DATA, (data >> (7-i)) & 1);
     digitalWrite(CLOCK, HIGH);
     delay(DELAY);
     digitalWrite(CLOCK, LOW);
     delay(DELAY);
  }  

  digitalWrite(WRITE_ENABLE_ROM, HIGH);
  delay(DELAY);
  digitalWrite(WRITE_ENABLE_ROM, LOW);
  delay(DELAY);
}

void setup() {
  pinMode(ADDRESS_LOW, OUTPUT);
  pinMode(ADDRESS_HIGH, OUTPUT);
  pinMode(DATA, OUTPUT);
  pinMode(CLOCK, OUTPUT);
  pinMode(CLEAR, OUTPUT);
  pinMode(WRITE_ENABLE_ROM, OUTPUT);
  pinMode(STATUS, OUTPUT); 

  digitalWrite(CLEAR, HIGH); // CLR is inverted
  Serial.begin(9600);
  writeData(0xffff, 0xff);
}

void loop() {
  while(Serial.available() == 0) {}
  byte data[32];
  Serial.readBytes(data, 3);
  //digitalWrite(STATUS, HIGH);

  short address = data[1] + (data[0] << 8);
  short length = data[2];

  Serial.readBytes((char*)&data, length);
  //digitalWrite(STATUS, LOW);

  for(int i=0; i<length; i++) {
    writeData(address, data[i]);
    address++;
  }

  delay(DELAY);
  Serial.write('\xff');
}

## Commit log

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2020-08-11 Added Partindex
    [index_parts.xlsx]
2021-02-17 Replaced excel with LibraCalc
    [index_parts.ods, index_parts.xlsx]
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2021-07-15 Did stuff lol
    [Memory.fzz, TEST.fzz, Untitled Sketch 2.fzz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]
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2021-09-18 Restructured Repository!
    [Memory.fzz, TEST.fzz, Untitled Sketch 2.fzz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]
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2021-10-02 Reworked Interrupts
2021-10-05 don't have any clue what changed in this FIle, because I only copied a link from it, but I don't care...
    [index_parts.ods]
2021-10-05 Added XOR-, OR- and AND- Gates to parts index
    [index_parts.ods]
2021-10-07 Minor Fixes + Defaults for 2 and 3 probes
    [get_messurments.py]
2021-10-14 Update Parts index with XOR, OR and AND
    [index_parts.ods]
2021-10-14 Fixed Line formating
    [index_parts.ods]
2021-10-30 Added FLASH and SMD to DIP Adapter to part index
    [index_parts.ods]
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2021-11-16 Added no ploting option and fixed bug with displaying delays
    [analyse_propagation_delay.py]
2021-11-16 Added delays to part index
    [index_parts_pd.ods]
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2021-11-18 Corrections, Added Supvisor comment, rewrote Interrupts, restructured
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2021-11-18 Added Test PCB-Layout
    [not-gate.fzz]
2021-11-18 Added Table for Recording PCB manufacturing
    [PCB_Data.ods]
2021-11-22 Reset all assembler files
2021-12-03 Added 3 PCB-etching-test
    [PCB_Data.ods]
2021-12-06 Did Stuff, don't know, edit this shit ~2 weeks ago
    [Not-Gate-NPN.kicad_pcb, Not-Gate-NPN.sch]
2021-12-06 Added New Datapoints to PCB etching!
    [PCB_Data.ods]
2021-12-06 Fixed wrong connection in test circet
    [not-gate.fzz]
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2021-12-06 Added first drawing of the Register file
    [register_file_kicad.kicad_pcb, register_file_kicad.sch]
2021-12-08 Build new framework for testing PD and other stuff
    [sample_0.csv]
2021-12-09 Added NAND-PD-Tests and Programmer Manual
    [sample_0.csv, sample_1.csv, sample_10.csv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]
2021-12-09 Build Schematics for AM
    [Activation_Module.kicad_pcb, Activation_Module.sch]
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2021-12-16 Started Rework on AM
    [Activation_Module.sch]
2021-12-17 Updated PCB-Dataset with old test
    [PCB_Data.ods]
2021-12-18 Revised Activation Module
    [Activation_Module.sch]
2021-12-19 Added Multiplexers to Part index
    [index_parts.ods]
2021-12-19 Fixed Small Issues after build Protype
    [Activation_Module.sch]
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2021-12-21 Added Pin Headers to part index
    [index_parts.ods]
2021-12-21 Made Footprint for 74HC541 and started Footprint for Bus Connector
    [Activation_Module.sch]
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2021-12-26 Transfored Repo to new computer, alot has apperntly chande, let's commit it all!
    [Activation_Module.sch, register_file_kicad.sch]
2021-12-27 fixing my pull issues
    [ALU.kicad_pcb, ALU.sch]
2021-12-27 Reworked Register Logic-Schematic and Kicad-Schematic
    [register_file_kicad.sch]
2021-12-27 Added Decoder to part index
    [index_parts.ods]
2021-12-28 Cleand up circet folder
    [Activation_Module.kicad_pcb, Activation_Module.sch, Not-Gate-NPN.kicad_pcb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]
2021-12-28 Fixed Issue with wrong pins in activation Module!
    [Activation_Module.sch, register_file_kicad.sch]
2021-12-28 Adjusted Prices for Full Addre in part index
    [index_parts.ods]
2021-12-28 Build Logic Schematic for Bank, Bank Controller and BID-Register
    [index_parts.ods]
2021-12-30 Build Schematic for Timer
    [index_parts.ods]
2022-01-01 Minor Correction for Timed Interrupt and comment on it
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2022-01-02 Build Schematic for Memory
    [memory.kicad_pcb, memory.sch]
2022-01-02 Schamtic for Bank Modules
    [Bank_Module_x2.kicad_pcb, Bank_Module_x2.sch, Bank_Module_x4.kicad_pcb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]
2022-01-02 Build Schematics for Bank Controller + minor optimaization to eliminat a NAND from Bank Modules
    [Bank_Controller.kicad_pcb, Bank_Controller.sch, Bank_Module_x2.sch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]
2022-01-04 Started Building Assembler; Need an clear schceam for encoding instructions
    [index_parts.ods]
2022-01-04 Fixed alot of Issues in Memory Module
    [Bank_Controller.sch, Bank_Module_x2.sch, Bank_Module_x4.sch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]
2022-01-04 Removed BID Register to Replace with Dual Register
    [memory.sch]
2022-01-05 Added correct connectors to AM
    [Activation_Module.sch]
2022-01-05 Build Schematic for Dual Register
    [dual_register.kicad_pcb, dual_register.sch]
2022-01-08 addet Pictures (with issues)
    [Desighn_Overview.blend]
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2022-01-10 some progress with the Langfassung (now with 12 Pages)
    [PCB_Data.ods]
2022-01-12 Build PCB Layout for dual Register
    [dual_register.sch]
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2022-01-16 trust me I'm a engieener wtf just happend here!
    [index_parts.ods]
2022-01-16 Started Creating Activation Module PCB
    [Activation_Module.kicad_pcb, Activation_Module.sch]
2022-01-16 I don't have a fucking clue what these file have to do with my projekt, but git prevents me from getting my job done if I don'T commit these files, so I guess... let's do it
    [dual_register.kicad_pcb]
2022-01-19 First real attempt to etch a PCB
    [PCB_Data.ods]
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2022-01-25 Update Kicad to version 6 (and all of the schematics)
    [Activation_Module.kicad_pcb, Activation_Module.kicad_sch, dual_register.kicad_pcb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]
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2022-01-25 Added Transiver and PCB-Base Material to Part Index
    [index_parts.ods]
2022-01-27 Reworked PCB Layout for Dual Register
    [dual_register.kicad_pcb, dual_register.kicad_sch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]
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2022-01-27 Futher Advanced Progress in build PCB Layout for AM
    [Activation_Module.kicad_pcb, Activation_Module.kicad_sch]
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2022-02-04 Renamed Schematics to prevent logisim from complaiing about filenames
2022-02-04 Chanced *something* in register file schmatic idk
    [register_file_kicad.kicad_sch]
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2022-02-09 Build Register File PCB-Layout
    [register_file_kicad.kicad_pcb, register_file_kicad.kicad_sch]
2022-02-09 Messured PD for Buffer and Octal-D-Latch
    [sample_0.csv, sample_1.csv, sample_10.csv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]
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2022-02-09 Did something to part index
    [index_parts.ods]
2022-02-12 RedesignedPCB Layout for Activation Module
    [Activation_Module-B_Cu.gbl, Activation_Module-B_Mask.gbs, Activation_Module-B_Paste.gbp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]
2022-02-12 Did **Something** to the file by apperently not editing it, idk
    [register_file_kicad.kicad_pcb]
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2022-02-14 Build PCB Layout for Memory Module
    [memory-B_Cu.gbr, memory-B_Mask.gbr, memory-B_Paste.gbr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]
2022-02-14 Added gerber files to Activation Module and corrected PinHeader
    [Activation_Module-B_Cu.gbl, Activation_Module-B_Mask.gbs, Activation_Module-B_Paste.gbp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]
2022-02-14 Added Name to Module and Removed old schematic pdfs
    [memory-B_Cu.gbr, memory-B_Mask.gbr, memory-B_Paste.gbr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]
2022-02-14 Added Name and other notest to AM PCB-Layout
    [Activation_Module-B_Cu.gbl, Activation_Module-B_Mask.gbs, Activation_Module-B_Paste.gbp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]
2022-02-16 Added Siwas Register File PCB + compleateted it!
    [register_file_kicad-B_Cu.gbr, register_file_kicad-B_Mask.gbr, register_file_kicad-B_Paste.gbr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]
2022-02-16 fixed all design-issues in register_file
    [register_file_kicad.kicad_pcb, register_file_kicad.sch]
2022-02-21 Changed Label on Register File
    [register_file_kicad-B_Cu.gbr, register_file_kicad-B_Mask.gbr, register_file_kicad-B_Paste.gbr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]
2022-05-05 Build Small SMD Test Circet
    [PCB_test_layout.kicad_pcb, PCB_test_layout.kicad_sch]

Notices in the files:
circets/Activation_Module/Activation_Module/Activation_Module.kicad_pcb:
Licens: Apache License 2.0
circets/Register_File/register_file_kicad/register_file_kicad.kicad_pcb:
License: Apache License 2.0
